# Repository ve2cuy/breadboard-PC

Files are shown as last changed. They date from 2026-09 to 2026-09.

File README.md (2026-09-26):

# breadboard-PC — an 8088 computer on a breadboard

A microcomputer with a PC/XT-inspired architecture, built on solderless breadboards around an
**Intel 8088**. Its ROM, whose source code is **written entirely in 8086 assembly language**, boots
into an interactive menu, runs two BASIC interpreters and **boots PC-DOS 2.1 and MS-DOS 3.30** from
floppy disk images.

A project by Alain Boudreault (VE2CUY), 2026. *[Version française](README_fr.md)*

<p align="center">
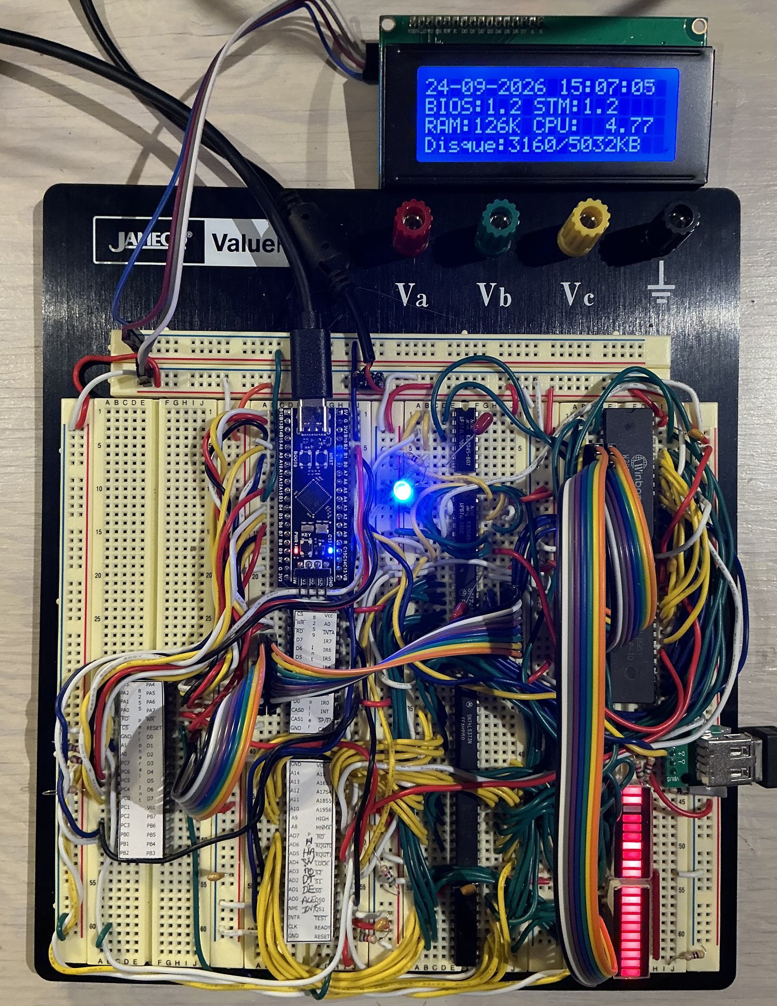
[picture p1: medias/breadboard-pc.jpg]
The breadboard build, with the LCD showing the Information screen
  <br>
  <em>The build: the Black Pill STM32F411 bridge (top centre), the 8088, the 8255, the 8259, the ROM and
  the RAM. The LCD shows the “Information” screen (date and time, versions, RAM, disk, speed).</em>
</p>

## At a glance

| | |
|---|---|
| **Processor** | Intel 8088, 4.77 MHz by default (adjustable from 1 to 10 MHz) |
| **Memory** | 256 KB ROM (W29C020C, `C0000h`–`FFFFFh`), 128 KB static RAM (HM628128, `00000h`–`1FFFFh`) |
| **I/O** | 8255A in mode 2 (bus to the bridge), 8259A (interrupts), 4×20 I2C LCD, PS/2 keyboard |
| **Bridge** | WeAct **Black Pill STM32F411** board: keyboard, USB terminal, LCD, clock, disk, RESET |
| **Software** | ROM written entirely in assembly (NASM, strict 8086 instruction set), both BASICs included: menu, BIOS for DOS, Tiny BASIC, GW-BASIC-style BASIC |
| **Operating systems** | PC-DOS 2.1 and MS-DOS 3.30, booted from a floppy disk image |

## The build

The core of the machine (processor, address latches, ROM, RAM, decoding) is wired on breadboards
with 74HC/74HCT logic and no programmable logic (no GAL, no CPLD). Address decoding takes only a few
NAND gates:

- **ROM**: `A19 = 1` (window `C0000h`–`FFFFFh`);
- **RAM**: `A19 = 0`;
- **8255** (ports `80h`–`83h`): `A7` and an I/O cycle;
- **8259** (ports `20h`–`21h`): `NAND(IO, A5)` (one gate of a 74LS00).

<p align="center">
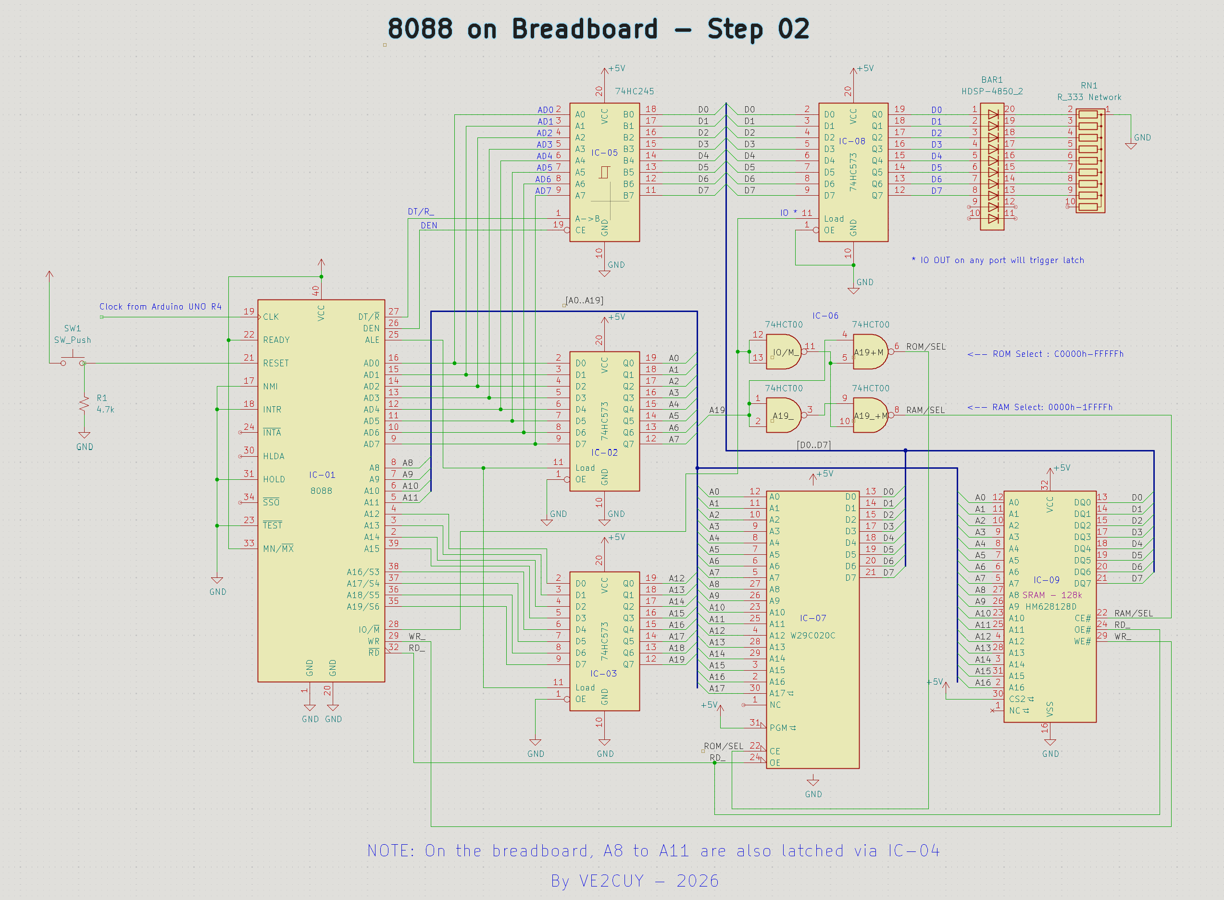
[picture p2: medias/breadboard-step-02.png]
KiCad schematic of the core: 8088, latches, ROM, RAM and decoding
  <br>
  <em>Schematic of the core (KiCad). The clock, supplied here by an Arduino UNO R4, now comes from the bridge.</em>
</p>

## The circuit

The 8088 does not bit-bang any peripheral. All traffic goes through **a single 8255 in mode 2**: an
8-bit bidirectional bus with hardware handshaking, connected to the bridge. Every byte received from
the bridge raises an interrupt (`IR1` of the 8259).

```mermaid
flowchart LR
    CPU["Intel 8088"] --- BUS(("Bus<br>A0-A19 / D0-D7"))
    BUS --- ROM["256 KB ROM<br>W29C020C"]
    BUS --- RAM["128 KB RAM<br>HM628128"]
    BUS --- PIO["8255A<br>mode 2"]
    BUS --- PIC["8259A"]
    PIO -- "INTR → IR1" --> PIC
    PIC -- INTR --> CPU
    PIO <== "Port A (8 bits) + handshake" ==> BRIDGE["Bridge<br>Black Pill STM32F411"]
    BRIDGE -- "CLK, RESET" --> CPU
    KBD["PS/2 keyboard"] --> BRIDGE
    BRIDGE <-- "USB (serial + drive)" --> PC["PC: terminal"]
    BRIDGE --> LCD["4×20 I2C LCD"]
    BRIDGE --- FLASH["8 MB flash<br>FAT16"]
```

The bridge wiring in detail (pins, 3.3 V / 5 V levels, pull-up resistors) is described (in French) in
[arduino/8088_bridge_stm32/README.md](arduino/8088_bridge_stm32/README.md).

## The STM32 bridge

The bridge firmware (a PlatformIO project, [arduino/8088_bridge_stm32](arduino/8088_bridge_stm32))
gives the 8088 the peripherals of a PC:

| Function | Details |
|---|---|
| **PS/2 keyboard** | Frame decoding; raw scan codes passed to the 8088 |
| **Terminal** | Native USB serial port to the PC (ANSI, 80 columns) |
| **Display** | 4×20 HD44780 LCD over I2C (PCF8574) |
| **Real-time clock** | STM32 RTC (32.768 kHz crystal): `TIME$`, `DATE$`, `INT 1Ah` |
| **Disk** | 8 MB W25Q64 SPI flash formatted FAT16: files, sectors, floppy images mounted as A: |
| **USB drive** | The flash is exposed to the PC as a USB drive (`USB ON` / `USB OFF`) to copy files onto it |
| **8088 clock** | `CLK` signal generated by hardware PWM, 1 to 10 MHz |
| **8088 RESET** | Held while the bridge starts up; **Ctrl-Alt-Del** (PS/2) or **Ctrl-\\** (terminal) |

The 8088 talks to the bridge through a command protocol on a dedicated channel
(see [Solution-01/lib/bridge.asm](Solution-01/lib/bridge.asm)).

## The menu

At power-up, the ROM displays a menu on both the terminal and the LCD. It can be driven from either
the PS/2 keyboard or the terminal; **Esc** returns to the main menu.

<p align="center">
  The ROM main menu on the terminal
</p>

| Menu | Options |
|---|---|
| **1) Basic** | Tiny BASIC; GW-BASIC-style BASIC |
| **2) Memory functions** | Memory dump and editing, CPU registers, code entry and execution, interrupt vector table, RAM test |
| **3) USB Disk** | USB drive toggle, file list, **booting a disk image** |
| **4) Configuration** | Clock speed, CPU speed test, date and time setting, information screen |

## BASIC

An original reimplementation inspired by GW-BASIC: same keywords, same error messages, integers,
single-precision floating point (in software) and strings. About 54 KB are free for programs.

<p align="center">
  BASIC session: a program, RUN and FRE(0)
</p>

| Category | Commands and functions |
|---|---|
| **Program** | `RUN` `LIST` `EDIT` `DELETE` `NEW` `CLEAR` `CONT` `TRON` `TROFF` `HELP` `SYSTEM` |
| **Control flow** | `IF…THEN…ELSE` `GOTO` `GOSUB`/`RETURN` `ON…GOTO/GOSUB` `FOR…NEXT` `WHILE…WEND` `END` `STOP` |
| **Data** | `LET` `DIM` `ERASE` `SWAP` `DATA`/`READ`/`RESTORE` `DEF FN` `DEFINT`/`DEFSNG`/`DEFSTR` |
| **Input/output** | `PRINT` `INPUT` `LINE INPUT` `INKEY$` `CLS` `LOCATE` `COLOR` `BEEP` |
| **Math** | `ABS` `SGN` `INT` `FIX` `SQR` `SIN` `COS` `TAN` `ATN` `LOG` `EXP` `RND` `RANDOMIZE` |
| **Strings** | `LEN` `LEFT$` `RIGHT$` `MID$` `INSTR` `CHR$` `ASC` `STR$` `VAL` `HEX$` `UCASE$` `STRING$` |
| **Files** | `SAVE` `LOAD` `MERGE` `FILES` `KILL` `FORMAT`; `OPEN` `PRINT #` `INPUT #` `EOF` `CLOSE` |
| **Clock** | `TIMER` `TIME$` `DATE$` (read and set the bridge RTC) |
| **Machine** | `PEEK` `POKE` `DEF SEG` `INP` `OUT` `WAIT` `CALL` `FRE` |
| **Disk and system** | `DSKREAD` `DSKWRITE` `USB ON`/`OFF` `BOOT "image.img"` |

## DOS 2.1 and DOS 3.3

The ROM provides the BIOS layer a DOS expects: disk (`INT 13h`, CHS and LBA), keyboard (`INT 16h`),
clock (`INT 1Ah`), text output to the terminal (`INT 10h`) and bootstrap (`INT 19h`). A floppy image
copied to the flash (through the USB drive) is mounted as drive **A:** and booted from
**USB Disk → 3) Boot disk image**, or with `BOOT "PCDOS2_1.IMG"` from BASIC. DOS writes go to the
image file.

<p align="center">
  Booting PC-DOS 2.1, VER and DIR /W<br>
  <em>PC-DOS 2.1: booting from the image (one dot per sector read), VER, DIR /W</em>
</p>

<p align="center">
  Booting MS-DOS 3.30, VER and DIR /W<br>
  <em>MS-DOS 3.30</em>
</p>

Limitations: 128 KB of RAM (DOS 5.0 and later require 256 KB), no video hardware (programs that write
to video memory display nothing), DOS keyboard input from the terminal only.

## Building the ROM

```sh
cd Solution-01
make            # solution-01.bin (256 KB, to be burned into the W29C020C); make rom-en for English
make check      # checks size, reset vector and signature
make test       # test benches under emulation (Unicorn)
make test-rom   # full ROM simulation: DOS, BASIC, PS/2 keyboard
```

Tools: NASM, GNU Make, Python 3 (+ `unicorn` for the tests); PlatformIO for the bridge
(`platformio run -e blackpill_f411ce_usbdrive -t upload`, board in DFU mode).

## Repository layout

| Folder | Contents |
|---|---|
| [Solution-01/](Solution-01) | 8088 ROM (NASM) and tests; full technical documentation (in French) in [Solution-01/README.md](Solution-01/README.md) |
| [arduino/8088_bridge_stm32/](arduino/8088_bridge_stm32) | Firmware of the Black Pill STM32F411 bridge (PlatformIO) |
| [kicad/](kicad) | Schematics of the build |
| [PC-DOS/](PC-DOS) | Test floppy disk images |
| [medias/](medias) | Datasheets, schematics and screenshots |

> The terminal screenshots on this page are produced by the actual (English) ROM, running in the
> project's simulator ([medias/captures/generer.py](medias/captures/generer.py)).

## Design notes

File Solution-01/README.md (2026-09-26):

# Solution-01 — 8088/8086 sur breadboard (VE2CUY)

Firmware ROM pour un ordinateur 8088/8086 assemblé sur breadboard par
Alain Boudreault (VE2CUY). Au démarrage, la carte :

1. affiche un écran de démarrage sur le LCD I2C 4×20 pendant 1 seconde ;
2. affiche un **menu interactif** (UART + LCD I2C), piloté au **clavier
   PS/2 ou au terminal UART du PC** (les deux sont équivalents), qui
   reste le comportement normal de la carte tant qu'elle est sous
   tension — voir [Menu interactif](#menu-interactif) ci-dessous pour
   la structure complète.

**Architecture « pont »** : le 8088 ne pilote plus aucun périphérique
en bit-bang. Une plaquette **WeAct Black Pill V3.1 (STM32F411)** — le
**pont** — décode le clavier PS/2, présente au PC un port série par son
USB natif et possède le bus I2C du LCD, la RTC, le disque (flash SPI de
8 Mo), l'horloge et le RESET du 8088 ; le 8088 ne lui
parle que par **un 8255 en mode 2** (un seul bus de 8 bits
bidirectionnel avec poignée de main matérielle) et reçoit ses octets par
une **interruption matérielle** du 8259 — voir
[Pont STM32](#pont-stm32-8255-en-mode-2). Le firmware du pont est le
projet PlatformIO `../arduino/8088_bridge_stm32/` (dépôt Git, à côté de
`Solution-01/`). À l'origine, le pont était un **Arduino UNO**
(`../arduino/ve2cuy_bridge/`, conservé pour l'historique ; même protocole
côté 8088, mais sans RTC, disque, horloge ni RESET) — d'où le nom du
dossier `arduino/` et de quelques identifiants du firmware (`arduino_send`,
`irq1_arduino_handler`, `ARD_*`).

⚠️ Le pilote du LCD **parallèle** (`lib/lcd.asm`) reste dans le dépôt
(historique) mais plus aucun code du firmware ne l'appelle : il écrirait
sur le Port A, qui est maintenant le bus du pont.

Contrairement aux versions précédentes, il n'y a plus de « power-on
self-test » (POST) qui s'enchaîne automatiquement — chaque test (RAM,
dump ROM/RAM, édition de la RAM, registres, IVT, Tiny BASIC, BASIC) est déclenché
explicitement depuis le menu. Un clavier (PS/2 **ou** terminal UART) est
donc **requis** pour que la carte fasse quoi que ce soit après le
splash.

## Matériel visé

- CPU 8088/8086 (le code est écrit pour être compatible 8086 strict —
  voir `CPU 8086` dans `solution-01.asm` — mais ciblé pour tourner sur
  un vrai 8088)
- ROM 256 Ko, mappée à l'adresse physique `C0000h-FFFFFh`
- RAM statique 128 Ko
- Un **8259A** (contrôleur d'interruptions) : ports `20h`/`21h` (comme le
  PC/XT), `CS#` décodé par une porte NAND (74LS00) sur `IO` et `A5`. `IR0` =
  bouton-poussoir de test, `IR1` = `INTR` du 8255 (octet reçu du
  pont). Détails : [Interruptions matérielles](#interruptions-matérielles-8259)
- Un **8255** (PIO, ports `80h-83h`) en **mode 2** — voir
  [Pont STM32](#pont-stm32-8255-en-mode-2)
- Une plaquette **WeAct Black Pill V3.1** (STM32F411CEU6, 100 MHz, USB
  natif) — le **pont** — qui porte les périphériques :
  - clavier PS/2 (`CLK`/`DATA` sur le pont, **pas** sur le 8255) ;
  - terminal du PC = port série **USB** natif de la plaquette (débit sans
    objet ; ouvrir le port ne réinitialise pas la carte) ;
  - LCD I2C HD44780 4×20 (expandeur PCF8574, adresse `0x27`, ou `0x3F`
    pour un PCF8574A) sur `PB10`/`PB3` (I2C2) ;
  - RTC (quartz LSE de la carte), disque (flash SPI W25Q64 de 8 Mo,
    FAT16), horloge du 8088 (PWM, 1-10 MHz) et RESET du 8088.
- **Câblage pont ↔ 8255/8088** (détails, niveaux 3,3 V / 5 V et
  vérifications : `../arduino/8088_bridge_stm32/README.md`) :

| Black Pill | Signal | Côté 8088 |
|---|---|---|
| `PB12` `PB13` `PB14` `PB15` | bus de données | `PA0` `PA1` `PA2` `PA3` |
| `PB6` `PB7` `PB8` `PB9` | bus de données | `PA4` `PA5` `PA6` `PA7` (quartet haut inversé sur le montage, corrigé en logiciel : `BUS_HIGH_NIBBLE_REVERSED`) |
| `PB0` | `ACK#` (sortie drain ouvert du pont) | `PC6` |
| `PB1` | `STB#` (sortie drain ouvert du pont) | `PC4` |
| `PA8` | `OBF#` (entrée du pont) | `PC7` |
| `PA15` | `IBF` (entrée du pont, facultative : `USE_IBF`) | `PC5` |
| `PB4` | étiquette `TAG` de l'octet envoyé au 8088 | `PC0` (entrée du 8255) |
| `PB5` | étiquette `TAG1` (réponse à une commande) | `PC1` (10 kΩ vers la masse) |
| `PA9` `PA10` | canal de l'octet reçu du 8088 | `PB0` `PB1` |
| `PA3` | horloge (PWM `TIM2` canal 4) | `CLK` (broche 19) du 8088 |
| `PB2` | RESET (actif haut ; entrée au repos) | `RESET` (broche 21) du 8088 |
| `PA1` `PA2` | `CLK` / `DATA` du clavier PS/2 | — |
| `PB3` `PB10` | `SDA` / `SCL` du LCD I2C | — |
| — | `INTR` du 8255 | `PC3` → `IR1` du 8259 |

  `PA11`/`PA12` sont réservées à l'USB. Résistances de tirage : 10 kΩ vers
  +5 V sur `STB#`/`ACK#` (drain ouvert : vrai niveau haut à 5 V, lignes
  hautes pendant un reset ou une reprogrammation du STM32), 4,7-10 kΩ
  vers +5 V sur `CLK`/`DATA` du PS/2. Masse commune avec le 8088.

> **Câblage USB → PS/2** (pour un clavier/câble USB adapté en PS/2) :
> `VBUS`→`+5V`, `D−`→`Data`, `D+`→`Clock`, `GND`→`GND`. Fonctionne avec
> tout clavier USB à repli PS/2 (confirmé sur ce montage) — pas avec
> un clavier USB « pur » sans ce repli.

## Schéma bloc du circuit électronique

Décodage d'adresses (logique simple, sans décodeur dédié — un seul
bit d'adresse suffit à distinguer ROM/RAM, la sélection des circuits
d'E/S se faisant sur le bus d'E/S) :

- **ROM** : `CS = A19`
- **RAM** : `CS = NOT A19`
- **8255 (PIO)** : `CS = A7 AND IO/M` (cycle d'E/S, adresse ≥ 80h —
  `A0`/`A1` vont directement aux broches `A0`/`A1` du 8255 pour
  sélectionner Port A/B/C/registre de commande — voir `PORTA`/`PORTB`/
  `PORTC`/`PIO` dans `include/hardware.inc`, ports 80h-83h)
- **8259 (PIC)** : `CS#` par NAND(`IO`, `A5`) (une porte de 74LS00) — ports `20h`/`21h`

```mermaid
flowchart TD
    subgraph CPU["CPU 8088/8086"]
        AB["Bus d'adresses A0-A19"]
        DB["Bus de donnees D0-D7"]
        IOM["IO/M (cycle E/S vs memoire)"]
    end

    subgraph DEC["Decodage d'adresses"]
        A19G["A19"]
        NOTA19["NOT A19"]
        A7IO["A7 AND IO/M"]
        PICCS["NAND(IO, A5)"]
    end

    subgraph MEM["Memoire"]
        ROM["ROM 256 Ko\nC0000h-FFFFFh\nCS = A19"]
        RAM["RAM statique 128 Ko\n00000h-1FFFFh\nCS = NOT A19"]
    end

    subgraph IOBLK["Entrees/Sorties"]
        PIO["8255 PIO - mode 2\nPorts 80h-83h\nPort A = bus 8 bits bidirectionnel"]
        PIC["8259 PIC\nPorts 20h-21h"]
    end

    ARD["Pont Black Pill STM32F411\n(PS/2, UART USB, LCD I2C,\nRTC, disque, CLK, RESET)"]
    PS2["Clavier PS/2"]
    PC["PC - terminal (port serie USB)"]
    LCD["LCD I2C 4x20\n(PCF8574)"]
    BTN["Bouton-poussoir de test (IR0)"]

    AB --> A19G
    A19G --> NOTA19
    AB --> A7IO
    IOM --> A7IO
    AB --> PICCS
    IOM --> PICCS

    A19G -->|CS| ROM
    NOTA19 -->|CS| RAM
    A7IO -->|CS| PIO
    PICCS -->|CS| PIC

    DB --- ROM
    DB --- RAM
    DB --- PIO
    DB --- PIC

    PIO <-->|"Port A (8 bits), Port B (canal), Port C (poignee de main)"| ARD
    PIO -->|"INTR (PC3)"| PIC
    BTN --> PIC
    PIC -->|INTR| CPU
    PS2 --> ARD
    ARD <--> PC
    ARD --> LCD
```

⚠️ Note : la sélection de la ROM ne dépend que de `A19` (pas de
`A18`) — la ROM physique (256 Ko = `A0-A17`) est donc mise en miroir
sur les 512 Ko de la moitié haute de l'espace mémoire (`80000h-FFFFFh`)
si `A18` n'est câblé nulle part ailleurs ; le firmware n'utilise que
la fenêtre `C0000h-FFFFFh`. Même remarque pour la RAM (128 Ko, moitié
basse de 1 Mo) : seuls `00000h-1FFFFh` sont réellement testés par
`test_ram` (voir `solution-01.asm`).

## Pont STM32 (8255 en mode 2)

Le 8255 est programmé par `init_8255` avec le mot de mode `C1h`
(`MASQUE_PIO`, `include/hardware.inc`) : **Port A en mode 2**, Port B en
sortie (mode 0), `PC0`-`PC2` en entrée. Le mode 2 fournit un bus de 8 bits
**bidirectionnel** avec une poignée de main matérielle sur le Port C, et
le 8255 ne pilote le bus **que pendant `ACK#` bas** — aucun conflit
possible avec le pont.

| Signal | Rôle |
|---|---|
| Port A (`PA0-PA7`) | bus de données, dans les deux sens |
| Port B (`PB0`/`PB1`) | **canal** de l'octet que le 8088 envoie : `0` = octet UART (`PB_CHAN_UART`), `1` = commande LCD (`PB_CHAN_LCD_CMD`), `2` = donnée LCD (`PB_CHAN_LCD_DATA`), `3` = **commande pour le pont** (`PB_CHAN_CMD`, horloge RTC : voir `lib/bridge.asm`) |
| `PC7` `OBF#` | 8088 → pont : `0` = un octet attend (le 8255 le repasse à `1` dès que le pont abaisse `ACK#`) |
| `PC6` `ACK#` | pont → 8255 : le pont le pulse pour lire l'octet |
| `PC4` `STB#` | pont → 8255 : impulsion qui verrouille l'octet à destination du 8088 |
| `PC5` `IBF` | octet reçu du pont pas encore lu (aussi lue par le pont : `USE_IBF`) |
| `PC3` `INTR` | câblée sur `IR1` du 8259 (`INTE2` actif, `INTE1` inactif) |
| `PC0` | étiquette posée par le pont : `0` = scan code clavier, `1` = octet UART reçu |
| `PC1` | étiquette `TAG1` : `1` = l'octet est une **réponse** à une commande du canal 3 (prioritaire sur `PC0`). `PC1` doit être reliée à la sortie `TAG1` du pont et **tirée à 0 par 10 kΩ**. Elle n'est lue que **pendant une commande** (`BRIDGE_EXPECT_OFF`) : non câblée, elle ne perturbe pas le clavier ni l'UART, mais un octet tapé pendant la lecture de l'heure (~ 10 ms) risque d'être pris pour une réponse |

**8088 → pont** (`arduino_send`, `lib/common.asm`) : pose le canal sur
le Port B puis écrit l'octet sur le Port A (les deux `OUT` sous
`pushf`/`cli`/`popf`). **Contrôle de flux** : elle attend d'abord `OBF#`
à `1`. Pour ne jamais bloquer le boot sans pont : `ARD_UNKNOWN` (rien
consommé depuis le reset) attend jusqu'à ~3 s (délai hérité de l'UNO, qui
mettait 1-2 s à démarrer ; le pont STM32 tient le 8088 en RESET
jusqu'à ce qu'il soit prêt), `ARD_ALIVE` ~0,5 s puis passe à `ARD_ABSENT`, qui n'attend
plus (l'octet est perdu) jusqu'à revoir `OBF#` à `1`. Tous les affichages
(UART et LCD) passent par cette seule routine ; l'ordre est conservé
(une seule file côté pont).

**Commandes du pont (canal 3, `lib/bridge.asm`)** : le 8088
envoie sur le canal 3 un octet d'opération puis ses arguments ; le pont répond par
des octets étiquetés `PC1 = 1`, que `irq1_arduino_handler` range dans un tampon
circulaire (`BRIDGE_RX_*`, `bridge_rx_get` avec délai). `00h` PING (réponse `B1h`,
version, capacités), `01h` LIRE l'heure (8 octets : année sur 2 octets, mois, jour,
heures, minutes, secondes, centièmes), `02h` + 7 octets RÉGLER l'heure. Un pont qui ne
répond pas (ancien pont UNO : aucune commande) : `rtc_get` rend `CF = 1` (`Device Timeout` en BASIC). Le **disque** utilise les codes `10h`-`19h` (statut, formater, ouvrir, lire 1-32 octets, écrire 1-32 octets, fermer, répertoire début/suivant, supprimer, espace libre ; les routines `fs_*` de `lib/bridge.asm`) ; le tampon des réponses (`BRIDGE_RX_*`) fait 64 octets.

**Pont → 8088** : le pont pose l'étiquette (`PC0`) et l'octet, puis
pulse `STB#`. `INTR` déclenche `irq1_arduino_handler` (`INT 09h`) : elle
lit le Port C (`IBF` confirme qu'un octet est là, `PC0` donne l'origine),
lit le Port A (ce qui acquitte le 8255) puis enfile l'octet dans le
tampon circulaire du clavier (`ps2_rx_push`) ou de l'UART
(`uart_rx_push`), envoie l'EOI et fait `IRET`. Une lecture de `PORTA`
juste avant le `sti` de `start:` vide un éventuel octet arrivé avant
l'initialisation du 8259 (`INTR` reste haute tant que le Port A n'est pas
lu et le 8259 est déclenché par front).

**Côté pont** (`../arduino/8088_bridge_stm32/src/main.cpp`, détails dans
le `README.md` de ce dossier) :

- **8255 → périphériques** : file de 256 entrées ; UART → port série USB,
  LCD → I2C2 (init 4 bits complète au démarrage, attente 2 ms pour
  Clear/Home), canal 3 → interpréteur de commandes (RTC, disque, horloge,
  version). Chaque commande `28h` (Function Set, début de
  `i2c_lcd_init` côté 8088) rejoue l'initialisation « par instruction »
  (`lcdResync`) pour récupérer un LCD déréglé.
- **Lecture du bus** : `OBF#` repasse à `1` dès que `ACK#` *descend*, et le
  8088 peut alors écrire l'octet suivant : le pont prend donc un
  **instantané** de `GPIOA->IDR`/`GPIOB->IDR` — canal et octet — puis
  relâche `ACK#`.
- **Clavier PS/2** : interruption `EXTI1` sur chaque front descendant de
  `CLK`. Filtre anti-parasite (`CLK` doit rester basse `PS2_GLITCH_US` =
  10 µs), `DATA` par vote majoritaire de 3 lectures, resynchronisation
  après `PS2_FRAME_GAP_US` = 250 µs sans front, contrôle start/parité
  impaire/stop.
- **Aucun accès au bus pendant une trame PS/2** : le pont n'envoie un
  octet clavier qu'après `KBD_QUIET_US` = 3 ms sans front `CLK` (fin de la
  rafale `F0` + code) et n'acquitte/n'envoie le reste qu'après
  `BUS_QUIET_US` = 0,4 ms. Sans cela, les impulsions `STB#`/`ACK#`
  perturbaient la trame suivante (touche perdue, la suivante avalée).
- **Contrôle de flux** : avec `IBF` câblée (`USE_IBF`), le pont n'envoie
  un octet que si le 8088 a lu le précédent, plus `GAP_US` = 1 ms d'espace
  minimal entre deux octets (`REPLY_GAP_US` pour les réponses aux
  commandes).

Réglages principaux en tête de `main.cpp` (liste complète dans le
`README.md` du pont) :

| Constante | Défaut | Rôle |
|---|---|---|
| `LCD_ADDR` | `0x27` | adresse I2C du PCF8574 (`0x3F` pour un PCF8574A) |
| `USE_IBF` | 1 | `IBF` (`PC5`) câblée sur `PA15` |
| `GAP_US` | 1000 | espace minimal entre deux octets pont → 8088 |
| `LINE_DELAY_MS` | 15 | pause après chaque `CR` venant du PC (collage de code BASIC) |
| `KBD_QUIET_US` / `BUS_QUIET_US` | 3000 / 400 | silence `CLK` avant d'agir sur le bus |
| `DEBUG_PS2` | 0 | `1` = trace PS/2 sur le terminal (voir ci-dessous) |

**Trace `DEBUG_PS2=1`** (entrelacée avec la sortie du 8088, à n'utiliser
que pour diagnostiquer) : `{76}` octet décodé, `{>76}` octet envoyé au
8088, `{P76}`/`{S76}` erreur de parité/de stop, `{G}` start parasite,
`{Rn}` resynchronisation à `n` bits, `{O}` file PS/2 pleine, `{g}`
parasite filtré.

**Compilation et téléversement** (PlatformIO ; plaquette en mode DFU :
tenir `BOOT0`, appuyer sur `NRST`, relâcher) :

```sh
cd arduino/8088_bridge_stm32
platformio run -e blackpill_f411ce_usbdrive -t upload
```

Ouvrir le port série USB **ne réinitialise pas** le pont (contrairement à
l'ancien UNO). Le terminal doit interpréter
l'ANSI (PuTTY, Tera Term, minicom…), faire au moins 24 lignes × 80
colonnes, avoir l'**écho local désactivé** (c'est le 8088 qui fait
l'écho) et envoyer Entrée en `CR`.

## Interruptions matérielles (8259)

`init_8259` programme le 8259A en mode PC/XT : déclenchement par
**front**, 8259 unique (pas d'`ICW3`), mode 8086, **EOI manuel**, vecteurs
`IR0`-`IR7` → `INT 08h`-`0Fh`. Masque `OCW1` = `11111100b` : seules `IR0` et
`IR1` sont démasquées (les autres lignes, non câblées, resteraient
flottantes).

| Ligne | Vecteur | Gestionnaire | Rôle |
|---|---|---|---|
| `IR0` | `INT 08h` | `irq0_test_handler` | bouton-poussoir de test : affiche un message sur l'UART |
| `IR1` | `INT 09h` | `irq1_arduino_handler` | `INTR` du 8255 : scan code clavier, octet UART reçu **ou** réponse du pont (voir [Pont STM32](#pont-stm32-8255-en-mode-2)) |

`IR4` (UART, convention PC/XT) n'est **pas** utilisée : il n'y avait plus
de broche libre sur le pont d'origine (Arduino UNO), l'UART reçu passe donc lui aussi par `IR1`.
La réception est pilotée par interruption ; la **lecture** ne l'est pas :
`ps2_get_char` scrute les deux tampons circulaires (16 octets pour le clavier PS/2, 256 pour l'UART).

Deux règles à respecter pour que le clavier ne perde pas d'octets :
l'instruction `INT` met `IF` à 0, donc `int10h_handler` et
`int16h_handler` font un `sti` dès leur entrée (le 8255 ne retient qu'un
octet reçu, un affichage peut attendre `OBF#` ~1 ms) ; et tout `cli` doit
être suivi d'un `popf`/`sti` (`test_ram` restaure `IF` par `pushf`/`popf`).

## Structure du dossier

```
breadboard-PC/                  (racine du dépôt Git)
├── README.md                   Page d'accueil du dépôt (anglais)
├── README_fr.md                Page d'accueil en français (même contenu que README.md)
├── medias/                     Datasheets, schémas, photo du montage
│   └── captures/               Captures du terminal des pages d'accueil (SVG) et
│                                generer.py, qui les produit avec rom_sim.py
├── code-examples/              Exemples : hello.asm (programme DOS, INT 10h),
│                                sin.bas (courbe de SIN en ASCII, BASIC)
├── kicad/                      Schémas KiCad du montage
│   └── 3dmodels/               Modèle 3D (STEP/VRML) du support ZIF 32 broches 3M Textool
│                                232-1285-00-0602J et son générateur CadQuery
├── PC-DOS/                     Images de disquette de test (PC-DOS 2.1, MS-DOS 3.30)
├── arduino/
│   ├── 8088_bridge_stm32/  Firmware du pont : WeAct Black Pill V3.1 (STM32F411), PlatformIO
│   ├── ve2cuy_bridge/      Ancien pont Arduino UNO (historique, remplacé par le précédent)
│   └── irq_test/           Ancien test de branchement IR1/IR4 (obsolète)
└── Solution-01/
    ├── solution-01.asm     Flux principal (start, menus, éditeur RAM,
    │                        registres, IVT, gestionnaires INT/IRQ) +
    │                        tous les textes/données
    ├── Directives.md       Cahier des charges et journal du projet
    ├── Makefile            Automatise l'assemblage (voir Makefile.md)
    ├── Makefile.md         Explication détaillée du Makefile
    ├── tests/              Bancs d'essai sous émulateur (Unicorn)
    │   ├── tb_test.asm     Tiny BASIC : harnais assemblé avec lib/tiny_basic.asm
    │   ├── tb_test.py      (sorties BASIC, retour au menu, écritures)
    │   ├── fl_test.asm/.py Bibliothèque flottante (comparée à numpy.float32)
    │   ├── basic_test.asm  BASIC : harnais assemblé avec lib/basic.asm
    │   ├── basic_harness.py  émulateur, E/S UART simulées, garde d'écritures
    │   ├── basic_test.py   scénarios du BASIC (make test)
    │   ├── rom_sim.py      ROM complète / BIOS avec IRQ1 asynchrones (8255, 8259, ISR)
    │   ├── rom_test.py     scénarios DOS, trace, Ctrl-\, clavier PS/2, collage (make test-rom)
    │   └── scenario_dos21.txt  exemple de scénario pour rom_sim.py en ligne de commande
    ├── check_rom.py        Validation structurelle du .bin assemblé
    ├── .gitignore          Ignore build/ (fichiers jetables de check-modules)
    ├── include/
    │   ├── hardware.inc    Constantes matérielles (8255 mode 2, 8259,
    │   │                   adresses RAM des variables partagées)
    │   ├── delay.inc       Macro `delay_ms` (voir lib/utils.asm)
    │   └── lcd_macros.inc  Macros `lcd_goto`/`lcd_show`/`i2c_lcd_goto`/
    │                       `i2c_lcd_show` + `gotoxy`/`print` (INT 10h -
    │                       voir plus bas)
    └── lib/
        ├── common.asm      `arduino_send` (8088 → pont, contrôle de
        │                   flux OBF#), `porta_write` (historique, LCD
        │                   parallèle) + hex_table
        ├── lcd.asm         Pilote du LCD parallèle (historique, inutilisé)
        ├── uart.asm        UART via le pont (TX, RX, décimal, ANSI)
        ├── utils.asm       delay_ms_proc (routine derrière la macro)
        ├── lcd_i2c.asm     LCD I2C via le pont (commande/donnée HD44780)
        ├── ps2.asm         Clavier PS/2 + terminal UART : ps2_get_char, ps2_poll_char
        ├── tiny_basic.asm  Interpréteur Tiny BASIC (sous-menu Basic, option 1)
        ├── basic.asm       BASIC « GW-BASIC-like » (sous-menu Basic, option 2) : cœur, tokeniseur ;
        │   basic_tokens.inc, basic_float.asm, basic_fmath.asm, basic_eval.asm,
        │   basic_str.asm, basic_stmt.asm, basic_func.asm, basic_data.asm
        └── bin/            (généré) lcd.bin, uart.bin, lcd_i2c.bin, ps2.bin
```

Fichiers générés par `make` (non versionnés, voir `.gitignore`) :
`solution-01.bin`, `lib/bin/lcd.bin`, `lib/bin/uart.bin`,
`lib/utils.bin`, `lib/bin/lcd_i2c.bin`, `lib/bin/ps2.bin`, `lib/bin/tiny_basic.bin`,
`lib/bin/basic.bin`, `build/check/*.bin`, `build/*_test*.bin`.

**Règle importante** : tous les `%include` du projet sont écrits comme
des chemins relatifs à la racine `Solution-01/`, jamais
relatifs au fichier qui fait le `%include` — NASM résout les chemins
par rapport au répertoire courant au moment de l'assemblage. Il faut
donc toujours lancer `nasm`/`make` **depuis ce dossier**, jamais depuis
un sous-dossier.

## Fonctions d'accès au LCD parallèle (`lib/lcd.asm`) — historique

⚠️ **Plus utilisé** : aucun code du firmware n'écrit sur le LCD parallèle
(tout l'affichage passe par le LCD I2C, via le pont). Le fichier reste
dans le dépôt ; il écrit sur le Port A via `porta_write`, donc **ne pas
l'appeler** : le Port A est maintenant le bus du pont. Ses délais
(`lcd_delay`…) ne servent plus non plus à `lib/lcd_i2c.asm`.

| Fonction | Rôle |
|---|---|
| `lcd_init` / `lcd_command` / `lcd_data` / `lcd_strobe` / `lcd_print` | Pilote HD44780 4 bits (historique) |
| `lcd_tx_hex_nibble` / `lcd_tx_hex_byte` / `lcd_tx_hex_word` / `lcd_tx_dec3` | Affichage hexadécimal/décimal (historique) |
| `lcd_short_delai` / `lcd_delay` / `lcd_delay_long` / `lcd_powerup_delay` | Délais HD44780 (historique) |

## Fonctions d'accès à l'UART (`lib/uart.asm`)

UART « relayé » par le pont : le port série **USB** du pont (vers
le PC) gère le cadencement — aucune temporisation liée au débit ni à
l'horloge du 8088.

| Fonction | Rôle |
|---|---|
| `uart_tx_string` | Transmet une chaîne terminée par `0` depuis `DS:SI` |
| `uart_tx_byte` | Envoie `AL` au pont sur le canal `PB_CHAN_UART` (`arduino_send` : contrôle de flux `OBF#`). **Préserve tous les registres** |
| `uart_tx_hex_nibble` / `uart_tx_hex_byte` / `uart_tx_hex_word` | Affiche une valeur en hexadécimal majuscule (entrée : `AL` ou `AX`) — générées par `def_tx_hex_nibble`/`byte`/`word` |
| `uart_tx_bin_word` | Affiche `AX` en binaire (16 caractères) |
| `uart_tx_dec8` | Affiche `AL` en décimal, sans zéros de tête |
| `uart_ansi_goto` | Positionne le curseur du terminal (`ESC [ ligne ; colonne H`), `DH` = ligne, `DL` = colonne (1-based) |
| `uart_rx_push` | Appelée par `irq1_arduino_handler` : enfile un octet UART reçu (tampon circulaire de 256 octets, `0FD00h`) |
| `uart_rx_available` | `CF`=0 si un octet UART attend, non bloquante |
| `uart_rx_byte` | Retire un octet du tampon (bloque tant qu'il est vide), préserve `BP` |

## Fonctions d'accès au LCD I2C (`lib/lcd_i2c.asm`)

LCD HD44780 4×20 derrière un PCF8574. Le 8088 **ne parle plus I2C** : il
envoie au pont des octets HD44780 complets (même encodage standard
qu'avant : `01h` = clear, `28h` = function set, `80h+adresse` = curseur…),
sur le canal `PB_CHAN_LCD_CMD` (RS=0) ou `PB_CHAN_LCD_DATA` (RS=1). Le pont
possède la séquence de démarrage 4 bits, le découpage en quartets, le
protocole I2C et les délais d'exécution du contrôleur : **le 8088 n'a plus
aucun délai à respecter** — le contrôle de flux `OBF#` l'arrête si
le pont prend du retard. Résultat : un octet LCD = 3 écritures de port
au lieu d'une transaction I2C bit-bang de plusieurs centaines de µs.

| Fonction | Rôle |
|---|---|
| `i2c_lcd_init` | Envoie Function Set / Display ON / Entry Mode / Clear (le pont resynchronise le LCD sur le Function Set) |
| `i2c_lcd_command` / `i2c_lcd_data` | Envoie un octet complet (entrée : `AL`) — RS=0 / RS=1 |
| `i2c_lcd_send_byte` | Choisit le canal selon `BL` (bit 0 = RS) et appelle `arduino_send` |
| `i2c_lcd_print` | Affiche une chaîne terminée par `0` depuis `DS:SI` |
| `i2c_lcd_tx_hex_nibble` / `i2c_lcd_tx_hex_byte` / `i2c_lcd_tx_hex_word` | Affiche une valeur en hexadécimal majuscule (entrée : `AL`/`AX`) — générées par `def_tx_hex_*` |
| `i2c_lcd_tx_dec3` | Affiche `AX` (0-999) en décimal, toujours sur 3 chiffres |

Positionnement DDRAM : voir les macros `i2c_lcd_goto`/`i2c_lcd_show`
ci-dessous. Toutes ces routines préservent leurs registres (comme
`uart_tx_byte`).

## Macros de refactoring

Plusieurs familles de procédures quasi identiques (LCD parallèle, LCD
I2C, UART) ont été remplacées par des macros NASM — même comportement,
code source bien plus compact. Aucun changement fonctionnel : les
octets assemblés sont identiques pour les générateurs (`def_tx_hex_*`,
`def_busy_delay`, `lcd_text`) et légèrement plus nombreux mais
équivalents pour les macros inline (`lcd_goto`/`lcd_show`,
`ascii_or_dot`), qui remplacent un `call` vers une procédure partagée
par du code répété à chaque site d'appel.

| Macro | Fichier | Remplace | Rôle |
|---|---|---|---|
| `lcd_goto LCD_LINEn` | `include/lcd_macros.inc` | `call lcd_line1`…`lcd_line4` | Positionne le curseur DDRAM (LCD parallèle) |
| `lcd_show LCD_LINEn` | `include/lcd_macros.inc` | `call lcd_show_line1`…`lcd_show_line4` | `lcd_goto` + `lcd_print` (entrée : `DS:SI`) |
| `i2c_lcd_goto LCD_LINEn` | `include/lcd_macros.inc` | `call i2c_lcd_line1`…`i2c_lcd_line4` | Positionne le curseur DDRAM (LCD I2C) |
| `i2c_lcd_show LCD_LINEn` | `include/lcd_macros.inc` | `call i2c_lcd_show_line1`…`i2c_lcd_show_line4` | `i2c_lcd_goto` + `i2c_lcd_print` |
| `def_tx_hex_nibble`/`byte`/`word` `nom, proc_emission` | `lib/common.asm` | 8 procédures dupliquées (LCD/UART/LCD-I2C) | **Génère** une procédure d'affichage hexadécimal appelant `proc_emission` pour chaque caractère |
| `def_busy_delay nom, N` | `lib/common.asm` | procédures dupliquées (`lcd_short_delai`, `lcd_delay`, `lcd_delay_long`, `delay_ms`…) | **Génère** une boucle d'attente active (`dec bx`/`jnz`) de `N` itérations |
| `lcd_text label, 'texte', largeur` | `solution-01.asm` | ~15 blocs `db`+`times`+`db 0` dupliqués | **Génère** un texte LCD complété par des espaces à `largeur` colonnes, terminé par `0` |
| `ascii_or_dot` | `solution-01.asm` | Logique dupliquée dans le dump UART et `i2c_dump_hex_ascii8_line` | Remplace `AL` par `.` s'il n'est pas imprimable (`< 20h` ou `> 7Eh`) |
| `i2c_dump_hex4` | `solution-01.asm` | Boucle hexa dupliquée entre `i2c_dump_hex_only_line` et `i2c_dump_hex_ascii8_line` | Affiche 4 octets hexa (`ES:DI`), avance `DI` de 4 |

`lcd_goto`/`lcd_show`/`i2c_lcd_goto`/`i2c_lcd_show` sont incluses **avant**
`start:` (`include/lcd_macros.inc`, comme `delay.inc`, n'émet aucun octet)
— contrairement à un `call`, une invocation de macro doit être
textuellement définie avant son premier usage, alors que les procédures
réelles (`lcd_command`, `i2c_lcd_print`, …) restent définies dans
`lib/lcd.asm`/`lib/lcd_i2c.asm`, inclus après tout le code (voir la
note dans `solution-01.asm` sur le vecteur de reset).

### Affichage du dump mémoire sur le LCD I2C

`dump_line` affiche les 16 octets de **chaque ligne** d'un dump
mémoire (`dump_memory_action`) sur le LCD I2C — 4 octets par ligne sur
les 4 lignes du LCD 4×20 :
- **Lignes 1 et 3** (`i2c_dump_hex_ascii8_line`) : `"XX XX XX XX "` (ses
  4 octets, en hexadécimal) puis **8 caractères ASCII** — ceux de ce
  groupe de 4 octets **et** du suivant (`.` pour les non imprimables,
  même règle que le dump UART) — soit `"XX XX XX XX ASCIIIII"` = 20
  des 20 colonnes, pleine largeur.
- **Lignes 2 et 4** (`i2c_dump_hex_only_line`) : `"XX XX XX XX"`
  seulement (hexadécimal, sans ASCII — déjà couvert par la ligne
  précédente).

Ce format (à l'origine un test de performance/stress du LCD I2C,
conditionnel via `%ifdef TEST_I2C_DUMP`) est devenu l'affichage LCD
**permanent** de `dump_line` depuis le passage complet du LCD
parallèle au LCD I2C — la directive `TEST_I2C_DUMP` a été retirée.

## Fonctions d'accès au clavier PS/2 et au terminal UART (`lib/ps2.asm`)

Le clavier PS/2 est décodé par le **pont** (trame de 11 bits : start,
8 données, parité impaire, stop — voir [Pont STM32](#pont-stm32-8255-en-mode-2)),
qui envoie au 8088 le **scan code brut** (Set 2) : le 8088 ne fait plus
aucun bit-bang. `irq1_arduino_handler` enfile chaque octet dans un
tampon circulaire de 16 octets (`PS2_RX_BUF_OFF`) ; `ps2_read_byte` le
vide. `ps2_read_byte` garde le contrat historique (`AL` = octet, `CF` = 0
toujours puisque le pont a déjà validé la trame).

**Le terminal UART vaut le clavier** : `ps2_get_char` consulte aussi le
tampon UART (`uart_get_key`), donc **tous** les menus, saisies hexadécimales
et éditeurs acceptent indifféremment le clavier PS/2 et le terminal du PC.
Règles de traduction du terminal (mêmes résultats que la touche PS/2
équivalente, `BH` = 0) :

- chiffres `0-9`, lettres `A-F`/`Q`/`R` (minuscules acceptées, converties en
  majuscules), Entrée (`CR`), Retour arrière (`BS` ou `DEL`), Échap ;
- **flèches** par séquences ANSI `ESC [ A/B/C/D` (ou `ESC O A/B/C/D`) →
  `PS2_KEY_UP`/`DOWN`/`RIGHT`/`LEFT` ; les autres séquences
  (`ESC [ … ~`) sont consommées en entier et ignorées ;
- un `ESC` **seul** (rien dans les ~50 ms qui suivent,
  `UART_ESC_TIMEOUT`) est la touche Échap ; tout le reste (dont `LF`) est
  ignoré.

> Scan Code Set 2 : un « make » (appui) = 1 octet (ou 2 pour les touches
> étendues, préfixées `0E0h`) ; un « break » (relâchement) est préfixé
> `0F0h`. `ps2_get_char` consomme correctement ces préfixes et ne retourne
> que les appuis reconnus.

| Fonction | Rôle |
|---|---|
| `ps2_rx_push` | Appelée par `irq1_arduino_handler` : enfile un scan code (`BH` mis à 0 : `BX` sert d'index) |
| `ps2_read_byte` | **Bloque** jusqu'à un scan code dans le tampon PS/2. Sortie : `AL` = octet, `CF` = 0 |
| `ps2_rx_available` | `CF`=0 si un scan code attend (PS/2 seulement), non bloquante |
| `ps2_key_available` | `CF`=0 si un octet attend, **PS/2 ou terminal UART**, non bloquante. ⚠️ Ne pas la faire suivre de `ps2_get_char` pour guetter une touche : un simple **relâchement** (`F0 xx`) la rend vraie et `ps2_get_char` attendrait alors une vraie touche — utiliser `ps2_poll_char` |
| `ps2_poll_char` | Version **non bloquante** de `ps2_get_char` (mêmes sorties) : `CF`=0 et `AL`/`BH` si une touche **reconnue** attend ; `CF`=1 sinon, après avoir consommé relâchements et touches ignorées. Sert aux vérifications d'Échap pendant un traitement (dump, test de vitesse, écran Information) |
| `ps2_get_char` | **Bloque** jusqu'à l'appui d'une touche reconnue, PS/2 **ou** UART (boucle sur `ps2_poll_char`). Sortie : `AL` = caractère ASCII ou `PS2_KEY_UP`/`DOWN`/`LEFT`/`RIGHT` ; `BH` = scan code brut (0 pour l'UART) |
| `uart_get_key` / `uart_wait_byte` | Traduction d'un octet du terminal (liste blanche = valeurs de `ps2_keymap`) et attente d'un octet avec délai |
| `ps2_scancode_to_char` / `ps2_keymap` | Scan code Set 2 **normal** → ASCII (chiffres, `A-F`, `Q`, `R`, Entrée, Retour arrière, Échap) via une table `(scan code, caractère)` |
| `ps2_extended_to_char` / `ps2_ext_keymap` | Scan code **étendu** (préfixe `0xE0`, flèches) → `PS2_KEY_*` |
| `ps2_table_lookup` | Recherche générique dans une table `(code, valeur)` |
| `ps2_hex_digit_value` | Caractère ASCII (`'0'-'9'`/`'A'-'F'`) → valeur `0-15`, `CF`=1 si non hexadécimal |
| `ps2_read_hex_editable` | Lit `CL` chiffres hexadécimaux (largeur fixe), écho UART+LCD **et retour arrière** |
| `ps2_edit_byte_value` | Compose 0-2 chiffres hexadécimaux (retour arrière inclus), termine sur **Entrée** |

### Diagnostic bas niveau conditionnel (`TEST_PS2`)

Une directive `%define TEST_PS2`, **commentée par défaut**,
**remplace le menu interactif** par une boucle infinie qui affiche sur
l'UART le scan code **brut** (sans traduction) de chaque trame reçue :

```
=== Test PS/2 (TEST_PS2): en attente de frappes clavier (Set 2, brut) ===
Scan code recu: 0x1C
Scan code recu: 0xF0
Scan code recu: 0x1C
```

Utile pour vérifier la chaîne pont → 8255 → `IR1` → tampon PS/2
indépendamment de la couche de traduction (`ps2_get_char`) qu'utilise le
menu : c'est le scan code tel que le **8088** l'a reçu (à comparer avec la
trace `DEBUG_PS2` du pont).

**Façon recommandée de l'activer — sans modifier le fichier** : passer
la définition directement à NASM en ligne de commande, avec le flag `-d` :

```sh
nasm -f bin -d TEST_PS2 solution-01.asm -o solution-01.bin
```

Alternative : `solution-01.asm` contient aussi la ligne
`%define TEST_PS2`, **commentée par défaut**, dans le bloc de
commentaires "TEST_PS2" près du haut du fichier (avec
`STACK_SEG`/`SECONDE`) — la décommenter active la directive de façon
permanente pour tout `make`/`nasm` lancé sur ce fichier, sans avoir à
répéter le flag `-d` à chaque fois.

## Tiny BASIC (`lib/tiny_basic.asm`)

Interpréteur **Palo Alto Tiny BASIC** dans la ROM, lancé par `1) Tiny Basic` du
sous-menu Basic et piloté par le **terminal UART** du PC (entrée et sortie —
le clavier PS/2 n'est pas utilisé : il n'a pas les lettres ni les symboles du
BASIC). L'écran LCD affiche seulement « Tiny BASIC / Terminal UART / BYE ou
Ctrl-X: menu ». Le code est dans son propre fichier ; `solution-01.asm` se
contente d'appeler `tiny_basic` et de retrouver le menu au retour.

C'est une **adaptation de PATB86** (Amand Tihon, 2019,
[codeberg.org/alrj/patb86](https://codeberg.org/alrj/patb86), licence MIT),
elle-même dérivée du Tiny BASIC 8080 de Li-Chen Wang (1976). Le cœur de
l'interpréteur est conservé tel quel avec ses commentaires d'origine ; les
avis de licence complets figurent en tête de `lib/tiny_basic.asm` et doivent
être conservés dans toute copie.

### Utilisation

- Terminal : port série USB du pont (débit sans objet), **écho local désactivé**, Entrée =
  `CR`. Les mots-clés se tapent en majuscules ou minuscules, avec abréviation
  par un point (`P.`, `PR.`… = `PRINT`).
- **Ctrl-C** interrompt un programme (retour à `Ok`) ; **Ctrl-X** ou la
  commande **`BYE`** quittent vers le menu principal. Retour arrière : `BS` ou
  `DEL`. Les séquences ANSI (flèches…) sont ignorées dans la saisie.
- La mémoire de programme est **vidée à chaque entrée** dans Tiny BASIC (NEW
  implicite) et les variables `A`-`Z` remises à 0 ; le programme n'est donc pas
  conservé après `BYE`.

| Élément | Syntaxe |
|---|---|
| Commandes directes | `LIST [n[,m]]`, `NEW`, `RUN`, `BYE` (ajoutée ici) |
| Instructions | `[LET] var=expr`, `IF expr instructions` (sans `THEN`), `GOTO expr`, `GOSUB expr`, `RETURN`, `FOR var=e1 TO e2 [STEP e3]`, `NEXT var`, `REM`, `INPUT ["texte",]var[,…]`, `PRINT`, `STOP` |
| Fonctions | `RND(n)` (1 à n), `ABS(n)`, `SIZE` (octets libres) |
| Variables | `A`-`Z` et le tableau `@(i)`, entiers signés de 16 bits |
| Opérateurs | `+ - * /` (division entière), `= # < > <= >=` (`#` = différent ; résultat 0 ou 1) |
| `PRINT` | chaînes entre `"` ou `'`, `#n` = largeur d'affichage, `^X` = caractère de contrôle, `,` ou `;` en fin de liste supprime le retour à la ligne |

Une erreur affiche `What?` (syntaxe), `How?` (valeur/ligne impossible,
dépassement, division par zéro) ou `Sorry` (mémoire pleine). Exemple :

```
Tiny BASIC 8088 (PATB86, A. Tihon; L.-C. Wang) - VE2CUY
Ctrl-C: interrompre   Ctrl-X ou BYE: menu principal
Ok
>10 FOR I=1 TO 5
>20 PRINT I*I
>30 NEXT I
>RUN
     1
     4
     9
    16
    25
Ok
>BYE
```

### Exemple : la suite de Fibonacci

Programme à saisir tel quel (les numéros de ligne n'ont pas besoin d'être
consécutifs ; les lignes 40 à 90 sont volontairement absentes) :

```
10 LET A=0
20 LET B=1
30 PRINT A
100 PRINT B
110 LET B=A+B
120 LET A=B-A
130 IF B<=32000 GOTO 100
```

`A` et `B` contiennent deux termes consécutifs de la suite. La ligne 30
affiche le premier terme (`0`), puis la boucle des lignes 100 à 130 affiche
`B`, calcule le terme suivant (`B=A+B`, puis `A=B-A` retrouve l'ancien `B`)
et recommence tant que `B<=32000`. Résultat de `RUN` (chaque nombre sur 6
colonnes, largeur par défaut de `PRINT`) :

```
>RUN
     0
     1
     1
     2
     3
     5
     8
    13
    21
    34
    55
    89
   144
   233
   377
   610
   987
  1597
  2584
  4181
  6765
 10946
 17711
 28657

How?
 110 LET B=A+B?
Ok
>
```

⚠️ Le programme se termine sur une **erreur `How?`**, et non sur la condition
de la ligne 130 : après `28657`, la ligne 110 calcule `17711+28657 = 46368`,
qui dépasse le maximum des entiers signés de 16 bits (`32767`) — Tiny BASIC
détecte le dépassement et interrompt le programme en indiquant la ligne (le `?`
marque l'endroit où l'erreur a été détectée). Le test `B<=32000` n'aurait pas
pu s'exécuter : il est évalué *après* la ligne 110. Pour s'arrêter
proprement, il faut que la limite garantisse que le terme *suivant* tient
encore dans un entier signé : en remplaçant la ligne 130 par
`130 IF B<=17711 GOTO 100`, la suite s'arrête sur `17711` (le calcul suivant
donne `28657`, qui dépasse la limite et termine la boucle) sans aucune erreur.

### Adaptations à ce projet

- **Segment de travail** : PATB86 est un `.COM` (DS=ES=SS=CS). Ici `tiny_basic`
  sauve tous les registres puis bascule `DS=ES=SS=1000h` (segment de RAM
  `VAR_SEG`) avec une pile privée, et restaure tout à la sortie. Les tables de
  commandes restent en ROM et sont lues par `CS` ; les messages sont copiés en
  RAM à l'entrée. Disposition du segment `1000h` :

  | Zone | Contenu |
  |---|---|
  | `0000h-00FFh` | code injecté par Edit+Run RAM (jamais touché) |
  | `0100h-7DFFh` | texte du programme BASIC (32000 octets, comme l'original : `SIZE` reste positif en entier signé) ; le tableau `@()` descend depuis `7E00h` |
  | `7E00h…` | garde, tampon de ligne (128 octets), variables `A`-`Z`, état de l'interpréteur, messages |
  | `F000h-F410h` | pile de l'interpréteur |
  | `F800h-FFFFh` | variables du firmware et pile du menu — **non touchées** |

- **Entrées/sorties** : `tb_outch` → `uart_tx_byte` (un `CR` est suivi d'un
  `LF`) ; `tb_chkio` → `uart_rx_available`/`uart_rx_byte` ; `tb_getln` saisit
  une ligne avec écho, retour arrière et suppression des séquences ANSI.
- **Pas de `HLT`** : l'original attend une interruption (tick BIOS) dans sa
  boucle de saisie ; ici rien ne garantit une interruption périodique (un octet
  déjà reçu ne réveillerait jamais un `HLT`), donc `tb_getln` scrute le tampon
  UART. Ce temps d'attente sert de **graine à `RND`** (pas d'horloge).
- Comme dans l'original, un programme en cours d'exécution consomme les
  caractères tapés d'avance (test de Ctrl-C à chaque instruction).
- Tous les noms sont préfixés `tb_` (conflits évités avec le reste du
  firmware, ex. la macro `print`). `IRQ0`/`int_not_implemented` remettent
  `DS=CS` pour afficher leurs messages, car ils peuvent survenir pendant
  Tiny BASIC.

### Tests (`make test`)

`tests/tb_test.py` exécute l'interpréteur **sous émulateur** ([Unicorn](https://www.unicorn-engine.org/),
`pip install unicorn`) : expressions, opérateurs, `FOR`/`NEXT` (dont imbriqués
et pas négatif), `GOSUB`, `IF`, `INPUT`, `RND`, `LIST`/`NEW`/remplacement et
suppression de lignes, erreurs, Ctrl-C, saisie (`BS`, `DEL`, séquences ANSI),
retour au menu par `BYE`/Ctrl-X (registres, `DS`, `SP` restaurés) et
**aucune écriture hors des zones prévues** du segment `1000h`. Une seconde
série (« mode réel ») utilise les **vraies** routines `uart_*` (`arduino_send`,
tampon circulaire) avec le 8255 émulé. Les entrées sont livrées ligne par
ligne comme le ferait un utilisateur. Ce n'est **pas** un test sur le matériel.

## BASIC « GW-BASIC-like » (`lib/basic*.asm`)

Second interpréteur, **beaucoup plus riche que Tiny BASIC** : lancé par
`2) BASIC` du sous-menu Basic, piloté par le **terminal UART** du PC (port série USB du pont,
écho local désactivé, Entrée = `CR`), il offre des **chaînes de caractères**, des
**nombres à virgule flottante**, `RND`/`RANDOMIZE`, `PEEK`/`POKE`, les
fonctions mathématiques, les tableaux, `DEF FN`, `WHILE`/`WEND`, `DATA`/`READ`…
L'écran LCD affiche « BASIC (type GW) / Terminal UART / SYSTEM/Ctrl-X: menu ».

C'est une **réimplémentation originale**, *inspirée* de
[GW-BASIC de Microsoft](https://github.com/microsoft/GW-BASIC) (licence MIT) :
mêmes mots-clés, mêmes **messages d'erreur** (et numéros), mêmes règles de
types (`%` `!` `$`), même priorité des opérateurs, même format d'affichage des
nombres. Aucun code de GW-BASIC (assembleur 8086 de l'époque, ~ 30 000 lignes)
n'est repris ; l'avis de licence MIT figure néanmoins en tête de `lib/basic.asm`
et doit être conservé dans toute copie. **Exclus** (comme demandé) : disque et
fichiers, imprimante, graphiques, son, ports série/joystick.

### Utilisation

- **`HELP`** affiche le sommaire des commandes, instructions et fonctions.
- **Flèche haut** (au prompt `Ok`) : rappelle **la dernière commande saisie**, curseur à sa **fin**, et la passe au correcteur de ligne de `EDIT` : flèches gauche/droite, Début/Fin, **Inser** (bascule insertion ↔ écrasement, insertion par défaut), **Suppr**, retour arrière, Ctrl-K ; **Entrée** valide (la ligne éditée devient la commande mémorisée), **Ctrl-C** annule. Elle remplace la saisie en cours. Une ligne vide ou de plus de 191 caractères ne remplace pas la commande mémorisée ; sans effet dans `INPUT`. Une seule commande est mémorisée (`B_HIST`, 192 octets libres entre la pile de valeurs et le programme).
- **`EDIT n`** (ou `EDIT .` = dernière ligne entrée, listée ou en erreur) réaffiche la ligne `n` en clair et l'édite **dans le terminal** : flèches gauche/droite, Début/Fin (ou Ctrl-A/Ctrl-E), Suppr, retour arrière, Ctrl-K (efface jusqu'à la fin), insertion à la position du curseur ; **Entrée** valide (comme une ligne saisie : si le numéro change, c'est une nouvelle ligne et l'ancienne reste), **Ctrl-C** annule. Prévu pour des lignes qui tiennent sur une ligne du terminal (~ 80 colonnes).
- **Ctrl-C** interrompt un programme (`Break in 100`, la pile est conservée :
  **`CONT`** reprend, même dans un `GOSUB`/`FOR`) ou annule la ligne en cours de
  frappe ; **Ctrl-X**, **`SYSTEM`** ou **`BYE`** quittent vers le menu. Retour
  arrière : `BS` ou `DEL` ; les séquences ANSI (flèches…) sont ignorées.
- Une ligne sans numéro s'exécute tout de suite ; avec un numéro (1-65529) elle
  est **mémorisée tokenisée** (mots-clés en majuscules au `LIST`). Numéro seul =
  suppression. Modifier le programme efface les variables (comme GW-BASIC).
- Les mots-clés se tapent en majuscules ou minuscules ; **ils doivent être
  séparés des identifiants par un espace ou un symbole** (`FOR I=1 TO 9`, pas
  `FORI=1TO9`) ; seul un numéro de ligne peut suivre directement un mot-clé
  (`GOTO100`). `?` = `PRINT` (**un espace est ajouté si un mot suit directement** : `?rnd` devient `PRINT RND` ; en mode direct comme dans un programme : après Entrée, la ligne est **réaffichée avec `PRINT`** à la place du `?`, sur une ligne de moins de 70 caractères ; `LIST` et `EDIT` montrent aussi `PRINT`), `'` = `REM`.
- Mémoire : ~ 54 Ko pour le programme, les variables et les chaînes
  (`PRINT FRE(0)`).

```
VE2CUY BASIC 8088 (inspire de GW-BASIC, MIT)
Chaines, flottants, RND, PEEK/POKE - HELP: aide, Ctrl-C: Break, Ctrl-X: menu
Ok
10 INPUT "Votre nom";N$
20 FOR I=1 TO 3:PRINT LEFT$(N$,I);:NEXT
30 PRINT:PRINT "PI ="; 4*ATN(1), "RND ="; RND
RUN
Votre nom? Alain
A Al Ala
PI = 3.141593  RND = .1525871
Ok
```

### Types, opérateurs, fonctions

| Élément | Détails |
|---|---|
| **Types** | entier 16 bits (`I%`), **simple précision** (`X!`, ou sans suffixe : flottant IEEE-754 32 bits, 7 chiffres significatifs, logiciel), **chaîne** (`A$`, 0 à 255 caractères). `#` (double) est traité comme `!`. `DEFINT`/`DEFSNG`/`DEFDBL`/`DEFSTR` fixent le type par défaut d'une plage de lettres. Noms jusqu'à 40 caractères. |
| **Constantes** | `123`, `1.5E-3`, `2D2`, `&HFF`, `&O17`, `"texte"`. Un entier hors de -32768..32767 devient flottant. |
| **Opérateurs** (priorité décroissante) | `^` — `-` unaire — `*` `/` — `\` (division entière) — `MOD` — `+` `-` — `=` `<>` `<` `>` `<=` `>=` — `NOT` — `AND` — `OR` — `XOR` — `EQV` — `IMP`. Comparaisons : `-1` (vrai) ou `0`. `+` concatène les chaînes ; comparaison de chaînes octet par octet. |
| **Mathématiques** | `ABS` `SGN` `INT` `FIX` `CINT` `CSNG` `SQR` `SIN` `COS` `TAN` `ATN` `LOG` `EXP` (précision ~ 6-7 chiffres) |
| **Disque** | `SAVE "prog"` (texte ASCII, `.BAS` par défaut), `LOAD "prog"`, `MERGE "prog"`, `RUN "prog"` (charge puis lance), `FILES` (noms, tailles, espace libre), `KILL "fichier"` (nom exact), `FORMAT "YES"` (**détruit tout**). Fichiers à la racine d'un volume **FAT16** de 8 Mo sur la **flash SPI du pont STM32** (noms 8.3, un seul fichier ouvert à la fois). Modes `LOAD`/`MERGE`/`RUN "f"` en direct seulement (`Illegal direct` dans un programme). Erreurs GW-BASIC : `File not found`, `Bad file name`, `Disk full`, `Disk not Ready`, `Disk I/O error`… ; pont muet : `Device Timeout` |
| **Amorçage DOS** | `BOOT "image.img"` monte le fichier comme disquette A: puis amorce A: ; `BOOT` seul : `INT 19h` (secteur 0 → partition active → secteur d'amorce en `0000:7C00`, `DL = 80h`). Ne revient pas si l'amorce démarre (reset pour revenir au menu) ; échec : cause sur l'UART puis `Disk not Ready`. Voir « Couche BIOS pour un DOS » |
| **Secteurs** | `DSKREAD lba, adresse` et `DSKWRITE lba, adresse` : lisent / écrivent un secteur de 512 octets de la flash (LBA 0-65535, secteur 0 = MBR) en mémoire à `DEF SEG`:adresse (base d'un chargeur / d'un futur DOS ; routines `fs_sec_*` de `lib/bridge.asm`, codes `20h`-`24h` du pont). `DSKREAD` refuse les zones protégées comme `POKE` ; `DSKWRITE` écrit **sans vérification** et peut détruire le système de fichiers (`FORMAT "YES"` le refait). `File already open` si un fichier de données est ouvert ; `Illegal function call` si les 512 octets débordent du segment. Exemple : `DEF SEG=&H1000 : DSKREAD 0,&HF400 : PRINT HEX$(PEEK(&HF5FE));HEX$(PEEK(&HF5FF))` affiche `55AA` (signature du MBR) |
| **Lecteur USB** | `USB ON` offre le disque (la flash du pont, MBR + volume FAT16) au **PC** comme lecteur USB ; `USB OFF` le rend au 8088. **Jamais les deux à la fois** : tant que `USB ON` est actif, `FILES`, `SAVE`, `LOAD`, `DSKREAD`… donnent `Disk not Ready` ; éjecter le lecteur sur le PC **avant** `USB OFF`. `File already open` si un fichier de données est ouvert ; `Device unavailable` si le pont n'a pas la pile USB de masse (voir `arduino/8088_bridge_stm32`, environnement `blackpill_f411ce_usbdrive`) |
| **Fichiers de données** | `OPEN "f" FOR INPUT\|OUTPUT\|APPEND AS #1` (ou `OPEN "I"\|"O"\|"A",#1,"f"`), `PRINT #1,…`, `WRITE #1,…` (valeurs séparées par des virgules, chaînes entre guillemets), `INPUT #1,v1,v2…`, `LINE INPUT #1,a$`, `EOF(1)`, `CLOSE [#1]`. **Un seul fichier ouvert, le numéro 1** (le pont n'en ouvre qu'un à la fois) : `SAVE`/`LOAD`/`MERGE`/`RUN "f"`/`KILL`/`FORMAT` donnent `File already open` tant qu'il est ouvert. `END`, la fin du programme, `RUN`, `NEW`, `CLEAR` et `SYSTEM` le ferment (pas `STOP`, comme GW-BASIC) ; sans `CLOSE`, les dernières données ne sont écrites qu'à ce moment. Les enregistrements sont des lignes de texte (CR LF) ; `INPUT #` lit une ligne du fichier et passe à la suivante s'il manque des champs. Erreurs : `Bad file number`, `Bad file mode`, `File already open`, `File not found`, `Input past end`, `Disk full` |
| **Horloge** | `TIMER` (secondes depuis minuit, précision ~ 1/100 s), `TIME$` / `DATE$` (`"hh:mm:ss"`, `"mm-dd-yyyy"`), et les instructions `TIME$="h:m:s"` / `DATE$="m-d-yy"` pour régler l'horloge (dates 2000-2099). Fournie par la **RTC du pont STM32** (voir [Pont Arduino](#pont-arduino-8255-en-mode-2)) : sans pont STM32, `Device Timeout` après ~ 0,5 s |
| **Aléatoire** | `RND` / `RND(1)` (suivant, dans [0 ; 1[), `RND(0)` (dernier), `RND(-n)` (réinitialise : suite reproductible) ; `RANDOMIZE n` fixe la graine, `RANDOMIZE` la brasse avec le temps d'attente de la frappe ; `RANDOMIZE TIMER` utilise l'horloge du pont STM32 |
| **Chaînes** | `LEN` `ASC` `VAL` `INSTR([début,]s$,t$)` `CHR$` `STR$` `HEX$` `OCT$` `LEFT$` `RIGHT$` `MID$(s$,i[,n])` `STRING$(n,c\|s$)` `SPACE$` `UCASE$` `LCASE$` `INKEY$` `INPUT$(n)` ; instruction `MID$(v$,i[,n])=texte` |
| **Machine** | `PEEK(a)` `POKE a,v` `DEF SEG [=seg]` (segment par défaut `1000h`), `INP(port)` `OUT port,v` `WAIT port,masque[,xor]` `CALL adresse` (sous-programme en langage machine terminé par `RETF`, à `DEF SEG:adresse`) ; `FRE(0)` mémoire libre, `POS(0)` colonne |
| **Système** | `HELP` (sommaire des commandes), `EDIT n` (édition d'une ligne), `LIST [n][-[m]]` `DELETE n-m` `NEW` `RUN [n]` `CLEAR` `CONT` `TRON`/`TROFF` `SYSTEM`/`BYE` ; terminal : `CLS` `LOCATE ligne,col` `COLOR av[,fond]` (séquences ANSI) `BEEP` |

### Instructions de programme

`LET` (facultatif), `PRINT` (`;` `,` — zones de 14 colonnes — `TAB(n)` `SPC(n)`),
`INPUT ["invite"(;\|,)] v1,v2…` (`?Redo from start` si la saisie est
invalide), `LINE INPUT`, `IF … THEN … ELSE …` (imbrications, `THEN n`,
`IF … GOTO n`), `GOTO`, `GOSUB`/`RETURN`, `ON n GOTO\|GOSUB l1,l2…`,
`FOR … TO … STEP …`/`NEXT [i,j]` (le corps s'exécute au moins une fois, comme
GW-BASIC), `WHILE`/`WEND`, `DATA`/`READ`/`RESTORE [n]`, `DIM` (jusqu'à 8
dimensions ; un tableau non déclaré a des bornes 0 à 10) `ERASE`, `SWAP`,
`DEF FNnom(p1,p2…)=expression` (numérique ou chaîne, dans un programme),
`END`, `STOP`, `REM`/`'`. Les erreurs sont celles de GW-BASIC : `Syntax error`,
`Type mismatch`, `Overflow`, `Division by zero`, `Illegal function call`,
`Subscript out of range`, `Out of DATA`, `Out of memory`, `Out of string space`,
`String too long`, `Undefined line number`, `NEXT without FOR`, etc., suivies
de ` in <ligne>` pendant un programme.

**Non implémentés** (par rapport à GW-BASIC) : fichiers multiples et à accès direct (`OPEN … AS #2`, `FIELD`, `GET`/`PUT`, `LOF`, `LOC`, `INPUT$(n,#1)`), `LPRINT`, graphiques (`SCREEN`, `LINE`, `CIRCLE`…), `SOUND`/`PLAY`
(seul `BEEP`), `ON ERROR`/`RESUME`/`ERR`/`ERL`, `PRINT USING`, dates hors
2000-2099, `RENUM`/`AUTO`, `OPTION BASE`, `WIDTH`,
`KEY`, la double précision (traitée comme la simple précision).

### Architecture

Un module par rôle, tous assemblés à partir de `lib/basic.asm` :

| Fichier | Rôle |
|---|---|
| `basic.asm` | licence, disposition de la RAM, entrée/sortie du menu, saisie de ligne, erreurs, **tokeniseur** |
| `basic_tokens.inc` | liste **unique** des mots-clés (jeton, texte, gestionnaire), développée trois fois par macro |
| `basic_float.asm`, `basic_fmath.asm` | **flottants IEEE-754 32 bits logiciels** (`+ - * /`, comparaison, conversions, `INT`/`FIX`), conversion décimale (7 chiffres) et fonctions `SQR EXP LOG SIN COS TAN ATN ^` (polynômes/séries, sans 8087) |
| `basic_eval.asm` | évaluateur d'expressions (montée en priorité, pile de valeurs), variables, tableaux |
| `basic_str.asm` | tas de chaînes, **ramasse-miettes** (compactage), concaténation, comparaison, mise en forme des nombres |
| `basic_stmt.asm` | programme (insertion/suppression/liens), boucle d'exécution, toutes les instructions |
| `basic_func.asm` | fonctions intégrées |
| `basic_data.asm` | tables en ROM : mots-clés, gestionnaires, messages d'erreur |

- Le programme est stocké **tokenisé** (`[lien][numéro][jetons…][0]`) ; `FOR`,
  `GOSUB` et `WHILE` empilent leur cadre directement sur la pile du 8088 (`CONT`
  après `Break` conserve donc ces cadres).
- **Segment de travail** identique à Tiny BASIC : `DS=ES=SS=1000h`, pile privée,
  tout restauré au retour au menu.

  | Zone (segment `1000h`) | Contenu |
  |---|---|
  | `0000h-00FFh` | code injecté par Edit+Run RAM (jamais touché) |
  | `0100h-03FFh` | variables de l'interpréteur |
  | `0400h-0B3Fh` | tampon de saisie, tampon de ligne tokenisée, tampon de nombres, pile des valeurs |
  | `0C00h…` | programme, puis variables simples, puis tableaux (vers le haut) |
  | `…-DFF0h` | chaînes (tas qui descend depuis `DFF0h`) |
  | `E000h-F3F0h` | pile de l'interpréteur |
  | `F800h-FFFFh` | variables du firmware et pile du menu — **non touchées** |

- **Chaînes** : un descripteur (`[longueur][pointeur]`) par variable/élément de
  tableau ; un seul propriétaire par chaîne du tas ; les littéraux pointent dans
  le texte du programme ; le ramasse-miettes compacte le tas quand il est plein
  (les temporaires et les valeurs en attente dans une expression sont des
  racines).
- **`POKE` protégé** : une écriture dans la table des vecteurs (`0000:0000-03FF`),
  dans l'espace de travail du BASIC (`1000:0000-03FF`) ou dans les variables du
  firmware (`1000:F800-FFFF`) donne `Illegal function call`.

### Tests (`make test`)

`tests/basic_test.py` (harnais : `tests/basic_harness.py`, `tests/basic_test.asm`)
exécute l'interpréteur **sous émulateur** (Unicorn) : arithmétique et priorités,
affichage des nombres (formats fixe et `E`), fonctions, chaînes et
ramasse-miettes (des milliers d'allocations), tableaux, `DATA`/`READ`, `DEF FN`,
`WHILE`, `ON`, `CONT`, `INPUT`, `LIST`/`DELETE`, erreurs, Ctrl-C, `PEEK`/`POKE`
(et gardes), séquences ANSI, retour au menu (registres, `DS`, `SP` restaurés)
et **aucune écriture hors des zones prévues** ; une seconde série utilise les
vraies routines `uart_*`. `tests/bridge_test.py` vérifie les commandes du pont (horloge :
`rtc_get`/`rtc_set`, canal 3, réponses, délai) avec un 8255 émulé. `tests/fl_test.py` vérifie la bibliothèque flottante
contre `numpy.float32` (arrondi exact pour `+ - * /`, quelques ulp pour les
fonctions). Des essais aléatoires complémentaires (expressions comparées à un
oracle Python, lignes aléatoires) ont aussi été menés. Ce n'est **pas** un test
sur le matériel.

## Interruptions logicielles type BIOS (`INT 10h` / `INT 16h`)

Sous-ensemble « esprit BIOS » (IBM PC), adapté au matériel réel de ce
projet (LCD HD44780 4×20 via le pont, pas de mémoire vidéo ni de VGA).
`INT n`/`IRET` sont purement logiciels sur le 8088 — **aucun 8259 (PIC)
requis** pour eux, contrairement aux interruptions matérielles décrites
dans [Interruptions matérielles](#interruptions-matérielles-8259).
`int10h_handler` et `int16h_handler` font un `sti` à l'entrée (l'`INT` a
mis `IF` à 0) pour que le clavier reste servi pendant un affichage.

Au démarrage (`start:`), dans l'ordre :
1. **Toute la RAM (128 Ko) est effacée à 0** — segments `0000h` et
   `1000h`, écrit en ligne (`rep stosw`, pas de `CALL`) avant même
   l'initialisation de la pile utilisable, pour éliminer le contenu
   résiduel ("garbage") de la RAM statique à la mise sous tension —
   visible sinon dans un `Dump memory` de l'IVT ou d'ailleurs.
2. **Les 256 entrées de l'IVT** (`INT 00h`-`FFh`) sont peuplées avec
   `int_not_implemented` (`init_ivt_not_implemented`) — un gestionnaire
   générique qui affiche `*** Interruption non implementee ***` sur
   l'UART et retourne (`IRET`). Un appel accidentel à une interruption
   non gérée produit donc un diagnostic clair plutôt que de sauter
   dans du contenu résiduel de l'IVT.
3. **`setup_bios_interrupts`** installe *ensuite* nos propres
   gestionnaires (`int10h_handler`/`int16h_handler`) — remplaçant
   seulement les entrées `INT 10h`/`16h`.
4. **`init_8259`** programme le 8259 et installe `irq0_test_handler`
   (`INT 08h`) et `irq1_arduino_handler` (`INT 09h`) ; les interruptions
   ne sont activées (`sti`) qu'ensuite. Toutes les autres entrées
   restent sur `int_not_implemented`.

### Initialisation de l'IVT : calcul d'adresse

Chaque entrée de l'IVT fait **4 octets** — pas parce qu'une adresse y
est stockée sur 20 bits d'un bloc, mais parce que c'est un **pointeur
FAR classique** : 2 octets d'**offset** + 2 octets de **segment**,
stockés séparément (offset d'abord). `setup_bios_interrupts` les
écrit ainsi pour `INT 10h`/`INT 16h` :

```asm
mov word [es:10h*4],   int10h_handler   ; offset (2 octets, a N*4)
mov word [es:10h*4+2], cs               ; segment (2 octets, a N*4+2)
```

Avec 256 numéros d'interruption possibles (`INT 00h`-`FFh`) × 4 octets
chacun = 1024 octets, exactement le segment `0000h:0000h`-`0000h:03FFh`
(déjà réservé sur ce montage, protégé par `cli` pendant `test_ram`).
`INT 10h` a donc son entrée à l'offset `10h×4 = 40h`, `INT 16h` à
`16h×4 = 58h`.

Les deux moitiés de ce pointeur ne sont pas obtenues de la même
façon :
- **L'offset** (`int10h_handler`) est résolu par **NASM à
  l'assemblage** — pas calculé par le programme à l'exécution. Ce
  projet assemble en `-f bin` à plat (`ORG 0000h`), donc
  `int10h_handler` est une constante 16 bits connue d'avance :
  l'assembleur sait exactement à quel octet du binaire correspond
  cette étiquette.
- **Le segment** (`cs`) est lu par le programme **à l'exécution**, via
  le registre `CS` du CPU — qui vaut `C000h` sur ce montage (fixé par
  le vecteur de reset matériel, `jmp 0C000h:0000h`).

Le programme place donc un couple `offset:segment`, **pas** une
adresse physique 20 bits pré-combinée. C'est le **CPU**, au moment où
il exécute `INT 10h`/`INT 16h` plus tard, qui relit ces deux mots
depuis l'IVT et calcule `segment×16 + offset` pour obtenir l'adresse
physique réelle où sauter — la même formule qu'au piège `FFFF:FFF0`
décrit plus bas dans [Menu interactif](#menu-interactif) (Dump
memory). Cette distinction est utile : `int10h_handler` pourrait vivre n'importe où dans le segment
`C000h` sans recalcul manuel (l'assembleur/linker s'en charge), et si
le code tournait un jour depuis un autre segment que `C000h`, il
suffirait que `CS` soit différent au moment de `setup_bios_interrupts`.

**`INT 10h` — affichage** (`int10h_handler`) :

| `AH` | Fonction | Registres |
|---|---|---|
| `02h` | Positionne le curseur **logique** du device `BH` (persiste en RAM — **un jeu de curseur par device** : LCD parallèle et LCD I2C n'interfèrent pas l'un avec l'autre) | `DH`=ligne (0-3), `DL`=colonne (0-19), `BH`=device (voir ci-dessous — `UART` : no-op, pas de position pour un flux série) |
| `09h` | Écrit `AL` au curseur logique courant DU DEVICE `BH`, **`CX` fois de suite** (remplit `CX` cellules consécutives pour LCD/LCD I2C — même convention que le vrai BIOS, PAS le même caractère au même endroit ; pour `UART`, transmet simplement `AL` `CX` fois, sans notion de position) ; le curseur logique (LCD/LCD I2C) **n'est pas déplacé** | `BH`=device (`1`=LCD parallèle, `2`=LCD I2C, `3`=UART — voir `LCD`/`LCDI2C`/`UART`, `include/lcd_macros.inc`), `BL`=couleur (**sans effet pour l'instant** — réservée à l'UART, prochaine version), `CX`=répétitions |

Le débordement d'une ligne de 20 suit l'auto-incrémentation DDRAM du
HD44780 (adressage entrelacé des afficheurs 4 lignes « type A » —
`LCD_LINE3`/`4` suivent directement `LCD_LINE1`/`2` en mémoire
interne) : peut déborder sur une **autre** ligne visible, sans
écrêtage logiciel. Aucune vérification de bornes sur `DH`/`DL` (même
choix que `Edit RAM`).

### Macros `gotoxy` / `print` (`include/lcd_macros.inc`)

Façon normale d'utiliser `INT 10h` — remplacent `lcd_goto`/`lcd_show`/
`i2c_lcd_goto`/`i2c_lcd_show` ET les paires `mov si,texte` / `call
uart_tx_string` par un affichage passant systématiquement par `INT 10h` :

```asm
gotoxy 0, 0, LCD                    ; positionne (ligne, colonne, device)
print  lcd_txt_splash_l1, LCD       ; affiche (texte, device)
```

| Constante | Valeur | Device |
|---|---|---|
| `LCD` | 1 | LCD parallèle (historique, inutilisé) |
| `LCDI2C` | 2 | LCD I2C (PCF8574 `0x27`) |
| `UART` | 3 | UART (via le pont, pas de curseur — `gotoxy` y est un no-op) |

`print` appelle `int10h_print_string`, qui affiche caractère par
caractère pour `LCD`/`LCDI2C` (repositionnement `AH=02h` avant chaque
caractère, puisque `AH=09h` ne déplace pas le curseur logique) ou
transmet directement pour `UART` (pas de position à gérer). Aucun
registre appelant n'est affecté (`int10h_handler`/
`int10h_print_string` préservent tout).

**Portée de la conversion** : tous les affichages de texte **simples**
(une seule chaîne, autonome) sont passés par `gotoxy`/`print` — écran
de démarrage, écrans I2C, menus, messages de fin/erreur. Les
**bandeaux composés** (plusieurs fragments de texte entrelacés avec
des valeurs hexadécimales/décimales calculées sur la même ligne — ex.
le bandeau adresses de `dump_memory_action`, `dump_line`,
`msg_bloc_progression` lignes 2/4, `msg_defaut_detail`) gardent les appels directs
(`uart_tx_string`/`lcd_print`/`i2c_lcd_print`) : `AH=09h` ne déplace
pas le curseur logique, donc un enchaînement `print` + valeur
dynamique + `print` devrait repositionner explicitement entre chaque
fragment — les appels directs (qui s'appuient sur l'auto-incrément
matériel du DDRAM ou sur `uart_tx_byte`/`uart_tx_hex_word` bruts)
restent plus simples pour ce cas précis.

**`INT 16h` — clavier** (`int16h_handler`) :

| `AH` | Fonction | Registres |
|---|---|---|
| `01h` | Lecture **non bloquante** d'une touche | Sortie : `AH`=scan code PS/2 Set 2 brut, `AL`=caractère ASCII (ou `PS2_KEY_*`), `ZF=0` si une touche a été lue ; `AX=0`/`ZF=1` sinon |

Non bloquant : `ps2_key_available` regarde les tampons circulaires
(PS/2 **et** terminal UART), remplis par l'interruption `IR1`. Si une
touche est disponible, elle est **consommée** (pas de « peek » sans
consommer, contrairement au vrai BIOS IBM PC).
Le `ZF` renvoyé par `IRET` est injecté directement dans le mot `FLAGS`
empilé par `INT` (technique standard pour ce genre de gestionnaire —
`IRET` restitue les flags *tels qu'empilés par `INT`*, pas l'état
courant du CPU). `AX` n'est **pas préservé** (c'est la sortie voulue)
— `BX`/`CX`/`DX`/`SI`/`DI`/`BP`/`ES` le sont.

`ps2_get_char` (`lib/ps2.asm`) expose maintenant aussi `BH` = scan
code PS/2 Set 2 brut de la touche reconnue, en plus de `AL` — ajouté
pour `int16h_handler` (aucun appelant existant n'utilisait `BH`, déjà
« détruit » avant ce changement).

`INT 16h` existe comme **interface disponible en parallèle** de
`ps2_get_char` — rien ne l'appelle encore. `INT 10h`, lui, est
maintenant le chemin normal pour tout affichage de texte **simple**
via les macros `gotoxy`/`print` (voir la sous-section suivante) : écran
de démarrage, écrans I2C, menus, messages de fin/erreur. Les bandeaux
composés (`dump_memory_action`, `dump_line`, `msg_bloc_progression`,
`msg_defaut_detail`) continuent d'utiliser les appels
directs (`lcd_print`/`i2c_lcd_print`/`uart_tx_string` et les routines
hexadécimales/décimales), sans changement de comportement.

## Couche BIOS pour un DOS (`lib/bios.asm`, `lib/isr.asm`)

Première étape vers un vrai DOS (MS-DOS 2.x, noyau FreeDOS) : la ROM se comporte comme le **BIOS d'un PC**
pour le disque, le clavier, l'horloge et la mémoire, et sait **amorcer** un secteur de démarrage de la flash.

| Interruption | Rôle |
|---|---|
| `INT 13h` | disque dur `DL = 80h` = la **flash du pont** (secteurs de 512 octets). CHS (`AH` = 00h, 01h, 02h, 03h, 04h, 08h, 15h) **et accès étendu LBA** (41h, 42h, 43h, 44h, 48h). Géométrie 255 têtes × 63 secteurs (celle que SdFat écrit dans le BPB), 2 cylindres pour 8 Mo. **Disquette A: (`DL = 0`)** = une **image** (fichier `.IMG` de la flash) montée par `AH = F0h` (`DS:SI` = nom) ; `AH = F1h` la démonte ; géométrie d'après la taille du fichier (160, 180, 320, 360, 720 Ko, 1,2 ou 1,44 Mo) ; les écritures vont dans le fichier. Sans image, `DL = 0` donne `AH` = 80h. Erreurs : 04h (secteur introuvable ou hors disque/image), 80h (le pont ne répond pas), 0AAh (`USB ON` : le PC a le disque) ; montage : 0E2h (fichier introuvable), 0E5h (nom invalide), 0EFh (taille non reconnue). |
| `INT 19h` | **amorçage** : si une image est montée, le secteur 0 de l'**image** (disquette A:, `DL = 0`) ; sinon le secteur 0 (MBR) de la flash → partition active (sinon la première partition FAT) → son secteur d'amorce en `0000:7C00`, exécuté avec `DL = 80h`, pile `0000:7C00`. Si le secteur 0 n'a pas de table de partitions mais commence par un saut (EB/E9), c'est lui l'amorce. Ne revient qu'en cas d'échec (`CF = 1`, cause sur l'UART). Depuis le BASIC : **`BOOT`** / **`BOOT "IMAGE.IMG"`** ; depuis le menu : **sous-menu USB Disk, option 3**. |
| `INT 16h` | clavier = **terminal UART** : `AH` = 00h/10h lire, 01h/11h consulter (sans consommer, `ZF`), 02h/12h indicateurs. Octets bruts (minuscules, ponctuation, Ctrl-lettre, DEL = retour arrière) ; séquences ESC = touches étendues (`AL` = 0 : flèches 48h/50h/4Dh/4Bh, Début/Fin, Inser/Suppr, Page haut/bas, F1-F4). Le clavier PS/2 n'est pas géré (le BASIC non plus). |
| `INT 1Ah` | horloge = **RTC du pont** : `AH` = 00h (ticks depuis minuit, 18,2/s), 02h/04h (heure/date en BCD), 03h/05h (régler). |
| `INT 10h` | fonctions standard sur le terminal : `AH` = 0Eh (téléscripteur), 0Fh (mode : 80 colonnes), 02h/03h (curseur, page 0 : séquences ANSI), 06h/07h (`AL` = 0 efface l'écran), 08h, 09h/0Ah. `BH` = 1/2/3 garde l'interface LCD/UART du projet. |
| `INT 11h`, `12h`, `15h`, `14h`, `17h` | équipement (0220h : pas de disquette ; 0221h avec une image montée), **mémoire 126 Ko**, `AH` = 88h (aucune mémoire étendue), série/imprimante (absents). |

- **Mémoire donnée au DOS** : `0000:0500` à `1000:F7FF` (126 Ko, `INT 12h`) ; `1000:F800-FFFF` reste au micrologiciel
  (tampons du pont, pile privée du BIOS `1000:FE00-FEFF`). La zone de données du BIOS `0040:0000` est remplie
  (équipement, mémoire, mode vidéo 3, disque dur = 1, tampon clavier).
- **Piles indépendantes** : un DOS a sa propre pile et ses segments, alors que le micrologiciel adresse ses tampons
  par `SS`. Chaque service BIOS qui en a besoin (13h, 16h, 1Ah, 19h) **bascule sur une pile privée de `VAR_SEG`**
  (`BIOS_ENTER`), sauve tous les registres dans un cadre, puis rend la main avec `CF`/`ZF` posés dans les
  indicateurs empilés. **L'ISR de l'IRQ1** (`lib/isr.asm`) sauve `DS`, le charge avec `VAR_SEG` et range les octets par
  `DS` : elle ne dépend plus de la pile ni des segments du programme interrompu.
- **Amorcer un DOS depuis une image** : copier un fichier `.IMG` de disquette (par exemple `pcdos2_1.img`, 180 Ko) sur le
  lecteur USB (option `USB ON/OFF` du sous-menu USB Disk, ou `USB ON` au BASIC ; copier, éjecter, `OFF`), puis **sous-menu
  USB Disk, option 3 ("Boot disk image")** : liste les `.IMG` du disque, on choisit le numéro, l'image est montée comme
  disquette A: et amorcée. Depuis le BASIC : `BOOT "PCDOS2_1.IMG"`.
  Les écritures du DOS vont dans le fichier image. **PC-DOS 2.1** s'amorce (validé sur le matériel), affiche le bandeau
  et `A>` et exécute `VER`, `DIR`.
- **Progression de l'amorçage** : après « Amorce: image disquette (A:)... », un **`.`** s'affiche sur l'UART à chaque
  lecture `INT 13h` (`BIOS_DOTS`, `lib/bios.asm`), jusqu'au premier affichage du DOS (premier `INT 10h`, qui passe à la
  ligne) ou jusqu'à un message d'échec. Pas de points pendant que la trace (ci-dessous) est active.
- **Trace du BIOS sans changer de ROM** : **Ctrl-T** (octet `14h`) depuis le terminal, ou **Ctrl-Échap** au clavier PS/2,
  active/arrête à tout moment (menu, BASIC, DOS) la trace de chaque `INT 13h`/`1Ah` sur l'UART (sauf `INT 1Ah AH=00h`,
  la lecture des ticks, que DOS 3.30 répète en boucle à l'invite) :
  `<nn AX BX CX DX ES` à l'entrée, `-AX CX DX CF>` au retour (+ les 8 octets de la RTC pour `INT 1Ah`). Une ligne
  sans `-... >` final = le 8088 s'est arrêté pendant cet appel. L'ISR reconnaît la touche (`TRACE_KEY`/`ps2_hotkey`,
  `lib/isr.asm`) et ne la transmet pas au programme ; annonce « [Trace BIOS ACTIVE ...] » / « [Trace BIOS ARRETEE] ».
  Arrêtée au démarrage (RAM effacée, y compris après Ctrl-\). `make trace` produit `solution-01-trace.bin` : trace active
  dès le démarrage, plus la carte mémoire de diagnostic (`bios_memmap`).
- **Date et heure du DOS** : PC-DOS 2.x n'a pas d'horloge et propose `1-01-1980` (`Enter new date:` puis `Enter new time:`) ;
  ça se tape au clavier, comme sur un vrai PC. `INT 1Ah AH=00h` signale le passage de minuit (`AL = 1`) pour que le DOS
  incrémente la date. La RTC se règle au BASIC (`DATE$="m-d-y"`, `TIME$=...`), utile pour recaler l'heure affichée par
  `INT 1Ah AH=02h`/`03h`. Une injection automatique de la date/heure à ces invites a été essayée puis retirée : elle
  cassait avec certains DOS (chaîne acceptée à un moment où le curseur ne l'attendait pas).
- **Reset matériel du 8088 par le pont** (firmware du pont 1.2, `PB2` → broche `RESET` 21 — voir
  `arduino/8088_bridge_stm32/README.md`) : **Ctrl-Alt-Suppr** au clavier PS/2 ou **`Ctrl-\`** au terminal. Le pont
  intercepte la touche et pulse lui-même le `RESET` : ça marche **même quand le 8088 est figé** (interruptions
  masquées, arrêt), contrairement au redémarrage logiciel décrit ci-dessous. Au démarrage du pont, le 8088 reste en
  reset jusqu'à ce que le pont soit prêt. Avec un pont plus ancien (ou `PB2` non câblée), Ctrl-\ reste le
  redémarrage logiciel ci-dessous.
- **Quitter le DOS / revenir au menu sans reset** : envoyer **`Ctrl-\`** (octet `1Ch`) depuis le terminal. L'ISR de l'IRQ1 le reconnaît (`WARM_RESET_KEY`, `lib/isr.asm`), envoie l'EOI et **saute au vecteur de reset de la ROM** (`0C000h:0000h`) : redémarrage complet (RAM effacée, 8255 et 8259 réinitialisés), menu principal. Ça marche quoi que fasse le 8088 (menu, BASIC, DOS, programme bloqué), tant que l'IRQ1 n'est pas masquée. L'octet n'est pas transmis au programme (Ctrl-\ n'est pas utilisé par le DOS ni le BASIC). L'image reste montée du côté du pont mais le menu la remonte. Le message d'amorçage le rappelle.
- **Vitesse** : un secteur passe par 16 blocs de 32 octets. Le pont envoie les **réponses** (blocs de secteurs, lecture
  de l'image) dès que IBF (PC5 → PA15) indique que le 8088 a lu l'octet précédent (`REPLY_GAP_US` = 20 µs, au lieu de
  l'espace de 1 ms gardé pour le clavier et l'UART) : le débit est celui de l'interruption du 8088 (~ 150-300 µs par
  octet, soit 3 à 6 Ko/s) au lieu de ~ 1 Ko/s. Sans le fil IBF (`USE_IBF 0`), les réponses gardent l'espace de 1 ms.
- **Somme de contrôle** : après chaque secteur lu (disque ou image), le 8088 demande au pont la somme des 512 octets (commande `2Bh`) et la compare à celle des octets reçus; si elles diffèrent le secteur est relu (3 essais) et un `!` s'affiche sur l'UART (`BIOS_SHOW_RETRY`, `BIOS_BADSUM` = compteur). Toujours faux : INT 13h rend AH=20h (jamais de données fausses). Demande un pont à jour (ROM et pont vont ensemble).
- **OUT parasites de MS-DOS 3.30** : le 8255 est sélectionné par A7 seul (tout port ≥ 80h l'atteint), alors que sur un vrai PC les ports 2F2h-2F7h n'existent pas. `IO.SYS` de MS-DOS 3.30 y écrit 0FFh (`mov dx,2F2h / out dx,al / inc dx` ×6, puis idem en 2F6h): cela reprogrammait le 8255 (mot de mode 0FFh, ports A/B/C écrits), donc le pont était perdu et des interruptions parasites (INT E0h, INT CDh...) arrivaient. `bios_patch_sector` (INT 13h, lectures seulement) remplace ces `OUT` par des `NOP` dans le secteur lu (motif `BAh F2h 02h|06h EEh` puis `EEh/42h`), un `+` s'affiche sur l'UART par `OUT` neutralisé (`BIOS_SHOW_PATCH`, compteur `BIOS_NPATCH` en 1000:FBF4). Une solution matérielle serait de décoder toutes les lignes d'adresse d'E/S.
- **Limites** : pas de clavier PS/2 (terminal UART seulement), pas de minuterie (IRQ0), pas d'écran matériel (les
  programmes qui écrivent en mémoire vidéo ou pilotent le matériel PC n'iront pas plus loin), un seul disque dur
  (la flash) sans lecteur C: monté par le BIOS pour l'instant. Testé à l'émulateur (`tests/bios_test.py` : 105
  vérifications, appels faits comme un DOS depuis une autre pile, dont l'amorçage de PC-DOS 2.1 avec la vraie image).
- **MS-DOS/PC-DOS 5.0 et plus récent : non supportés (mémoire insuffisante)** : PC-DOS 5.0 exige **au moins 256 Ko**
  de RAM ; ce matériel n'en a que 128 Ko (126 Ko annoncés par `INT 12h`). À l'émulateur, DOS 5.0 (`Dos50-d1.img`)
  boucle indéfiniment pendant l'initialisation (`SYSINIT`), bien avant `COMMAND.COM` : balayage sans fin d'une table
  interne (probablement dimensionnée à partir de la mémoire disponible, mal calculée faute des 256 Ko attendus),
  dans une boucle dont la condition d'arrêt ne peut mathématiquement jamais être atteinte vu le pas de balayage.
  PC-DOS 2.1 et MS-DOS 3.30, eux, s'amorcent normalement (voir plus haut) : leur initialisation est plus simple et
  n'a pas cette exigence.

## Menu interactif

Affiché après le splash, sur l'UART **et** le LCD I2C (une option par
ligne). Remplace le POST automatique des versions précédentes : chaque
action est déclenchée par une touche — **clavier PS/2 ou terminal UART**,
indifféremment — et le menu se redessine après chaque action.

**Menu principal** (4 options, chacune un **sous-menu** — l'ancien
chenillard « LED Show on PC » a été retiré avec la réaffectation du
8255) :

```
1) Basic
2) Memory functions
3) USB Disk
4) Configuration
```

Chaque sous-menu se redessine (UART+LCD) après chaque action, et la
touche **Échap** (non affichée à l'écran) y retourne directement au
menu principal, depuis n'importe quelle page.

**Sous-menu "Basic"** (option 1) :

```
1) Tiny Basic
2) BASIC
```

`1) Tiny Basic` lance l'interpréteur Tiny BASIC et `2) BASIC` le BASIC plus
riche (chaînes, flottants…) ; tous deux se pilotent **uniquement par le
terminal UART** — voir [Tiny BASIC](#tiny-basic-libtiny_basicasm) et
[BASIC « GW-BASIC-like »](#basic--gw-basic-like--libbasicasm).

**Sous-menu "Memory functions"** (option 2) :

```
1) Dump memory
2) Edit RAM
3) Registres CPU
4) Edit+Run RAM
5) IVT
6) Test RAM
```

Le LCD I2C n'a que 4 lignes : depuis l'ajout de `5) IVT`, ce menu se
**pagine sur 2 écrans** (Gauche/Droite pour basculer, comme le fait
déjà `Registres CPU` — indicateur `1/2`/`2/2` en haut à droite de la
première ligne) : page 1 = options 1-4 (inchangée), page 2 = options 5-6
(`6) Test RAM`, ex-option 1 du menu principal, ajoutée sur la 2e ligne de
cette page). L'UART, lui, affiche toujours les 6 options d'un coup (pas de
contrainte de largeur/hauteur), une seule fois à l'entrée dans ce
menu — pas à chaque bascule de page LCD.

**Sous-menu "USB Disk"** (option 3) :

```
1) USB: OFF
2) List files
3) Boot disk image
```

`1) USB ON/OFF` **bascule** le disque (la flash du pont) entre le 8088 et
le PC : un seul état est mémorisé côté ROM (`OFF` par défaut, comme au
démarrage), et la touche envoie la commande opposée à l'état courant —
équivalent du `USB ON`/`USB OFF` du BASIC, mais accessible sans lancer le
BASIC. La ligne elle-même montre l'état courant (`1) USB: OFF` ou
`1) USB: ON`), redessinée à chaque passage dans ce sous-menu — donc mise à
jour tout de suite après une bascule. `2) List files` liste les fichiers de
la racine (nom, taille) puis l'espace libre, sur l'UART seulement (comme
`FILES` au BASIC). `3) Boot disk image` est l'ancienne option 5 du menu
principal (voir plus bas).

**Sous-menu "Configuration"** (option 4) :

```
1) Clock speed
2) Test CPU speed
3) Heure et date
4) Information
```

`1) Clock speed` affiche la **fréquence courante** de l'horloge du 8088 —
générée par le pont STM32 (`PA3`, PWM matériel `TIM2` canal 4), qui a
**remplacé l'Arduino UNO R4 séparé** de `projets/Clock-8088/` : plus besoin
d'une deuxième carte — et permet de la régler entre **1 et 10 MHz** :

```
--- Clock speed ---
1) Up   : 0.1 MHz
2) Down : 0.1 MHz
3) Up   : 1 MHz
4) Down : 1 MHz
5) 4.77 MHz
6) 8.0 MHz
(Echap: retour au sous-menu Configuration)

Current speed:  4.77 MHz
```

| Touche | Effet |
|---|---|
| `1` | `+0,1 MHz` |
| `2` | `-0,1 MHz` |
| `3` | `+1 MHz` |
| `4` | `-1 MHz` |
| `5` | Directement `4,77 MHz` (vitesse du PC IBM d'origine, et valeur **par défaut** au démarrage du pont) |
| `6` | Directement `8 MHz` |
| Échap | Retour au sous-menu Configuration |

Chaque touche envoie **immédiatement** la nouvelle fréquence au pont (pas de
validation séparée — comme le potentiomètre d'origine) : changer la vitesse
du CPU en direct est sans risque, contrairement à une écriture en RAM,
donc pas de tampon/annulation comme `Edit RAM`. Sans réponse du pont (pont
trop ancien qui ne connaît pas encore cette commande, ou muet) : message
d'erreur, retour immédiat au sous-menu. Le menu (options + touche Échap) est
affiché **une seule fois** à l'entrée, sur l'UART **et** le LCD (texte fixe) ;
seule la ligne `Current speed: ...` change et se redessine à chaque touche.
Voir `arduino/8088_bridge_stm32/README.md` (câblage `PA3`, protocole `2Ch`)
pour le détail côté pont.

`2) Test CPU speed` lance un **banc d'essai à charge fixe** (une boucle
"vide" d'un nombre d'itérations connu à l'avance) et mesure sa durée
**réelle** via l'horloge temps réel (RTC) du pont — **indépendante** de
l'horloge du 8088, contrairement à un comptage de cycles logiciel qui
serait circulaire ici, puisque c'est justement la vitesse du CPU que ce
test cherche à mesurer. Le test se lance à la fréquence **actuellement
réglée** (voir `Clock speed` ci-dessus, 1 à 10 MHz), et le résultat est
exprimé par comparaison à une exécution du même banc à **4,77 MHz
exactement** :

```
--- Test CPU speed ---
Banc d'essai en cours, duree: environ 30 secondes (Echap pour annuler)...
..............................
Ecoule: 34 s
Le 8088 roule 0% plus vite qu'un 8088 a 4,77 MHz.
Vitesse estimee:  4.77 MHz
```

Pendant le test, l'UART affiche un `.` par checkpoint (≈ 30 au total, tous
sur la même ligne — simple indicateur de progression compact) plutôt que
le nombre de secondes à chaque fois ; le LCD, lui, continue d'afficher
`Ecoule: NNN s` en direct (redessiné à chaque checkpoint). `Échap`
(vérification non bloquante, comme le dump mémoire) interrompt le test et
revient immédiatement au sous-menu. Si le pont cesse de répondre **en
cours de test** (et pas seulement à son lancement), le banc d'essai
s'arrête aussitôt avec un message d'erreur — plutôt que de continuer
silencieusement les checkpoints restants sans
aucun retour visible, ce qui ressemblerait à un blocage. À la fin,
n'importe quelle touche referme l'écran de résultat.

**Calibration** : le nombre d'itérations du banc d'essai
(`CPU_TEST_CHECKPOINTS` × `CPU_TEST_INNER_REPS` × 65536,
`solution-01.asm`) dure **34 secondes à 4,77 MHz**, mesuré sur le
matériel réel — d'abord à 69 s (`CPU_TEST_INNER_REPS` = 8), puis réduit
à 4 (34 s mesuré, très proche de la projection linéaire de 34,5 s) pour
se rapprocher du minimum de 30 s tout en le respectant.
`CPU_TEST_REF_SECONDS` — la durée de référence utilisée pour le
pourcentage/la vitesse estimée — est calibrée sur cette mesure (`34`).
Si la table de cycles du 8088 (donc la durée d'un checkpoint) change un
jour, relancer le test avec `Clock speed` réglé à `4,77 MHz` (option 5,
le réglage par défaut), noter la valeur *réelle* affichée par
`Ecoule: ...` à la fin, et la reporter dans `CPU_TEST_REF_SECONDS`. La
durée elle-même (`Ecoule: ...`) est, elle, toujours exacte, quelle que
soit cette calibration, puisqu'elle vient directement de la RTC du pont.

La **fréquence courante** est aussi affichée à droite de la première ligne du
**menu principal** (`1) Basic          4,77 MHz`), lue depuis un cache côté
8088 (pas d'aller-retour au pont à chaque redessin du menu principal) — mis
à jour à chaque visite du sous-menu `Clock speed`.

`3) Heure et date` règle la date/l'heure de la RTC du pont (`rtc_set`), en
deux invites chaînées — `Date: JJ-MM-AAAA` puis `Heure: HH:MM:SS` — saisies
au **clavier en décimal** (et non en hexadécimal, contrairement à `Edit
RAM`/`Dump memory` : une nouvelle routine dédiée, `ps2_read_dec_editable`,
lib/ps2.asm). Envoyée telle quelle au pont, qui valide lui-même les bornes
(`applyTime()`, côté STM32) et ignore silencieusement une valeur hors
bornes — pas de confirmation ni de validation côté 8088, comme le reste du
moniteur.

`4) Information` affiche un écran récapitulatif :

```
--- Information ---
20-09-2026 14:35:07
BIOS:1.0 STM:1.0
RAM:126K CPU:  4.77 MHz
Disque:23/8192KB
(Echap: retour au sous-menu Configuration)
```

Seule la ligne date/heure est **rafraîchie en direct** (dès que la seconde
change, en interrogeant la RTC du pont en boucle) ; les 4 autres valeurs
(version du BIOS/ROM, version du firmware du pont, taille de la RAM, espace
utilisé/disponible sur la flash, fréquence d'horloge) sont interrogées une
seule fois à l'entrée. La version du **firmware du pont** utilise une
**nouvelle commande de protocole** (`03h`, voir
`arduino/8088_bridge_stm32/README.md`) — un pont pas encore reflashé avec
cette version répond `?` à sa place plutôt que de faire échouer tout
l'écran (seule la date/heure initiale exige un pont fonctionnel). L'espace
disque **utilisé** est calculé par soustraction (`8192 Ko - espace libre` —
capacité *nominale* de la puce flash W25Q64, 8 Mo ; aucune commande de
protocole ne rapporte la capacité totale).

**Dump memory** (option 1 du menu Memory functions) : demande une adresse de
**départ** puis une adresse de **fin**, chacune saisie au format
`SEGMENT:OFFSET` (4+4 chiffres hexadécimaux, retour arrière pour
corriger — même mécanique que `Edit RAM` ci-dessous) :

```
Start: 0x0000:0x0000
End:   0x0000:0x0FFF
```

... puis dump (hexadécimal+ASCII complets sur l'UART ; hexadécimal
condensé, 4 octets par ligne sur les 4 lignes, avec ASCII sur les
lignes 1/3, sur le LCD I2C) tous les octets de cette plage
**physique**, 16 octets par ligne, via `dump_line`. Une seule action
(`dump_memory_action`) remplace les deux anciennes options fixes
("Dump ROM" / "Dump first 4k RAM") : elle fonctionne indifféremment
pour la ROM (ex. `C000:0000` à `F000:FFFF` pour toute la ROM, 256 Ko),
la RAM (ex. `0000:0000` à `1000:FFFF` pour toute la RAM, 128 Ko),
**tout l'espace d'adressage matériel en une seule fois** (`0000:0000`
à `F000:FFFF`, jusqu'à l'adresse physique `FFFFFh` — 20 lignes
d'adresse, voir le piège `FFFF:FFFx` ci-dessous) ou n'importe quelle
plage intermédiaire, y compris à cheval sur plusieurs dizaines de
frontières de segment. Si l'adresse de fin est antérieure à celle de
départ, la plage est rejetée (message d'erreur UART, rien n'est
dumpé).

L'arrêt normal compare l'adresse physique **courante** (32 bits) à
l'adresse physique de fin à chaque ligne, plutôt que de précalculer un
nombre total de lignes : pour la plage maximale ci-dessus, ce total
vaudrait exactement 65536, qui ne tient pas dans un mot de 16 bits
(débordement silencieux). Cas limite géré séparément : si l'avance de
segment déborde elle-même 16 bits (segment déjà `F000h`-`FFFFh`), la
plage maximale du matériel vient d'être entièrement couverte — le dump
s'arrête plutôt que de continuer sur un segment erroné (qui reviendrait
à `0000h`).

⚠️ **Piège classique — les 16 derniers octets de la ROM** : ce ne sont
**PAS** `FFFF:FFF0`-`FFFF:FFFF`. Le 8088 n'a que 20 lignes d'adresse
(pas de ligne A20) : l'adresse physique réelle (`segment×16 + offset`)
**boucle** au-delà de `FFFFFh`, donc `FFFF:FFF0` calcule en réalité
`10FFE0h`, qui boucle à `0FFE0h` — de la RAM basse, pas la ROM. La
bonne plage utilise le même segment que le vecteur de reset matériel :
`F000:FFF0` à `F000:FFFF` (`F000h×16 + FFF0h = FFFF0h`, les 16
derniers octets physiques de la ROM : vecteur de reset + signature).

La touche **Échap** (clavier PS/2 ou terminal) interrompt un dump en cours
et retourne immédiatement au menu Memory functions. Vérifiée de façon
**non bloquante** avant chaque ligne (`ps2_poll_char` : lit une touche reconnue
si elle attend dans un tampon circulaire rempli par l'interruption `IR1`, sans
jamais attendre — les relâchements de touches sont consommés au passage).
Même technique pour le test de vitesse du CPU et l'écran Information
(sous-menu Configuration) : avant, le relâchement de la touche qui lançait
l'action bloquait ces écrans jusqu'à une nouvelle frappe au clavier PS/2.

**Edit RAM** (option 2 du sous-menu Memory functions — seul point d'accès
depuis la refonte du menu principal, qui n'offre plus cette option
directement) : éditeur de RAM **par plage, avec tampon** (annulation
possible) — remplace la version à adresse unique du premier jalon.
Demande, avec retour arrière
possible sur chaque saisie :

```
Address: 0x1000:0x0400
Size:    0x0400
```

L'adresse de départ est **complète, segment:offset** (4+4 chiffres
hexadécimaux — même saisie à 2 champs que `Dump memory` ci-dessus) :
**n'importe quel segment** est accepté (pas seulement `0000h`, comme avant
cette adresse complète — `1000h`/`VAR_SEG`, où vivent le BASIC et l'état du
BIOS, y est maintenant directement accessible). Si le segment saisi est
`0000h`, l'offset **doit être ≥ `0x0400`** (juste après l'IVT, 256
entrées × 4 octets = 1024 octets — voir [Interruptions logicielles
type BIOS](#interruptions-logicielles-type-bios-int-10h--int-16h)) :
une adresse dans l'IVT est **rejetée** (message d'erreur, retour
immédiat au menu) pour ne jamais pouvoir corrompre les gestionnaires
d'interruption — cette protection ne s'applique qu'au segment `0000h`,
seul endroit où vit l'IVT. La taille doit être entre `1` et `0x0400`
(1024) octets, et la plage résultante ne doit pas déborder `0xFFFF`
(rester dans le segment saisi) — même rejet sinon.

Contrairement au premier jalon, **rien n'est écrit dans la vraie RAM
pendant l'édition** : toute la plage est copiée dans un **tampon de
travail** (1024 octets, `EDIT_BUFFER_OFF`) dès le départ, et l'édition
ne modifie que ce tampon :
- **Échap** — **annule** toute l'édition : le tampon est abandonné, la
  RAM réelle n'est pas touchée.
- **`Q`/`q`** — **valide** : le tampon est recopié dans la RAM réelle.

Le **LCD** affiche 5 colonnes × 4 lignes **visibles** à la fois, mais la
plage peut en contenir jusqu'à 1024 octets (205 lignes logiques) : les
flèches **haut/bas font défiler** la fenêtre visible d'une ligne dès
que le curseur en sortirait — contrairement au premier jalon, limité à
la grille initialement affichée.

**Vue plein écran sur le terminal** (séquences ANSI, `edit_ram_draw_terminal`) :
l'écran est effacé une seule fois à l'entrée (`ESC[2J ESC[H`), puis la grille
est redessinée **en place** (chaque ligne repositionnée par `ESC[l;cH` et
terminée par `ESC[K`) : titre, 8 lignes avec l'adresse réelle, ligne
d'aide — et le **curseur du terminal est placé sur la case courante**, où
s'affichent les chiffres tapés. La grille est découpée en **pages de 8
lignes** (40 octets) qui suivent le curseur ; la navigation est celle du
LCD. L'écran est effacé à la sortie (Échap/`Q`) pour que le menu reparte
en haut.

```
=== Editeur RAM ===

0400: 00 01 02 03 04
0405: 05 06 07 08 09
040A: 0A 0B 0C 0D 0E
...
Fleches:deplacer 0-9/A-F:valeur Entree:valider Q:enregistrer Echap:annuler
```

Le LCD affiche la **même étiquette d'adresse** en tête de chaque ligne
(`SSSS:`, 5 caractères, sans espace après les deux-points), suivie de
la grille compacte (5 cases `XX ` = 15 caractères) : **exactement 20
caractères**, la largeur de l'afficheur — utile pour se repérer en
défilant, sans jamais perdre de vue à quelle adresse réelle on édite.

⚠️ **La grille est volontairement à 5 colonnes, pas 6** : avec 6
colonnes (18 caractères), ajouter la moindre étiquette d'adresse
dépasserait les 20 caractères disponibles, et ce débordement, sur cet
afficheur 4×20 « type A » (`LCD_LINE1`↔`LCD_LINE3` et
`LCD_LINE2`↔`LCD_LINE4` partagent chacun un même bloc de 40 octets de
DDRAM), corromprait le début de la ligne appairée dessinée juste après
— bug déjà trouvé sur le matériel réel avec l'ancien format 6 colonnes
+ étiquette (le premier caractère de l'adresse des lignes 1 et 2
disparaissait). Ne jamais réaugmenter `EDIT_COLS` sans retirer
l'étiquette, ou l'inverse.

| Touche | Effet |
|---|---|
| Flèches gauche/droite | Déplacent la case sélectionnée **dans sa ligne** (fixées aux bords de colonne) |
| Flèches haut/bas | Déplacent la case sélectionnée **d'une ligne logique**, avec **défilement** de la fenêtre visible si nécessaire (fixées aux bords de la plage) |
| Chiffre hexa (`0-9`/`A-F`) | Compose une nouvelle valeur pour la case courante (1 ou 2 chiffres, retour arrière pour corriger) — écrite **dans le tampon** |
| Entrée | Valide la saisie dans le tampon (ignorée si aucun chiffre tapé), puis avance automatiquement à la case suivante (`edit_ram_advance`) |
| `Q` / `q` | **Enregistre** le tampon dans la RAM réelle, retour au menu |
| Échap | **Annule** — la RAM réelle n'est pas modifiée, retour au menu |

**Registres CPU** (option 3 du menu Memory functions — `registers_dump_action`) :
affiche l'état courant des registres du 8088 (`AX`/`BX`/`CX`/`DX`/`SI`/
`DI`/`BP`/`SP`/`CS`/`DS`/`ES`/`SS`/`IP`/`FLAGS`). **Capture immédiate à
l'entrée** (avant le moindre usage des registres généraux comme
espace de travail pour composer l'affichage) : chaque registre est
empilé puis relu via `[bp±N]` (`BP` fixé juste après un `push bp` +
`mov bp, sp`, le même « prologue de trame de pile » qu'un compilateur
C — les valeurs empilées *avant* ce point, càd `BP` original et
l'adresse de retour, restent à des décalages **positifs** malgré tous
les `push` qui suivent, puisque `BP` lui-même ne bouge plus). `IP`
affiché = l'adresse de retour déjà empilée par le `CALL` qui a mené
ici — exactement ce qu'un débogueur montrerait à un point d'arrêt
juste après ce `CALL`. `SP` affiché = celui vu par l'appelant, *avant*
ce `CALL` (`BP+4` : avant que `CALL` empile `IP` et avant notre propre
`push bp`) — un simple calcul, jamais relu depuis la pile.

L'UART affiche chaque registre en **hexadécimal PUIS en binaire**
(`uart_tx_bin_word`), 2 registres par ligne (format inspiré de
**DEBUG.COM**, le débogueur DOS classique, étendu avec le binaire).
Les `FLAGS` ont leur **propre ligne** (après une ligne vide), avec
hexadécimal, binaire, **et** mnémoniques (`OV`/`NV`, `DN`/`UP`,
`EI`/`DI`, `NG`/`PL`, `ZR`/`NZ`, `AC`/`NA`, `PE`/`PO`, `CY`/`NC` — dans
l'ordre `OF DF IF SF ZF AF PF CF`, le mnémonique « actif » en jaune) :

```
AX=0033  0000000000110011    BX=0000  0000000000000000
CX=0006  0000000000000110    DX=0000  0000000000000000
SI=0000  0000000000000000    DI=0000  0000000000000000
SP=0FFC  0000111111111100    BP=0000  0000000000000000
DS=1000  0001000000000000    ES=1000  0001000000000000
SS=1000  0001000000000000    CS=C000  1100000000000000
IP=0242  0000001001000010

FLAGS=0246  0000001001000110  NV UP EI PL NZ NA PO NC
```

Le LCD (80 caractères, trop peu pour tout à la fois) **pagine sur 2
écrans** (page 1 : `AX`/`BX`/`CX`/`DX`/`SI`/`DI`/`SP`/`BP` ; page 2 :
`CS`/`IP`/`DS`/`ES`/`SS`/`FL` + les 8 `FLAGS` décodés en une lettre
chacun sur la ligne 4, **majuscule si actif, minuscule sinon** —
`O D I S Z A P C`) :

| Touche | Effet |
|---|---|
| Flèches gauche/droite | Bascule entre les 2 pages du LCD |
| Toute autre touche (sauf Échap) | Ignorée — pas de redessin inutile |
| Échap | Retour au menu Memory functions |

**Edit+Run RAM** (option 4 du menu Memory functions — `edit_run_action`) : même
éditeur par plage/tampon qu'`Edit RAM` ci-dessus, mais à une **adresse
fixe**, `1000:0000` (le **deuxième bloc de 64 Ko** de RAM, aussi
accessible depuis `Edit RAM` maintenant que son adresse de départ couvre
n'importe quel segment — voir plus haut), et avec en plus la possibilité
d'**exécuter** le code qui vient d'y être saisi. **Aucune saisie**
(accélère les tests) : l'adresse (`0000h` dans ce segment) et la taille
(**toujours 255 octets**, `EDIT_RUN_SIZE`) sont fixes — la grille
s'affiche immédiatement, sans prompt.

| Touche | Effet |
|---|---|
| Flèches gauche/droite/haut/bas | Identiques à `Edit RAM` |
| Chiffre hexa (`0-9`/`A-F`) | Compose une nouvelle valeur — le **2e chiffre valide et avance automatiquement** (Entrée n'est **plus nécessaire** pour un octet complet ; elle reste disponible pour valider un octet d'un seul chiffre) |
| `Q` / `q` | **Enregistre** le tampon dans la RAM réelle (`1000:0000`), **sans exécuter**, retour au menu |
| `R` / `r` | **Enregistre** (comme `Q`/`q`), **PUIS EXÉCUTE** le code à `1000:0000` (voir ci-dessous), affiche les registres résultants sur l'UART, **puis revient à la fenêtre d'édition** (pas au menu — permet de relancer `R` sans ressaisir le code) — **reconnue à tout moment, même au milieu de la saisie d'un octet** (le chiffre partiel non encore validé est alors abandonné, rien n'est écrit pour cette case) |
| Échap | **Annule** — la RAM réelle n'est pas modifiée, retour au menu |

L'exécution se fait par un **`CALL FAR` immédiat** vers `1000:0000`
(opcode `9A`, encodé directement par NASM pour `call seg:off` avec des
constantes). ⚠️ **Le code saisi doit obligatoirement se terminer par
`RETF`** (retour lointain, dépile `IP` **et** `CS`) — **jamais** un
`RET` (proche) : celui-ci ne dépilerait que `IP` et laisserait `CS`
empilé, corrompant la pile et plantant la carte au retour.

`CALL`/`RETF` ne modifient jamais un registre général ni les `FLAGS` :
immédiatement après le retour, chaque registre reflète donc exactement
ce que le code exécuté a laissé. Même technique de capture par trame
de pile que `Registres CPU` ci-dessus (chaque registre empilé puis
relu via `[bp±N]`), affichée **uniquement sur l'UART** (demande
explicite — pas de LCD pour cet affichage), au même format hexa+binaire
avec `FLAGS` sur sa propre ligne :

```
=== Execution terminee (1000:0000, RETF) - Registres ===
AX=0005  0000000000000101    BX=0000  0000000000000000
...
FLAGS=0246  0000001001000110  NV UP EI PL NZ NA PO NC
```

⚠️ Si le code exécuté modifie `SS` sans le restaurer, l'affichage des
registres qui suit (qui utilise `push`/`pop` pour lire la pile)
ciblerait une pile invalide — risque inhérent à l'exécution de code
arbitraire, comme la commande `G` de DEBUG.COM.

`AX`/`BX`/`CX`/`DX`/`SI`/`DI` sont **persistants d'une exécution à
l'autre** (appuis successifs sur `R`) : restaurés juste avant chaque
`CALL FAR`, puis re-sauvegardés juste après chaque retour — sans quoi
ces registres vaudraient ce que le code de menu/clavier exécuté
*entre* deux appuis sur `R` (lecture du clavier, redessin de la
grille, etc.) leur aurait laissé, rendant impossible tout test
cumulatif (ex. `add ax,2` répété, censé incrémenter `AX` à chaque
exécution). Remis à `0` **une seule fois**, à l'entrée dans une
nouvelle session d'édition (pas à chaque exécution). `SP`/`BP`/`CS`/
`DS`/`ES`/`SS`/`FLAGS` ne sont **pas** persistés (affichés tels que
laissés par la dernière exécution, sans lien avec les précédentes).

**Exemple de test minimal** à saisir à `1000:0000` (2 octets) :

```
B8 34 12    ; mov ax, 1234h
CB          ; retf
```

Après `R`/`r`, le terminal affiche `AX=1234` (hexa+binaire), **sous la
grille** (à partir de la ligne 14 : le redessin qui suit n'efface pas les
registres, il ne réécrit que la grille). Les 6
registres généraux (`AX`/`BX`/`CX`/`DX`/`SI`/`DI`) sont **sans risque**
à utiliser pour ce genre de test : capturés et affichés tels quels,
sans qu'aucune autre partie du firmware dépende de leur valeur pour
continuer à fonctionner après le retour. À **éviter** en revanche sans
les restaurer explicitement avant `RETF` :
- **`DS`** — le firmware suppose `DS = CS` en permanence (c'est ainsi
  qu'il retrouve ses propres chaînes de texte en ROM) ; le changer sans
  le restaurer ferait planter ou afficher n'importe quoi l'affichage
  des registres lui-même.
- **`SS`** — voir l'avertissement ci-dessus.
- **`SP`/`BP`** — capturés et affichés correctement, mais à modifier
  franchement (ex. `mov sp, ...`) seulement si ce cas précis est
  volontairement celui testé.

**IVT** (option 5 du menu Memory functions — `ivt_dump_action`, page 2
du LCD, voir plus haut) : affiche le contenu des **40 premiers**
vecteurs de l'IVT (`INT 00h`-`27h`, `IVT_DUMP_COUNT`) — limite
volontaire : les vecteurs qui comptent dans ce projet (`00h`-`1Fh`
réservés Intel, `08h` IR0/8259, `10h`/`16h` "esprit BIOS") vivent tous
sous 40 ; le reste de la table jusqu'à `FFh` ne serait qu'une longue
répétition de `int_not_implemented`.

Sur l'UART, toute la table d'un coup, une seule fois à l'entrée :

```
INT 10h -> C000:1234 : int10h_handler -> Gestion de l'affichage (LCD I2C/UART)
INT 11h -> C000:0AA6 : int_not_implemented -> Non implementee
```

Les vecteurs **implémentés** (`int10h_handler`/`int16h_handler`/
`irq0_test_handler`/`irq1_arduino_handler`) s'affichent **en vert** ; tous
les autres (en pratique, systématiquement `int_not_implemented`) sans
couleur. L'identification compare l'**offset** lu dans chaque entrée de
l'IVT aux adresses des 4 gestionnaires réels connus — le segment n'est
pas vérifié séparément (tous les gestionnaires vivent dans la même ROM).

Sur le LCD I2C, une grille **défilante** (40 vecteurs, 4 visibles à la
fois, un par ligne — pas de couleur possible) :

```
00h  C000:0AA6
01h  C000:0AA6
02h  C000:0AA6
03h  C000:0AA6
```

| Touche | Effet |
|---|---|
| Flèches haut/bas | Défilent d'un vecteur (fixées aux bords de la table) |
| Échap | Retour au menu Memory functions |

| Option | Action | Détail |
|---|---|---|
| Tiny Basic | `tiny_basic` (`lib/tiny_basic.asm`) | Interpréteur Tiny BASIC piloté par le terminal UART — voir [Tiny BASIC](#tiny-basic-libtiny_basicasm) |
| BASIC | `basic_run` (`lib/basic.asm`) | BASIC « GW-BASIC-like » (chaînes, flottants, `RND`, `PEEK`/`POKE`) piloté par le terminal UART — voir [BASIC](#basic--gw-basic-like--libbasicasm) |
| Test RAM | `test_ram` | Teste la RAM 128 Ko, rapporte via UART+LCD (129 024 octets testés depuis l'agrandissement de la zone réservée pour le tampon d'Edit RAM — voir plus bas) |
| Dump memory | `dump_memory_action` (consolidé) | Demande adresse de départ + de fin (`SEGMENT:OFFSET`), dump via `dump_line` — remplace `rom_dump`/`ram_dump_4k` |
| Edit RAM | `edit_ram_action` (par plage, avec tampon) | Voir ci-dessus |
| Registres CPU | `registers_dump_action` | Voir ci-dessus |
| Edit+Run RAM | `edit_run_action` (édite et exécute à `1000:0000`) | Voir ci-dessus |
| IVT | `ivt_dump_action` (table des 256 vecteurs) | Voir ci-dessus |
| (Échap) | — | Retour au menu principal depuis le menu Memory functions (remplace l'ancienne option affichée "9) Home menu") |

État partagé (`VAR_SEG`, voir `include/hardware.inc`) : `edit_ram_action`
utilise `EDIT_BASE_OFF`/`EDIT_SIZE_OFF` (adresse/taille saisies),
`EDIT_CURSOR_OFF` (position linéaire du curseur dans le tampon) et
`EDIT_WINDOW_ROW_OFF` (ligne logique affichée en haut de l'écran), en
plus du tampon `EDIT_BUFFER_OFF` (1024 octets) lui-même.
`dump_memory_action` y conserve de façon similaire les quatre valeurs
saisies (`DUMP_START_SEG_OFF`/`DUMP_START_OFF_OFF`/`DUMP_END_SEG_OFF`/
`DUMP_END_OFF_OFF`) ainsi que l'adresse physique de fin (32 bits,
`DUMP_END_PHYS_LO_OFF`/`DUMP_END_PHYS_HI_OFF`), comparée à l'adresse
physique courante à chaque ligne (voir plus bas, "couvrir plus de
64 Ko"). Cette zone réservée fait maintenant **2 Ko** (agrandie de 1 Ko
pour loger le tampon d'Edit RAM), d'où le nombre d'octets testés par
`test_ram` légèrement réduit.

⚠️ **Limitation connue** (voir Directives.md) : la ligne 4 du LCD
pendant un dump affiche "`Ligne: NNN`" (numéro de ligne, 3 chiffres via
`lcd_tx_dec3`) sans dénominateur — au-delà de 999 lignes (15 984
octets) cet affichage redevient incorrect (cosmétique seulement, le
dump UART reste toujours exact quelle que soit la taille de la plage).
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

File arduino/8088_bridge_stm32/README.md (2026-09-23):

# Pont STM32 (WeAct Black Pill V3.1, STM32F411) ↔ 8088

Portage de `../ve2cuy_bridge/ve2cuy_bridge.ino` (Arduino UNO) sur une
**Black Pill V3.1** (STM32F411CEU6, 100 MHz, USB natif). **Même protocole** côté
8088 : le firmware de `Solution-01` n'est pas modifié (étape 1 du portage).

> ✅ **Validé sur le matériel** (étape 1) : téléversement DFU, LED, LCD I2C, clavier
> PS/2, terminal USB et toutes les fonctions du menu du 8088 (dont le BASIC) avec
> `BUS_HIGH_NIBBLE_REVERSED 1`. Le câblage et les niveaux 3,3 V / 5 V restent à
> vérifier pour tout nouveau montage — voir « Vérifications ».

## Câblage

| Signal | Black Pill | 8255 / autre | Remarques |
|---|---|---|---|
| Bus `D0`-`D3` | **PB12, PB13, PB14, PB15** | `PA0`-`PA3` (mode 2) | bidirectionnel, sans pull |
| Bus `D4`-`D7` | **PB6, PB7, PB8, PB9** | `PA4`-`PA7` | idem (deux quartets, ordre direct D0 = PA0) |
| `ACK#` | **PB0** | `PC6` | sortie **drain ouvert** + 10 kΩ vers +5 V |
| `STB#` | **PB1** | `PC4` | sortie **drain ouvert** + 10 kΩ vers +5 V |
| `OBF#` | **PA8** | `PC7` | entrée |
| Canal bit 0 / bit 1 | **PA9 / PA10** | `PB0` / `PB1` (Port B) | entrées |
| `TAG` | **PB4** | `PC0` | sortie : `0` = scan code, `1` = octet UART |
| `IBF` (facultatif) | **PA15** | `PC5` | voir `USE_IBF` ; non câblé = « libre » (pull-down interne) |
| `TAG1` (**réponses**) | **PB5** | `PC1` (broche 15 du 8255A) | **sortie seulement** (PB5 n'est pas tolérante 5 V). **À câbler** pour l'horloge RTC, avec une **résistance de 10 kΩ vers la masse** sur `PC1` : `1` = l'octet envoyé est une réponse à une commande |
| **Horloge du 8088** | **PA3** | broche `CLK` (19) du 8088 | **PWM matériel** (`TIM2` canal 4), duty cycle fixe 1/3, 1-10 MHz (défaut 4,77 MHz) — remplace le fil depuis l'Arduino UNO R4 de `projets/Clock-8088/`. `PA3` servait à `TAG2`/`PC2` (jamais câblée) : **si votre montage câble `TAG2`, cette broche est prise et ne convient plus** |
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

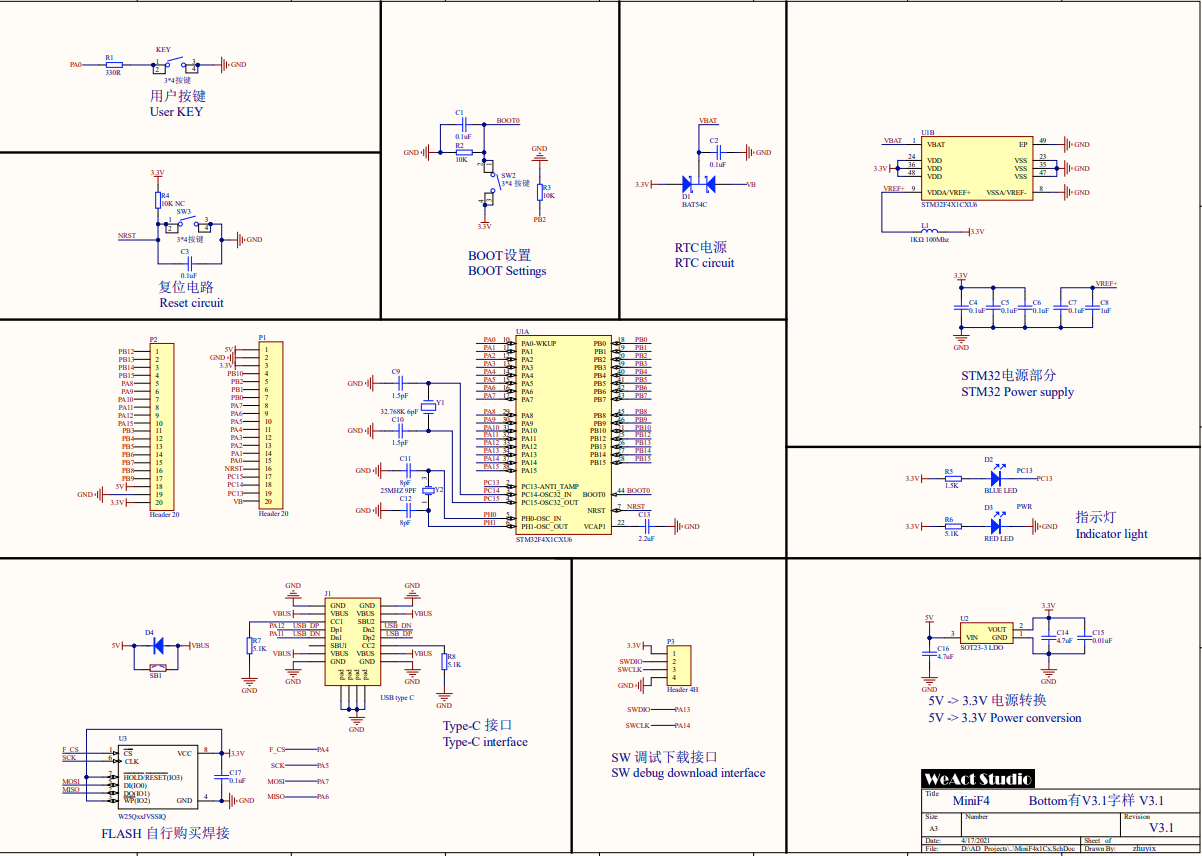
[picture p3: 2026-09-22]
medias/STM32F411CE-Black-Pill-Board-Schematic-Diagram.webp

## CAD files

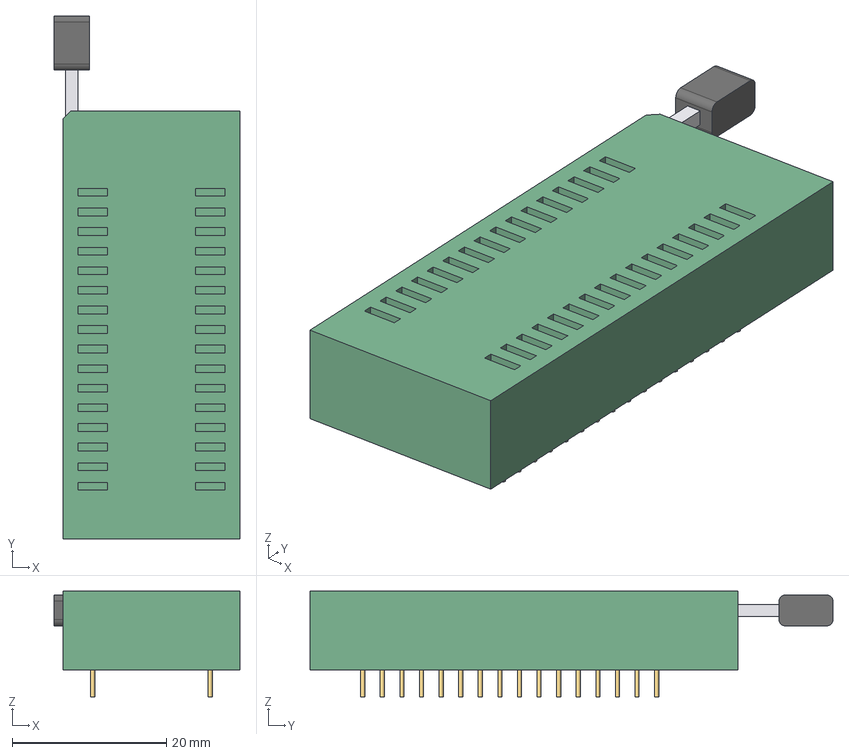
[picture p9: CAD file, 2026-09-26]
kicad/3dmodels/DIP_Socket-32_W11.9mm_W12.7mm_W15.24mm_W17.78mm_W18.5mm_3M_232-1285-00-0602J.step
24.1 x 67.8 x 13.7 mm
boitier
levier
poignee
broches

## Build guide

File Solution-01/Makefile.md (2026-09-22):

# Comment fonctionne le Makefile

## Variables

- `NASM` / `NASMFLAGS` : l'assembleur et ses options (`-f bin` = sortie binaire brute, sans format d'exécutable)
- `ROM_BIN`, `LCD_BIN`, `UART_BIN`, `UTILS_BIN` : les chemins des `.bin` produits
- `ROM_OUT` : destination finale de la ROM sur le partage réseau (`Z:\Partage\Alain\rom.bin`)
- `CHECK_DIR` : dossier local `build/check` pour les `.bin` jetables de `check-modules` (évite `/tmp`, peu fiable quand make natif Windows invoque le shell MSYS de Git)

## Les cibles (targets)

### `all`

Cible par défaut si on tape juste `make`. Dépend de `rom` et `lib` — construit tout.

### `rom`

1. `$(ROM_BIN)` est une règle avec ses propres dépendances (`solution-01.asm` + tous les `.inc`/`.asm` inclus) → si l'un d'eux est plus récent que `solution-01.bin`, make relance `nasm` pour le régénérer.
2. Une fois `solution-01.bin` prêt, la cible `rom` elle-même crée le dossier `Z:\Partage\Alain\` si besoin (`mkdir -p`) et copie le binaire là-bas (`cp`).

C'est le principe de base de make : chaque cible peut avoir des **prérequis** (fichiers listés après `:`), et sa recette (les lignes indentées en dessous) ne s'exécute que si la cible n'existe pas encore ou est plus vieille qu'un de ses prérequis. Ça évite de tout réassembler à chaque fois.

### `rom-fr` / `rom-en`

Bilinguisme (voir `README.md`, section « Bilinguisme (FR/EN) »): produisent respectivement `solution-01-fr.bin` (français - identique au comportement de `rom`, sans aucun `-d`) et `solution-01-en.bin` (anglais - `nasm -dLANG_EN=1`). `rom-en` ajoute `-w-error=label-redef-late`: la taille légèrement différente des textes anglais retarde la convergence normale de NASM (plusieurs passes) sur certains sauts éloignés du fichier - inoffensif (deux compilations successives produisent un binaire identique), `rom`/`rom-fr` n'en ont jamais eu besoin.

### `lib`

Construit les modules individuels (`lcd.bin`, `uart.bin`, `utils.bin`, `lcd_i2c.bin`, `ps2.bin`, `tiny_basic.bin`, `basic.bin`), chacun avec ses propres dépendances. Le `| lib/bin` après les deux-points est un **prérequis "order-only"** : ça garantit que le dossier `lib/bin` existe avant d'écrire dedans, mais sans forcer un réassemblage si le dossier est juste "plus récent" que le `.bin`.

### `check-modules`

Assemble chaque module de la lib **séparément** (pas juste via `solution-01.asm` qui les inclut tous) pour vérifier qu'ils compilent chacun de façon autonome. Utilise le même mécanisme `| $(CHECK_DIR)` pour créer `build/check` au besoin.

### `check`

Dépend de `$(ROM_BIN)` (donc réassemble si besoin), puis appelle `check_rom.py` pour valider la structure du binaire (taille, vecteur de reset, signature).

### `test`

Lance les bancs d'essai sous émulateur (Unicorn, `pip install unicorn numpy`) : `tests/tb_test.py` (Tiny BASIC), `tests/fl_test.py` (bibliothèque flottante du BASIC) et `tests/basic_test.py` (BASIC « GW-BASIC-like », environ 2 minutes ; sources listées dans `BAS_SRC`). Le premier assemble `tests/tb_test.asm` (avec `lib/tiny_basic.asm`, en mode « stubs » puis avec les vraies routines `uart_*`) dans `build/` et vérifie les sorties BASIC, le retour au menu et les zones de RAM écrites. Non lancée par `all`/`check` (dépendance Python facultative).

### `clean`

Supprime tous les `.bin` générés et le dossier `build/check`.

## Utilisation typique

```sh
make                 # = make all : construit tout
make rom             # juste la ROM + copie vers Z:
make lib             # juste les modules
make check           # assemble la ROM puis la valide
make check-modules   # teste que chaque module s'assemble seul
make map             # plan (MAP) de la ROM : zones, tailles, espace libre (rom_map.py)
make clean           # nettoie
```

## Point important

Il faut toujours lancer `make` **depuis le dossier `Solution-01/`**, jamais depuis un sous-dossier, car tous les chemins (relatifs) et les `%include` dans les `.asm` en dépendent.

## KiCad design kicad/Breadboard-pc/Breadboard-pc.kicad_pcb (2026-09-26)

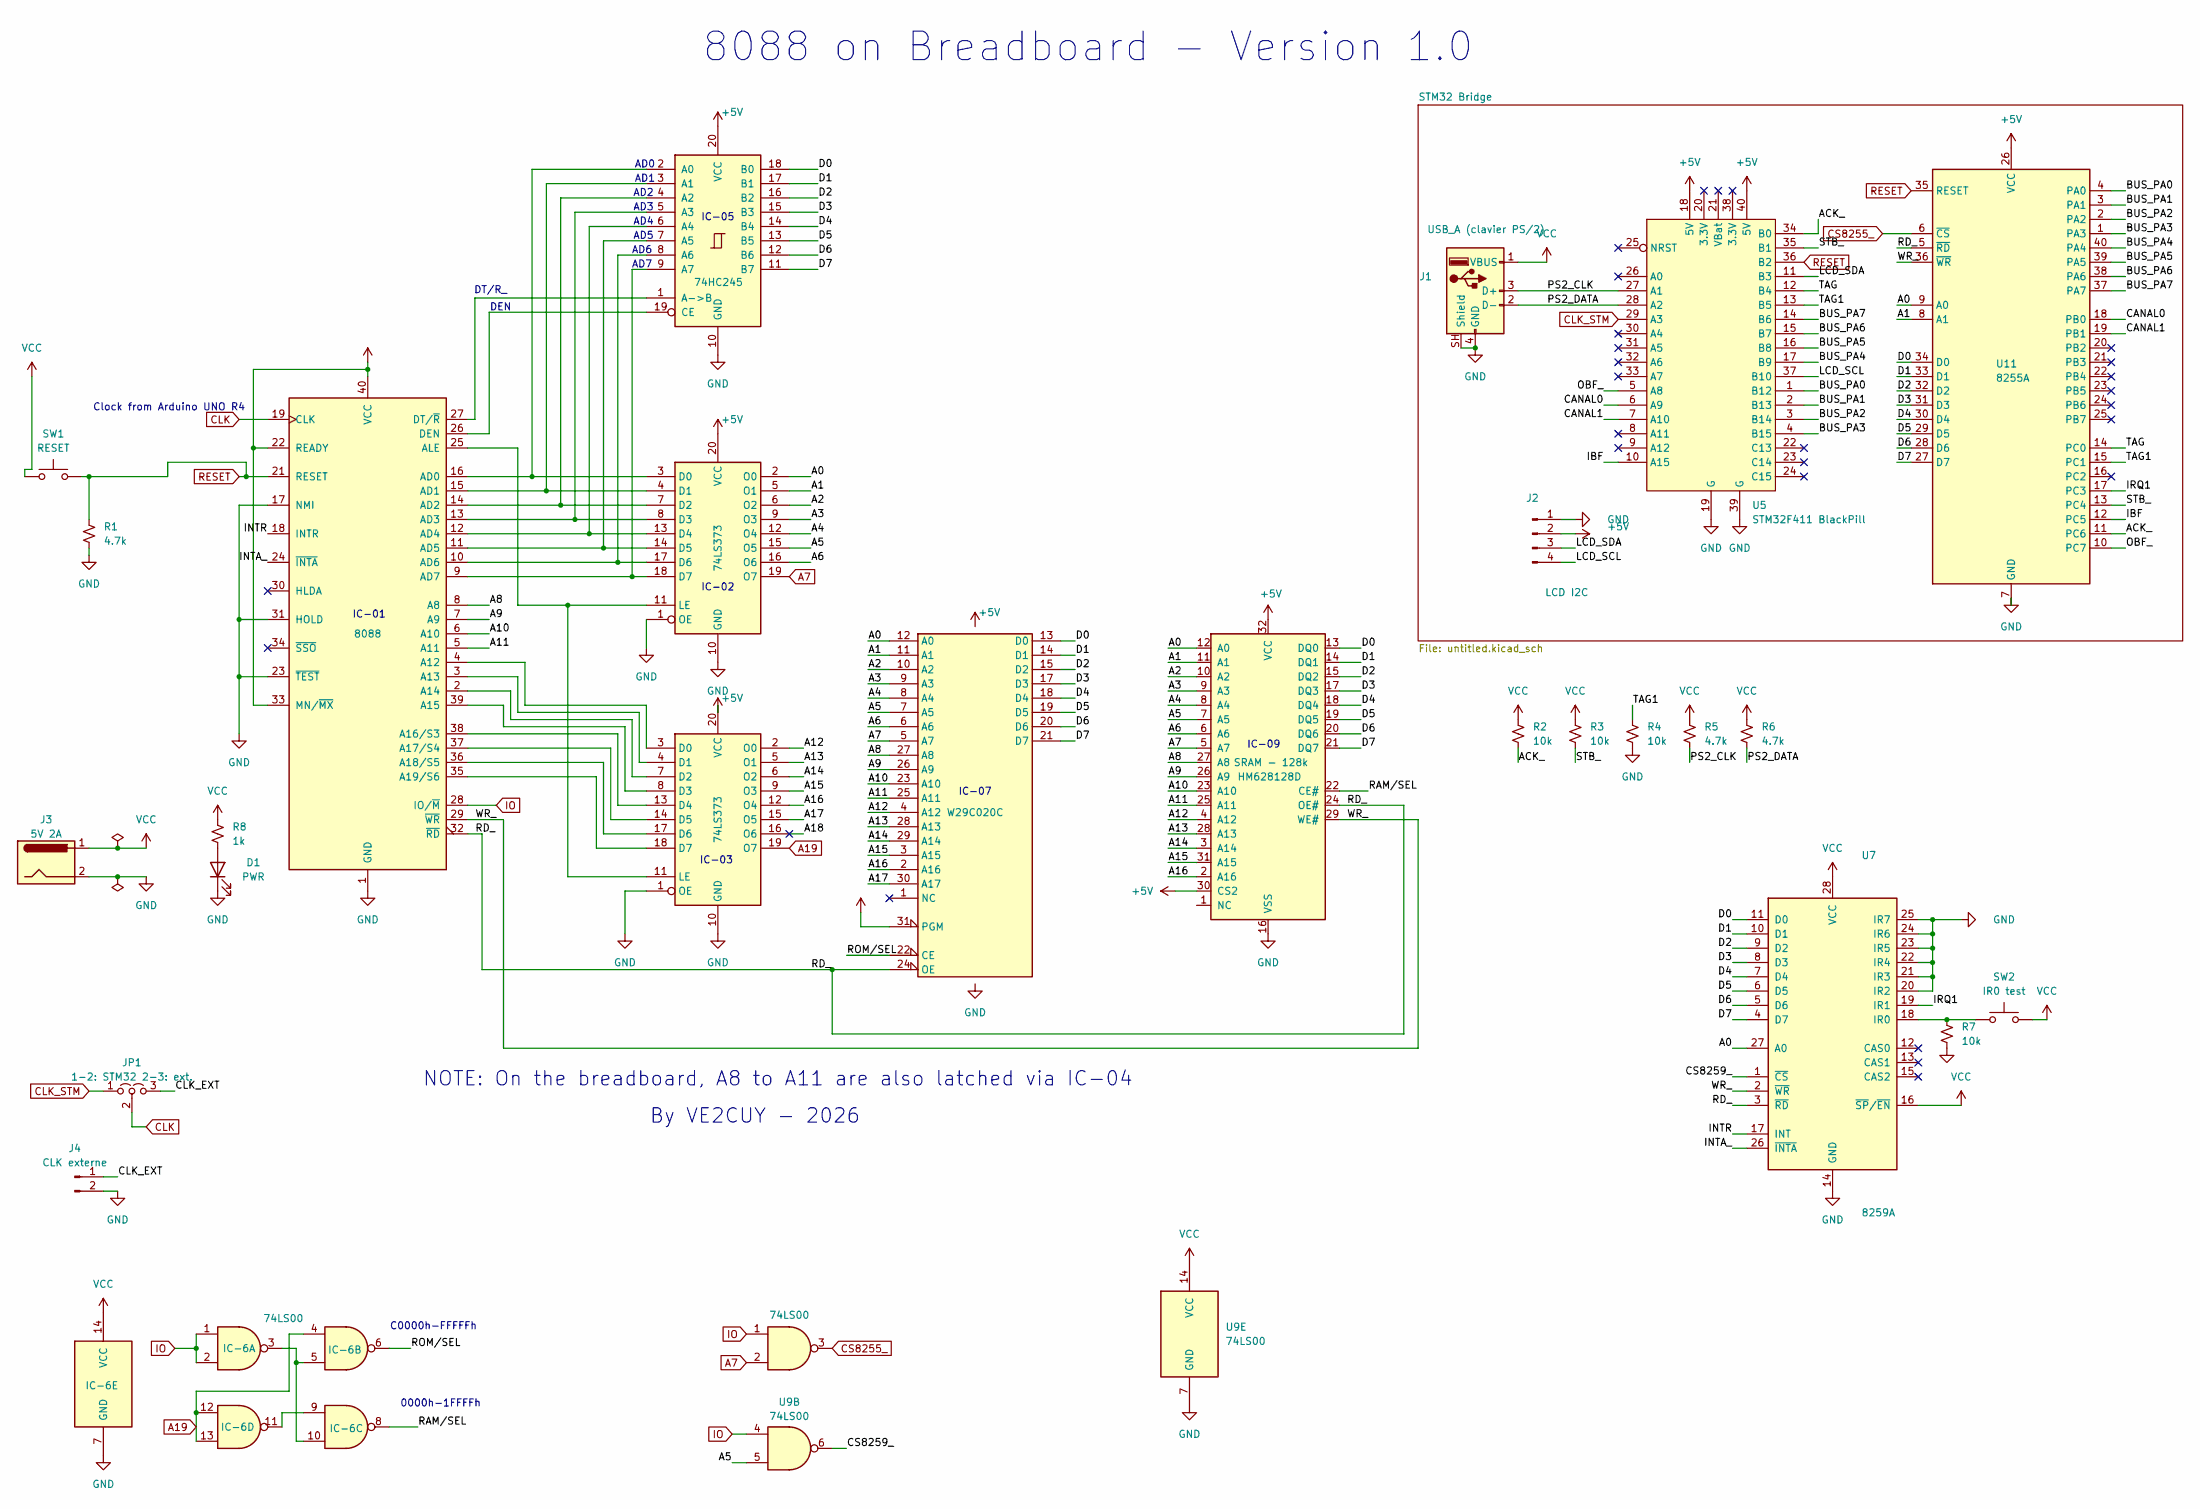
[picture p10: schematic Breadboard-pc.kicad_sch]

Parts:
D1: PWR; LED_D3.0mm
IC-6: 74LS00; DIP-14_W7.62mm
J1: USB_A (clavier PS/2); USB_A_Molex_67643_Horizontal
J2: LCD I2C; PinHeader_1x04_P2.54mm_Vertical
J3: 5V 2A; BarrelJack_Horizontal
J4: CLK externe; PinHeader_1x02_P2.54mm_Vertical
JP1: 1-2: STM32 2-3: ext.; PinHeader_1x03_P2.54mm_Vertical
R1, R5, R6: 4.7k; R_Axial_DIN0207_L6.3mm_D2.5mm_P7.62mm_Horizontal
R2, R3, R4, R7: 10k; R_Axial_DIN0207_L6.3mm_D2.5mm_P7.62mm_Horizontal
R8: 1k; R_Axial_DIN0207_L6.3mm_D2.5mm_P7.62mm_Horizontal
SW1: RESET; SW_PUSH_6mm
SW2: IR0 test; SW_PUSH_6mm
U1: 8088; DIP-40_W15.24mm
U2, U3: 74LS373; DIP-20_W7.62mm
U4: W29C020C; DIP_Socket-32_W11.9mm_W12.7mm_W15.24mm_W17.78mm_W18.5mm_3M_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
U5: STM32F411 BlackPill; STM32F411_Black_Pill
U6: 74HC245; DIP-20_W7.62mm
U7: 8259A; DIP-28_W15.24mm
U8: HM628128D; DIP-32_W15.24mm
U9: 74LS00; DIP-14_W7.62mm
U11: 8255A; DIP-40_W15.24mm

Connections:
/A0: U2.2 (O0), U4.12 (A0), U7.27 (A0), U8.12 (A0), U11.9 (A0)
/A1: U2.5 (O1), U4.11 (A1), U8.11 (A1), U11.8 (A1)
/A2: U2.6 (O2), U4.10 (A2), U8.10 (A2)
/A3: U2.9 (O3), U4.9 (A3), U8.9 (A3)
/A4: U2.12 (O4), U4.8 (A4), U8.8 (A4)
/A5: U2.15 (O5), U4.7 (A5), U8.7 (A5), U9.5
/A6: U2.16 (O6), U4.6 (A6), U8.6 (A6)
/A8: U1.8 (A8), U4.27 (A8), U8.27 (A8)
/A9: U1.7 (A9), U4.26 (A9), U8.26 (A9)
/A10: U1.6 (A10), U4.23 (A10), U8.23 (A10)
/A11: U1.5 (A11), U4.25 (A11), U8.25 (A11)
/A12: U3.2 (O0), U4.4 (A12), U8.4 (A12)
/A13: U3.5 (O1), U4.28 (A13), U8.28 (A13)
/A14: U3.6 (O2), U4.29 (A14), U8.3 (A14)
/A15: U3.9 (O3), U4.3 (A15), U8.31 (A15)
/A16: U3.12 (O4), U4.2 (A16), U8.2 (A16)
/A17: U3.15 (O5), U4.30 (A17)
/A18: U3.16 (O6)
/ACK_: R2.2, U5.34 (B0), U11.11 (PC6)
/BUS_PA0: U5.1 (B12), U11.4 (PA0)
/BUS_PA1: U5.2 (B13), U11.3 (PA1)
/BUS_PA2: U5.3 (B14), U11.2 (PA2)
/BUS_PA3: U5.4 (B15), U11.1 (PA3)
/BUS_PA4: U5.17 (B9), U11.40 (PA4)
/BUS_PA5: U5.16 (B8), U11.39 (PA5)
/BUS_PA6: U5.15 (B7), U11.38 (PA6)
/BUS_PA7: U5.14 (B6), U11.37 (PA7)
/CANAL0: U5.6 (A9), U11.18 (PB0)
/CANAL1: U5.7 (A10), U11.19 (PB1)
/CLK_EXT: J4.1, JP1.3 (B)
/CS8259_: U7.1 (~CS), U9.6
/D0: U4.13 (D0), U6.18 (B0), U7.11 (D0), U8.13 (DQ0), U11.34 (D0)
/D1: U4.14 (D1), U6.17 (B1), U7.10 (D1), U8.14 (DQ1), U11.33 (D1)
/D2: U4.15 (D2), U6.16 (B2), U7.9 (D2), U8.15 (DQ2), U11.32 (D2)
/D3: U4.17 (D3), U6.15 (B3), U7.8 (D3), U8.17 (DQ3), U11.31 (D3)
/D4: U4.18 (D4), U6.14 (B4), U7.7 (D4), U8.18 (DQ4), U11.30 (D4)
/D5: U4.19 (D5), U6.13 (B5), U7.6 (D5), U8.19 (DQ5), U11.29 (D5)
/D6: U4.20 (D6), U6.12 (B6), U7.5 (D6), U8.20 (DQ6), U11.28 (D6)
/D7: U4.21 (D7), U6.11 (B7), U7.4 (D7), U8.21 (DQ7), U11.27 (D7)
/IBF: U5.10 (A15), U11.12 (PC5)
/INTA_: U1.24 (~INTA), U7.26 (~INTA)
/INTR: U1.18 (INTR), U7.17 (INT)
/IRQ1: U7.19 (IR1), U11.17 (PC3)
/LCD_SCL: J2.4, U5.37 (B10)
/LCD_SDA: J2.3, U5.11 (B3)
/OBF_: U5.5 (A8), U11.10 (PC7)
/PS2_CLK: J1.3 (D+), R5.2, U5.27 (A1)
/PS2_DATA: J1.2 (D-), R6.2, U5.28 (A2)
/RAM/SEL: IC-6.8, U8.22 (CE#)
/RD_: U1.32 (~RD), U4.24 (OE), U7.3 (~RD), U8.24 (OE#), U11.5 (~RD)
/ROM/SEL: IC-6.6, U4.22 (CE)
/STB_: R3.2, U5.35 (B1), U11.13 (PC4)
/TAG: U5.12 (B4), U11.14 (PC0)
/TAG1: R4.1, U5.13 (B5), U11.15 (PC1)
/WR_: U1.29 (~WR), U7.2 (~WR), U8.29 (WE#), U11.36 (~WR)
A7: U2.19 (O7), U4.5 (A7), U8.5 (A7), U9.2
A19: IC-6.4, IC-6.12, IC-6.13, U3.19 (O7)
CLK: JP1.2 (C), U1.19 (CLK)
CLK_STM: JP1.1 (A), U5.29 (A3)
CS8255_: U9.3, U11.6 (~CS)
GND: D1.1 (K), IC-6.7 (GND), J1.4 (GND), J1.SH (Shield), J2.1, J3.2, J4.2, R1.2, R4.2, R7.2, U1.1 (GND), U1.17 (NMI), U1.20 (GND), U1.23 (~TEST), U1.31 (HOLD), U2.1 (OE), U2.10 (GND), U3.1 (OE), U3.10 (GND), U4.16 (GND), U5.19 (G), U5.39 (G), U6.10 (GND), U7.14 (GND), U7.20 (IR2), U7.21 (IR3), U7.22 (IR4), U7.23 (IR5), U7.24 (IR6), U7.25 (IR7), U8.16 (VSS), U9.7 (GND), U11.7 (GND)
IO: IC-6.1, IC-6.2, U1.28 (IO/~M), U9.1, U9.4
unnamed: D1.2 (A), R8.2
unnamed: IC-6.3, IC-6.5, IC-6.10
unnamed: IC-6.9, IC-6.11
unnamed: U1.4 (A12), U3.3 (D0)
unnamed: U1.3 (A13), U3.4 (D1)
unnamed: U1.2 (A14), U3.7 (D2)
unnamed: U1.39 (A15), U3.8 (D3)
unnamed: U1.38 (A16/S3), U3.13 (D4)
unnamed: U1.37 (A17/S4), U3.14 (D5)
unnamed: U1.36 (A18/S5), U3.17 (D6)
unnamed: U1.35 (A19/S6), U3.18 (D7)
unnamed: U1.16 (AD0), U2.3 (D0), U6.2 (A0)
unnamed: U1.15 (AD1), U2.4 (D1), U6.3 (A1)
unnamed: U1.14 (AD2), U2.7 (D2), U6.4 (A2)
unnamed: U1.13 (AD3), U2.8 (D3), U6.5 (A3)
unnamed: U1.12 (AD4), U2.13 (D4), U6.6 (A4)
unnamed: U1.11 (AD5), U2.14 (D5), U6.7 (A5)
unnamed: U1.10 (AD6), U2.17 (D6), U6.8 (A6)
unnamed: U1.9 (AD7), U2.18 (D7), U6.9 (A7)
unnamed: U1.25 (ALE), U2.11 (LE), U3.11 (LE)
unnamed: U1.26 (DEN), U6.19 (CE)
unnamed: U1.27 (DT/~R), U6.1 (A->B)
unnamed: R7.1, SW2.1, U7.18 (IR0)
RESET: R1.1, SW1.2, U1.21 (RESET), U5.36 (B2), U11.35 (RESET)

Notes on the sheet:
IC-07
By VE2CUY - 2026
C0000h-FFFFFh
0000h-1FFFFh
IC-05
AD2
DEN
IC-01
AD5
IC-03
NOTE: On the breadboard, A8 to A11 are also latched via IC-04
AD4
AD0
DT/R_
IC-09
AD3
IC-02
AD6
AD1
Clock from Arduino UNO R4
AD7
8088 on Breadboard - Version 1.0

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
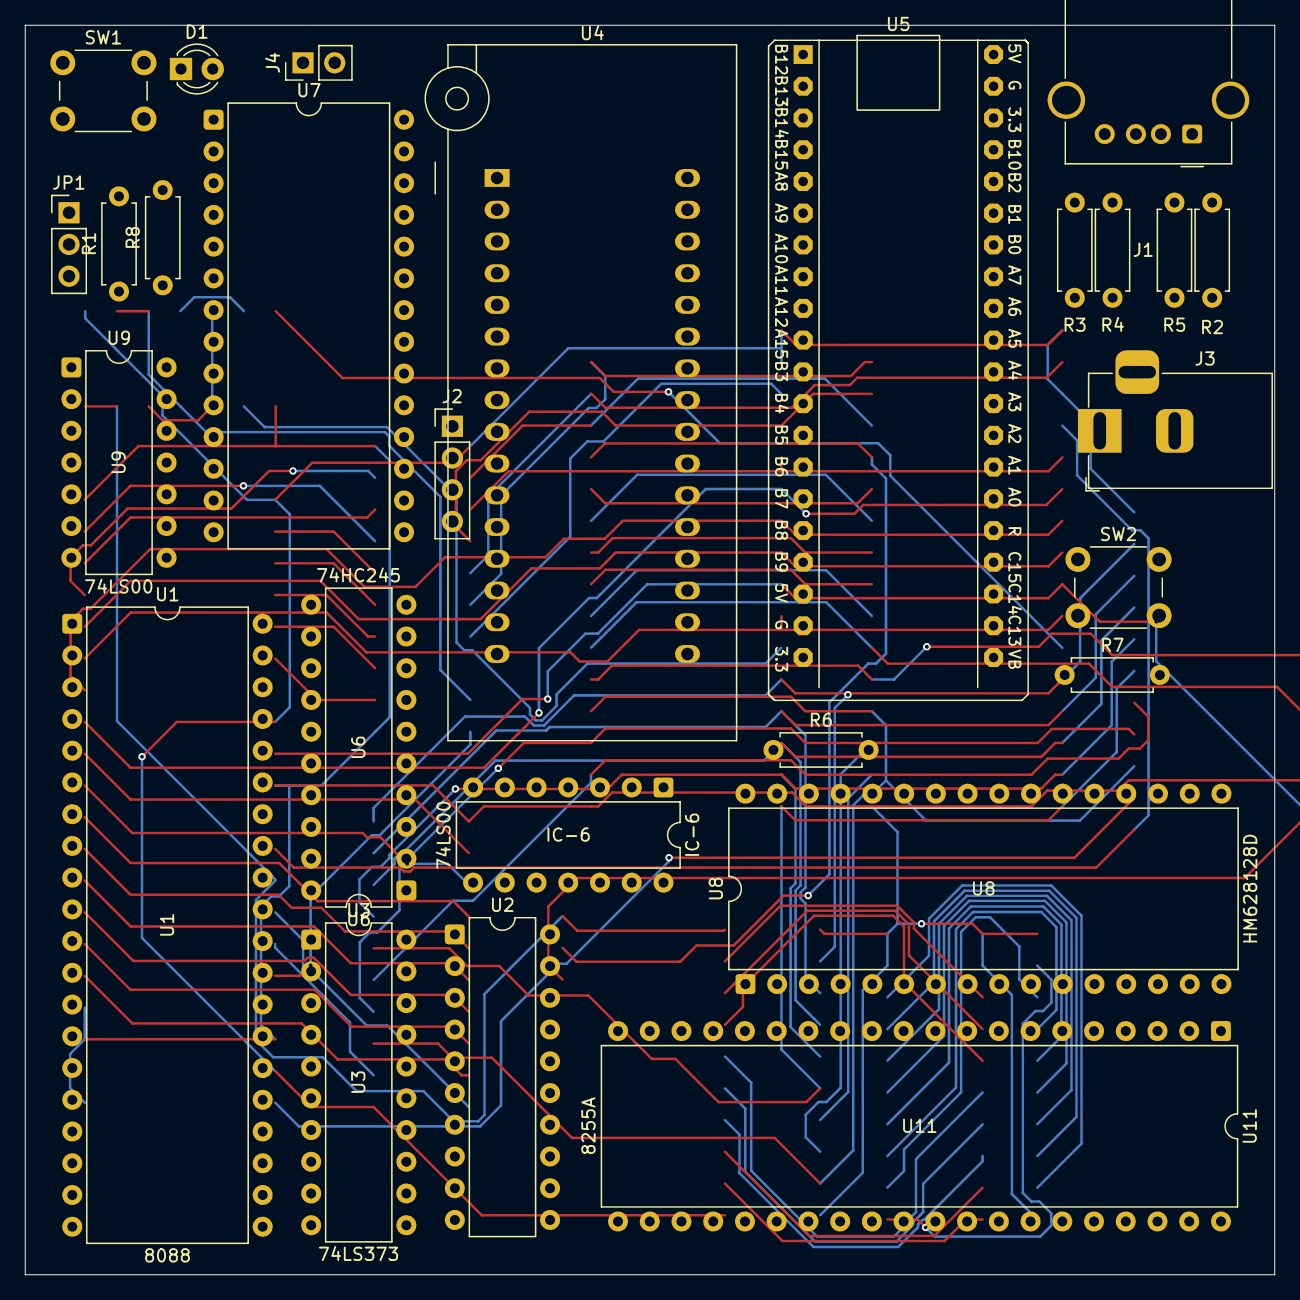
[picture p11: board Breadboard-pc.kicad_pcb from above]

Board: 2 copper layers, 100.0 x 100.0 mm, 27 parts (0 on the bottom side), 86 nets.

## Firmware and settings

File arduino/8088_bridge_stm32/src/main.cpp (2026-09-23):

#include <Arduino.h>
// ============================================================================
// main.cpp (projet PlatformIO 8088_bridge_stm32)  -  Pont WeAct Black Pill V3.1 (STM32F411) <-> 8088
//                              (8255 en MODE 2)
//
// Portage de ve2cuy_bridge.ino (Arduino UNO) - MEME PROTOCOLE cote 8088: le
// firmware du 8088 (Solution-01) n'est pas modifie. Voir README.md (meme
// dossier) pour le cablage, les niveaux 3,3 V / 5 V et la mise en route.
//
// Roles (inchanges):
//   - clavier PS/2  : decode la trame (CLK/DATA), verifie parite/stop, envoie
//                     le scan code brut (Set 2) au 8088;
//   - UART          : port serie virtuel USB (USB natif, "Serial") <-> 8088;
//   - LCD 20x4 I2C  : possede le bus I2C et le protocole PCF8574/HD44780.
//
// 8088 -> pont : le 8088 pose le CANAL sur le Port B (PB0/PB1 du 8255) puis
//     ecrit le Port A; OBF# passe a 0. On lit le canal, on abaisse ACK#, on lit
//     l'octet, on relache ACK#. canal 0 = octet UART, 1 = commande LCD, 2 =
//     donnee LCD.
// pont -> 8088 : on pose l'etiquette TAG (PC0: 0 = scan code, 1 = octet UART
//     recu; PC1 = 1: REPONSE a une commande), l'octet sur le bus, et on pulse
//     STB#; INTR du 8255 (sur IR1 du 8259) interrompt le 8088.
// canal 3 = COMMANDES pour le pont (voir Solution-01/lib/bridge.asm):
//     00h PING (reponse B1h, 3, capacites)   01h LIRE l'heure (reponse: 8 octets)
//     02h + 7 octets REGLER l'heure (annee 2 octets, mois, jour, h, min, s).
//     03h VERSION du firmware (PAS le "3" de PING ci-dessus, qui est le numero
//     de VERSION DU PROTOCOLE - sans rapport) -> 2 octets (majeure, mineure).
//     Necessite TAG1 (PB5) relie a PC1 du 8255 (tire a 0 par 10 kohm).
//     10h-19h = DISQUE: fichiers FAT (racine, noms 8.3) sur la flash SPI (W25Q64, 8 Mo) de la carte
//     (PA4 = CS, SPI1 PA5/PA6/PA7): statut, formater, ouvrir, lire, ecrire, fermer,
//     repertoire (debut / suivant), supprimer, espace libre. Voir lib/bridge.asm.
//     2Ch + 1 octet (action) = HORLOGE du 8088 (PA3, PWM materiel, voir clockExec ci-dessous):
//     0 lire, 1 +0,1 MHz, 2 -0,1 MHz, 3 +1 MHz, 4 -1 MHz, 5 -> 4,77 MHz, 6 -> 8 MHz
//     -> reponse 4 octets = Hz resultant.
//
// CABLAGE (voir le tableau du README.md)
//   D0-D3 <-> PB12-PB15 et D4-D7 <-> PB6-PB9  <->  8255 PA0-PA7 (bus de donnees)
//   PB0 -> ACK# (PC6)   PB1 -> STB# (PC4)   PA8 <- OBF# (PC7)   PB4 -> TAG (PC0)
//   PA9 <- canal bit 0 (8255 PB0)   PA10 <- canal bit 1 (8255 PB1)
//   PA15 <- IBF (PC5, facultatif)   PB5 -> TAG1 (PC1)
//   PA3 -> CLK du 8088 (broche 19, PWM materiel TIM2 CH4 - remplace le fil depuis l'Arduino UNO
//   R4 de projets/Clock-8088/; PA3 servait a TAG2/PC2, jamais cablee sur ce montage - libre)
//   PA1 <- CLK PS/2   PA2 <- DATA PS/2   PB10 = SCL, PB3 = SDA (LCD I2C2)
//   PA11/PA12 = USB, PA13/PA14 = SWD, PC13 = LED, PA4-PA7 = flash SPI (reservees),
//   PB2 -> RESET du 8088 (broche 21, actif HAUT; 10 kohm vers la masse sur le montage, bouton vers +5 V):
//   poussee HAUT pour un reset (demarrage du pont, Ctrl-Alt-Suppr au PS/2, Ctrl-\ au terminal), sinon
//   ENTREE (ne gene pas le bouton, jamais forcee BAS). PB2 = BOOT1: au repos la ligne est BASSE (10 kohm),
//   le mode DFU (BOOT0 = 1, BOOT1 = 0) reste donc utilisable.   PA0 = bouton K1 de la carte
// Selon la fiche technique du STM32F411 (DS10314 Rev 8, tableau 8), TOUTES ces
// broches sont tolerantes 5 V (FT) SAUF PA0 et PB5 (TC, 3,3 V): PB5 n'est donc
// utilisee qu'en SORTIE (TAG1). Ne jamais y relier une sortie 5 V.
// ============================================================================
#include <Wire.h>
#include <HardwareTimer.h>
#include <STM32RTC.h>
#include <SPI.h>
#include <SdFat.h>
#include <Adafruit_SPIFlash.h>
#ifdef USE_TINYUSB
// Environnement PlatformIO blackpill_f411ce_usbdrive: pile USB Adafruit TinyUSB (port serie CDC +
// lecteur de masse). Le nom Serial y est inutilisable (macros croisees de la bibliotheque): on
// passe par UsbSerial. Sans USE_TINYUSB: pile USB du coeur STM32 (CDC seul), UsbSerial = Serial.
#include <Adafruit_TinyUSB.h>
#define UsbSerial SerialTinyUSB
#else
#define UsbSerial Serial
#endif

// ---- reglages -------------------------------------------------------------
#define LCD_ADDR    0x27     // 0x3F pour un PCF8574A
// IBF (PC5 du 8255) cable sur PA15 ? 1 = oui: on n'envoie un octet que si le 8088 a lu le
// precedent (aucun octet ecrase); 0 = non cable. Non cable, PA15 est tiree a 0 (= libre).
#define USE_IBF     1
// Espace MINIMAL entre deux octets pont -> 8088, en plus de IBF. Le 8088 met ~ 0,5 ms
// par caractere saisi (echo compris): a plus de ~ 2000 caracteres/s il ne suit plus et
// son tampon de reception (256 octets) deborde pendant un long collage.
#define GAP_US      1000UL
// Espace minimal entre deux octets de REPONSE (horloge, disque, secteurs, image de disquette): avec IBF
// cable (USE_IBF 1), un octet ne part que quand le 8088 a lu le precedent (IBF = 0): l'espace de 1 ms n'est
// plus necessaire et les blocs de 32 octets des secteurs partent au rythme de l'interruption du 8088
// (~ 150-300 us par octet) au lieu de 1 ms. Sans IBF (USE_IBF 0), les reponses gardent GAP_US.
#define REPLY_GAP_US 20UL
// Pause apres chaque retour chariot (CR) venant du PC: le 8088 traite la ligne saisie
// (tokenisation, insertion dans le programme) avant de recevoir la suivante. 0 = aucune.
#define LINE_DELAY_MS 15UL
// Apres une commande du 8088 au pont (disque, horloge...), le 8088 est occupe: ses instructions
// (OPEN, PRINT#, WRITE#, CLOSE...) durent des dizaines de ms et il ne vide pas son tampon de
// reception (256 octets). On suspend l'envoi des octets UART (collage) jusqu'a ce delai apres la
// derniere commande, sinon un collage de plusieurs lignes deborde ce tampon.
#define CMD_HOLD_MS   250UL
#define TX_STALL_MS 100UL    // port USB sans lecteur: on jette l'octet apres ce delai
#define HEARTBEAT   1        // 1 = LED (PC13, active a l'etat bas) clignote a 1 Hz
// Horloge temps reel: 1 = quartz LSE 32,768 kHz de la carte (precis; la carte V3.1 le
// porte), 0 = oscillateur interne LSI (imprecis). Sans pile sur VBAT l'heure est
// perdue a la mise hors tension.
#define RTC_USE_LSE 1
// Diagnostic disque: 1 = chaque commande disque recue est signalee sur le port serie USB
// ([fs] op=.. flash=.. fs=..), melangee a la sortie du BASIC. A remettre a 0 ensuite.
#define DEBUG_FS 0
#ifdef USE_TINYUSB
#define USB_CAPS 0x1F        // RTC + disque + secteurs + lecteur USB + image de disquette (+ 2Bh somme de controle)
#else
#define USB_CAPS 0x17
#endif
#define CMD_TIMEOUT_MS 100UL // commande a arguments incomplete: abandonnee apres ce delai
// Version du FIRMWARE du pont (PAS le numero de version du protocole - "3" -
// deja renvoye par PING, sans rapport) - interrogee par le 8088 (commande 03h,
// "4) Information" du sous-menu Configuration, Solution-01/solution-01.asm) et
// affichee telle quelle a l'utilisateur. A incrementer manuellement lors de
// changements notables a ce fichier.
#define FW_VERSION_MAJOR 1
#define FW_VERSION_MINOR 2
// Le clavier envoie 0F0h puis le code de la touche COUP SUR COUP. Toute impulsion
// sur STB#/ACK#/bus pendant qu'une trame PS/2 arrive risque de la perturber: on
// n'agit donc sur le bus 8255 que si CLK est silencieux depuis:
#define KBD_QUIET_US 3000UL  // avant d'ENVOYER un octet clavier (fin de la rafale)
#define BUS_QUIET_US 400UL   // avant tout autre acces au bus (trame en cours)
// Filtrage du bruit sur CLK/DATA: un vrai front descendant de CLK reste bas >=
// 30 us, un parasite de diaphonie quelques us seulement.
#define PS2_GLITCH_US    10UL  // CLK doit etre encore basse apres ce delai
#define PS2_FRAME_GAP_US 250UL // sans front valide depuis: nouvelle trame
#define DEBUG_PS2   0        // 1 = trace PS/2 sur le terminal (Serial), voir dbg*()

// ---- broches --------------------------------------------------------------
// Les signaux sont lus et ecrits par registres (BSRR/IDR) pour garder les temps
// de l'instantane (voir takeFrom8088).
#define ACK_BIT   0                  // GPIOB, sortie drain ouvert (10 kohm vers +5 V)
#define STB_BIT   1                  // GPIOB, sortie drain ouvert (10 kohm vers +5 V)
#define TAG_BIT   4                  // GPIOB, sortie
#define TAG1_BIT  5                  // GPIOB, sortie SEULEMENT (PB5 n'est pas tolerante 5 V)
#define OBF_BIT   8                  // GPIOA, entree
#define CH0_BIT   9                  // GPIOA, entrees (canal = Port B du 8255)
#define CH1_BIT   10
#define IBF_BIT   15                 // GPIOA, entree (facultatif)
#define PS2_CLK_BIT  1               // GPIOA, interruption EXTI1
#define PS2_DATA_BIT 2               // GPIOA
const uint32_t PIN_ACK = PB0, PIN_STB = PB1, PIN_TAG = PB4;
const uint32_t PIN_OBF = PA8, PIN_CH0 = PA9, PIN_CH1 = PA10, PIN_IBF = PA15;
const uint32_t PIN_TAG1 = PB5;                         // PC1 (etiquette etendue, futur)
const uint32_t PIN_PS2_CLK = PA1, PIN_PS2_DATA = PA2;
const uint32_t PIN_SCL = PB10, PIN_SDA = PB3;          // I2C2 (AF4 / AF9)
const uint32_t PIN_CLK8088 = PA3;                      // TIM2 CH4: horloge du 8088 (broche CLK, 19) -
                                                         // remplace le fil depuis l'Arduino UNO R4 (projets/Clock-8088)
                                                         // - PA3 servait a TAG2/PC2, jamais cablee sur ce montage

// Bus de donnees sur GPIOB, en deux quartets: D0-D3 = PB12-PB15, D4-D7 = PB6-PB9
#define BUS_ODR_MASK   ((0xFUL << 12) | (0xFUL << 6))
#define BUS_MODER_MASK 0xFF0FF000UL  // 2 bits par broche: PB12-15 (bits 24-31) et PB6-9 (bits 12-19)
#define BUS_MODER_OUT  0x55055000UL  // 01 = sortie
// Sur le montage, les broches PA4-PA7 du 8255 arrivent dans l'ORDRE INVERSE
// (constate: espace 0x20 recu 0x40, 'p' 0x70 recu 0xE0): le quartet haut est
// inverse (D4<->D7, D5<->D6), comme sur l'UNO. 1 = corrige en logiciel, 0 = bus
// cable dans l'ordre (D0-D7 <-> PA0-PA7).
#define BUS_HIGH_NIBBLE_REVERSED 1

// ---- canaux 8088 -> pont (Port B du 8255) ---------------------------------
const uint8_t CH_UART     = 0;
const uint8_t CH_LCD_CMD  = 1;
const uint8_t CH_LCD_DATA = 2;
const uint8_t CH_CMD      = 3;         // commandes pour le pont (horloge...)

// ============================================================================
// Acces rapide aux broches (registres GPIO)
// ============================================================================
static inline void ackLow()  { GPIOB->BSRR = (1UL << (ACK_BIT + 16)); }
static inline void ackHigh() { GPIOB->BSRR = (1UL << ACK_BIT); }
static inline void stbLow()  { GPIOB->BSRR = (1UL << (STB_BIT + 16)); }
static inline void stbHigh() { GPIOB->BSRR = (1UL << STB_BIT); }
static inline bool obfHigh() { return (GPIOA->IDR >> OBF_BIT) & 1; }   // 1 = rien en attente
static inline void tagWrite(uint8_t t) {   // t = 0: scan code, 1: octet UART, 2: reponse
  GPIOB->BSRR = (t & 1) ? (1UL << TAG_BIT) : (1UL << (TAG_BIT + 16));
  GPIOB->BSRR = (t & 2) ? (1UL << TAG1_BIT) : (1UL << (TAG1_BIT + 16));
}

// ============================================================================
// Bus Port A du 8255 = PB12-PB15 (D0-D3) + PB6-PB9 (D4-D7) (MODER/BSRR/IDR)
// ============================================================================
static inline void busRelease() {          // haute impedance, sans pull
  GPIOB->MODER &= ~BUS_MODER_MASK;         // 00 = entree
}

// Inverse l'ordre des 4 bits du quartet haut (involution: sert a la lecture et a l'ecriture)
static inline uint8_t fixHighNibble(uint8_t v) {
#if BUS_HIGH_NIBBLE_REVERSED
  uint8_t h = (uint8_t)(v >> 4);
  h = (uint8_t)(((h & 1) << 3) | ((h & 2) << 1) | ((h & 4) >> 1) | ((h & 8) >> 3));
  return (uint8_t)((v & 0x0F) | (h << 4));
#else
  return v;
#endif
}

static inline uint8_t busFromIdr(uint32_t idr) {
  return fixHighNibble((uint8_t)(((idr >> 12) & 0x0F) | ((idr >> 2) & 0xF0)));
}

static inline void busDrive(uint8_t v) {   // niveau AVANT de passer en sortie
  v = fixHighNibble(v);
  uint32_t set = ((uint32_t)(v & 0x0F) << 12) | ((uint32_t)(v & 0xF0) << 2);
  GPIOB->BSRR = ((BUS_ODR_MASK & ~set) << 16) | set;
  GPIOB->MODER = (GPIOB->MODER & ~BUS_MODER_MASK) | BUS_MODER_OUT;
}

// pont -> 8088: octet + etiquette, puis impulsion STB#.
#if DEBUG_FS
static uint8_t dbgIbfAfter = 0;
#endif
static void sendTo8088(uint8_t tag, uint8_t v) {
  tagWrite(tag);
  busDrive(v);
  delayMicroseconds(2);
  stbLow();
  delayMicroseconds(2);
  stbHigh();                               // front montant: le 8255 verrouille
  delayMicroseconds(2);
#if DEBUG_FS
  dbgIbfAfter = (uint8_t)((GPIOA->IDR >> IBF_BIT) & 1);   // IBF doit valoir 1 (octet non lu)
#endif
  busRelease();
}

// 8088 -> pont: si OBF# est bas, lit canal + octet. ACK# bas = le 8255 pilote
// le bus (les broches sont des entrees a ce moment-la). INSTANTANE indispensable:
// le 8255 remet OBF# a 1 des que ACK# DESCEND, donc le 8088 peut ecrire l'octet
// suivant ~15 us plus tard, pendant qu'on lit encore le bus. Ici les deux ports
// sont lus en quelques cycles (< 100 ns).
static bool takeFrom8088(uint8_t &chan, uint8_t &val) {
  if (obfHigh()) return false;             // rien en attente
  ackLow();
  delayMicroseconds(2);                    // tAOD du 8255 < 200 ns
  uint32_t b = GPIOB->IDR;
  uint32_t a = GPIOA->IDR;
  ackHigh();
  val  = busFromIdr(b);
  chan = (uint8_t)(((a >> CH0_BIT) & 1) | (((a >> CH1_BIT) & 1) << 1));
  return true;
}

// ============================================================================
// File 8088 -> peripheriques (256 entrees, 255 utiles)
// ============================================================================
struct Item { uint8_t chan; uint8_t val; };
static Item   q[256];
static uint8_t qHead = 0, qTail = 0;
static inline bool qEmpty() { return qHead == qTail; }
static inline bool qFull()  { return (uint8_t)(qHead + 1) == qTail; }

// ============================================================================
// Horloge temps reel et commandes du canal 3
// ============================================================================
static STM32RTC &rtc = STM32RTC::getInstance();

static uint8_t rq[64];                     // reponses en attente d'envoi au 8088
static uint8_t rqHead = 0, rqTail = 0;
static void replyByte(uint8_t v) {
  uint8_t nh = (uint8_t)((rqHead + 1) & 63);
  if (nh != rqTail) { rq[rqHead] = v; rqHead = nh; }
}

// Lecture COHERENTE par registres: SSR d'abord (verrouille les registres image), puis
// TR et DR (deverrouille). Centiemes = (PREDIV_S - SSR) / (PREDIV_S + 1) * 100.
static void replyTime() {
  uint32_t ss = RTC->SSR;
  uint32_t tr = RTC->TR;
  uint32_t dr = RTC->DR;
  uint32_t prediv = RTC->PRER & 0x7FFFUL;
  uint8_t hh = (uint8_t)(((tr >> 20) & 3) * 10 + ((tr >> 16) & 15));
  uint8_t mm = (uint8_t)(((tr >> 12) & 7) * 10 + ((tr >> 8) & 15));
  uint8_t sc = (uint8_t)(((tr >> 4) & 7) * 10 + (tr & 15));
  uint16_t year = (uint16_t)(2000 + ((dr >> 20) & 15) * 10 + ((dr >> 16) & 15));
  uint8_t mo = (uint8_t)(((dr >> 12) & 1) * 10 + ((dr >> 8) & 15));
  uint8_t dd = (uint8_t)(((dr >> 4) & 3) * 10 + (dr & 15));
  uint32_t cs = (ss <= prediv) ? ((prediv - ss) * 100UL) / (prediv + 1UL) : 0;
  if (cs > 99) cs = 99;
  replyByte((uint8_t)year); replyByte((uint8_t)(year >> 8));
  replyByte(mo); replyByte(dd); replyByte(hh); replyByte(mm); replyByte(sc);
  replyByte((uint8_t)cs);
}

static void applyTime(const uint8_t *a) {  // annee (2 octets), mois, jour, h, min, s
  uint16_t year = (uint16_t)(a[0] | (a[1] << 8));
  if (year < 2000 || year > 2099 || a[2] < 1 || a[2] > 12 || a[3] < 1 || a[3] > 31 ||
      a[4] > 23 || a[5] > 59 || a[6] > 59) return;               // valeurs invalides: ignore
  rtc.setDate(a[3], a[2], (uint8_t)(year - 2000));
  rtc.setTime(a[4], a[5], a[6]);
}
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
void loop() {
#ifdef USE_TINYUSB
  yield();                                 // tud_task(): traite les evenements USB (CDC, lecteur de masse)
#endif
  dbgFlush();

  // Reset du 8088 demande (Ctrl-Alt-Suppr, Ctrl-\). Si le 8088 ne lit plus rien, le terminal n'est plus
  // lu plus bas - on y cherche Ctrl-\ ici (les autres octets sont perdus: le 8088 ne les aurait jamais lus).
  // "Fige" = IBF = 1 (dernier octet envoye non lu) ET plus rien envoye depuis STUCK_MS. Premiere version
  // (1.2 initiale): IBF = 1 observe a CHAQUE debut de boucle pendant STUCK_MS - FAUX pendant un collage:
  // un tour de boucle (echo vers l'USB et le LCD I2C) peut durer plus que GAP_US, l'octet suivant partait
  // alors en fin de tour et le debut du tour suivant revoyait IBF = 1 - le 8088 semblait fige et le reste
  // du collage etait jete ("60 PI = 3.14159265" -> "60").
#if USE_IBF
  if (((GPIOA->IDR >> IBF_BIT) & 1) && (uint32_t)(micros() - lastTx) > STUCK_MS * 1000UL) {
    while (UsbSerial.available() > 0)
      if ((uint8_t)UsbSerial.read() == RESET_UART_KEY) { resetRequest = true; break; }
  }
#endif
  if (resetRequest) reset8088Pulse();

#if HEARTBEAT
  { static uint32_t t = 0;
    if (millis() - t >= 500) { t = millis(); digitalToggle(PC13); } }
#endif

  // 1. 8088 -> file
  if (!qFull() && ps2Quiet(BUS_QUIET_US)) {
    uint8_t chan, val;
    if (takeFrom8088(chan, val)) {
      q[qHead].chan = chan; q[qHead].val = val;
      qHead++;
    }
  }

  // 2. file -> UART (USB) ou LCD (un element par tour)
  if (!qEmpty()) {
    Item &it = q[qTail];
    if (it.chan == CH_UART) {
      static uint32_t stallSince = 0;
      if (UsbSerial.availableForWrite() > 0) {
        UsbSerial.write(it.val); qTail++; stallSince = 0;
      } else if (stallSince == 0) {
        stallSince = millis() | 1;
      } else if (millis() - stallSince > TX_STALL_MS) {
        qTail++; stallSince = 0;           // personne ne lit le port USB: octet jete
      }
    } else {
      if (it.chan == CH_LCD_CMD) {
        if (it.val == 0x28) lcdResync();   // Function Set = debut de i2c_lcd_init
                                           // (8088): resynchronise un LCD deregle
        lcdSend(it.val, 0);
      }
      else if (it.chan == CH_LCD_DATA) lcdSend(it.val, LCD_RS);
      else if (it.chan == CH_CMD) cmdByte(it.val);
      qTail++;                             // canal inconnu: octet jete
    }
  }

  // 3. reponses / clavier / UART recu -> 8088
  uint8_t v;
#if DEBUG_FS
  { // diagnostic: une reponse en attente depuis plus de 100 ms = bloquee (IBF? PS/2?)
    static uint32_t since = 0; static bool said = false;
    if (rqHead == rqTail) { since = 0; said = false; }
    else if (since == 0) since = millis() | 1;
    else if (!said && millis() - since > 100) {
      said = true;
      UsbSerial.print("[rq] bloquee: IBF="); UsbSerial.print((GPIOA->IDR >> IBF_BIT) & 1);
      UsbSerial.print(" ps2Quiet="); UsbSerial.print(ps2Quiet(BUS_QUIET_US));
      UsbSerial.print(" n="); UsbSerial.print((uint8_t)((rqHead - rqTail) & 63)); UsbSerial.print("\r\n");
    }
  }
#endif
#if USE_IBF
  // Reponse a une commande: IBF seul suffit (voir REPLY_GAP_US)
  if (rqHead != rqTail && !((GPIOA->IDR >> IBF_BIT) & 1) && (uint32_t)(micros() - lastTx) >= REPLY_GAP_US &&
      ps2Quiet(BUS_QUIET_US)) {
    v = rq[rqTail];
    rqTail = (uint8_t)((rqTail + 1) & 63);
    sendTo8088(2, v);
    markSent();
  } else
#endif
  if (canSend()) {                         // IBF libre (si cable) et GAP_US ecoule
    if (rqHead != rqTail && ps2Quiet(BUS_QUIET_US)) {           // reponse a une commande (sans IBF)
      v = rq[rqTail];
      rqTail = (uint8_t)((rqTail + 1) & 63);
      sendTo8088(2, v);
#if DEBUG_FS
      UsbSerial.print("[tx] "); UsbSerial.print(v, HEX); UsbSerial.print(" ibf="); UsbSerial.print(dbgIbfAfter); UsbSerial.print("\r\n");
#endif
      markSent();
    } else if (ps2Head != ps2Tail && ps2Quiet(KBD_QUIET_US)) {
      ps2Pop(v);
      sendTo8088(0, v);
      dbgSent(v);
      markSent();
    } else if (UsbSerial.available() > 0 && ps2Quiet(BUS_QUIET_US) &&
               (int32_t)(millis() - uartHoldUntil) >= 0) {
      uint8_t c = (uint8_t)UsbSerial.read();
      if (c == RESET_UART_KEY) {
        resetRequest = true;               // Ctrl-\: reset MATERIEL au prochain tour (non transmis)
      } else {
        sendTo8088(1, c);
        markSent();
        if (c == 13) uartHoldUntil = millis() + LINE_DELAY_MS;   // le 8088 traite la ligne
      }
    }
  }
}

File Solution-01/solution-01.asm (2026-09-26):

BITS    16
CPU     8086                    ; refuse tout opcode qui n'existe pas sur un vrai 8088
ORG     0000h                   ; = physique C0000h (debut de la ROM)

; ------------------------------------------------------------
; solution-01.asm
; nasm -f bin solution-01.asm -o Z:\Partage\Alain\solution-01.bin
; (voir aussi le Makefile: "make rom" fait la meme chose et copie
; le resultat vers Z:\Partage\Alain\rom.bin)
; ------------------------------------------------------------
; VARIANTE DE ram_test_uart_7.asm: elimine completement le latch
; externe (et son decodage d'adresse) en deplacant le signal UART
; sur PA7 - le meme port que le LCD (Port A du 8255).
;
; PROBLEME: en mode 0, le 8255 n'adresse PAS les bits du port A
; individuellement - un OUT ecrit les 8 bits en meme temps. Le LCD
; (D4-D7, RS, E sur PA0-PA4/PA6) et l'UART (PA7) doivent donc
; cohabiter sur le MEME octet. Solution: une copie "fantome" de
; l'etat du port A est gardee en RAM (PORTA_SHADOW - impossible en
; ROM, qui est en lecture seule), et CHAQUE ecriture - LCD ou UART -
; passe par porta_write, qui ne modifie QUE les bits qui la
; concernent et preserve les autres via un lecture-modification-
; ecriture (voir lib/common.asm). La ligne UART reste donc a son
; dernier etat (idle ou en cours de bit) meme quand le LCD ecrit, et
; vice-versa.
;
; La copie fantome vit dans la zone deja reservee a la pile (voir
; test_ram plus bas) - donc AUCUN octet en plus n'est retire du
; test RAM.
;
; IMPORTANT - init_8255 sorti de la boucle principale: un mot de
; mode du 8255 (comme celui envoye par init_8255) remet TOUS les
; verrous de sortie a 0, y compris le port A au complet (LCD ET
; UART). Comme ce mot n'a besoin d'etre envoye qu'une seule fois
; (le mode ne change jamais ensuite), init_8255 est maintenant
; appele UNE SEULE FOIS avant la boucle .ici, pas a chaque cycle -
; sinon la ligne UART retomberait a 0 (condition de break) a
; chaque nouveau cycle, le temps que le LCD la remette par hasard
; au bon etat via un premier appel a lcd_strobe.
;
; Cablage LCD (Port A du 8255, PA0-PA7): identique a lcd_hello_6.asm
;   PA0-PA3 -> D4-D7, PA4 -> RS, PA6 -> E, R/W du LCD a la masse.
;   PA7 -> UART (remplace le latch/74LS373 externe).
;
; LCD 4x20 (remplace le 2x16 d'origine). Adressage DDRAM utilise
; pour les lignes 3/4 (convention standard des afficheurs 20x4 base
; sur le HD44780: la ligne 3 est en fait la suite de la ligne 1 en
; memoire interne, et la ligne 4 la suite de la ligne 2):
; ligne1=00h, ligne2=40h, ligne3=14h, ligne4=54h ("type A" - si le
; texte des lignes 3/4 apparait au mauvais endroit sur ton module,
; il existe une variante moins courante 00h/20h/40h/60h a essayer).
; Le Function Set (00101000b: 4 bits, N=1) ne change PAS: le HD44780
; ne connait que le mode "1 ligne" ou "2 lignes" en interne.
;
; ------------------------------------------------------------
; STRUCTURE DU PROJET (voir Directives.md):
;   solution-01.asm       - ce fichier: flux principal (start, test
;                            RAM, dump ROM, animation 8255) + toutes
;                            les donnees/textes.
;   include/hardware.inc  - constantes materielles partagees (8255,
;                            adresses RAM des variables partagees).
;   include/delay.inc     - macro delay_ms.
;   lib/common.asm        - porta_write + hex_table (partages LCD/UART).
;   lib/lcd.asm           - toutes les procedures d'affichage LCD.
;   lib/uart.asm          - toutes les procedures de transmission UART.
;   lib/utils.asm         - delay_ms_proc (routine derriere la macro).
;
; Tous les %include de ce fichier (et de ceux de ./lib) sont ecrits
; comme des chemins relatifs a CETTE racine (Solution-01/) - voir
; la note dans include/hardware.inc. Le Makefile lance toujours nasm
; depuis cette racine, meme pour assembler un module seul.
; ------------------------------------------------------------
STACK_SEG       equ     1000h

SECONDE         equ     1000            ; 1 seconde = 1000 ms

; ------------------------------------------------------------
; TEST_PS2 (decommenter la ligne %define ci-dessous pour activer):
; diagnostic du clavier PS/2 decode par le pont (voir lib/ps2.asm,
; PS2_RX_BUF_OFF/irq1_arduino_handler - depuis la version a pont, le
; 8088 ne decode plus le protocole CLOCK/DATA lui-meme) - REMPLACE le
; menu interactif par une boucle infinie qui affiche sur l'UART le
; scan code BRUT (Set 2, sans traduction) de chaque octet recu. Utile
; pour verifier la chaine pont->IRQ1->tampon independamment de la
; couche de traduction clavier->ASCII (ps2_get_char) utilisee par le
; menu. Desactive par defaut (le menu, qui utilise deja le clavier via
; ps2_get_char, est le comportement normal - voir Directives.md).
; %define TEST_PS2
; ------------------------------------------------------------

%macro cls 0
        print   CLS, UART       ; efface l'ecran du terminal (ANSI)
%endmacro

; --- ascii_or_dot: remplace AL par '.' s'il n'est pas imprimable
; --- (< 20h ou > 7Eh) - motif utilise par le dump ASCII UART
; --- (dump_line) ET le dump ASCII du LCD I2C (i2c_dump_hex_ascii8_line),
; --- auparavant duplique dans les 2 routines. ---
%macro ascii_or_dot 0
        cmp     al, 20h
        jb      %%not_printable
        cmp     al, 7Eh
        ja      %%not_printable
        jmp     %%print_char
%%not_printable:
        mov     al, '.'
%%print_char:
%endmacro

; --- lcd_text: definit un texte LCD complete a une largeur fixe par
; --- des espaces, puis termine par 0 - motif utilise ~15 fois dans
; --- la section donnees ci-dessous (textes des 4 lignes du LCD 4x20).
; --- %1=etiquette, %2='texte' (chaine, eventuellement vide ''),
; --- %3=largeur visible (SANS compter le terminateur 0 ajoute apres). ---
%macro lcd_text 3
%1:             db      %2
                times   %3-($-%1) db ' '
                db      0
%endmacro

; --- uart_flag_bit: affiche via l'UART le mnemonique DEBUG.COM (2
; --- lettres) correspondant a UN bit du registre FLAGS - utilise 8
; --- fois par registers_dump_action pour le decodage "ergonomique"
; --- des FLAGS (ordre classique OF DF IF SF ZF AF PF CF). Le
; --- mnemonique "actif" (bit=1) est colore en jaune pour ressortir a
; --- l'oeil; le mnemonique "inactif" (bit=0) reste en couleur par
; --- defaut du terminal - voir les paires txt_flag_*_set/clear plus
; --- bas dans la section donnees. Chaque etiquette inclut deja un
; --- espace de separation final (voir leur definition).
; --- %1=masque (mot), %2=etiquette si le bit est a 1, %3=etiquette
; --- si le bit est a 0. DX DOIT deja contenir le mot FLAGS a decoder
; --- (charge une seule fois par l'appelant, avant la 1ere invocation). ---
%macro uart_flag_bit 3
        test    dx, %1
        jz      %%is_clear
        print   %2, UART
        jmp     %%done
%%is_clear:
        print   %3, UART
%%done:
%endmacro

%include "include/hardware.inc"
%include "include/delay.inc"
%include "include/lcd_macros.inc"
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

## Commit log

2026-09-22 Depot initial: firmware/BIOS du 8088 sur breadboard (VE2CUY), Solution-01, pont Arduino/STM32, schemas KiCad, images PC-DOS, documentation et medias.
    [.kicad_sch, .kicad_sch.kicad_sch, Partie01.kicad_sch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]
2026-09-22 Genere l'horloge du 8088 depuis le pont STM32 (PA3, TIM2 CH4)
    Remplace la dependance a un Arduino UNO R4 separe (projets/Clock-8088,
    i86) par une generation PWM materielle directement sur le pont STM32
    Black Pill, sur une broche libre (PA3 - PB11 initialement propose s'est
    revele absent de cette variante de carte).
    - arduino/8088_bridge_stm32/src/main.cpp: HardwareTimer sur TIM2 CH4,
    PIN_CLK8088=PA3 (remplace l'ancienne PIN_TAG2, jamais cablee),
    clockSetup()/clockApply()/clockExec() - table de 11 frequences
    (1-10 MHz + 4,77 MHz), duty cycle 33% (1/3, comme l'original).
    clockSetup() appelee en tout premier dans setup(), avant SPI/USB/RTC.
    Nouvelle commande de protocole canal 3: 2Ch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
    [main.cpp, solution-01.asm]
2026-09-22 Confirme sur le materiel reel: l'horloge du 8088 (PA3) fonctionne
    Suite au commit 96126e7 - le PA3/TIM2 CH4 du pont STM32 genere
    correctement le signal CLK du 8088, remplace avec succes l'Arduino
    UNO R4 separe.
2026-09-22 Clock speed: corrige le bug UART, refond le sous-menu, affiche au menu principal
    Bug corrige: les instructions du sous-menu Clock speed n'etaient
    envoyees qu'au LCD, jamais a l'UART (seule la ligne "Frequence: ..."
    y apparaissait) - un utilisateur au clavier via un terminal serie ne
    voyait donc aucune des touches disponibles.
    En meme temps, refonte du sous-menu selon la maquette demandee:
    options numerotees 1-6 (au lieu des fleches Haut/Bas + D/8), avec un
    pas fin de 0,1 MHz en plus du pas de 1 MHz:
    1) Up : 0.1 MHz 2) Down : 0.1 MHz
    3) Up : 1 MHz 4) Down : 1 MHz
    5) 4.77 MHz 6) 8.0 MHz
    Echap - retour
    La frequence courante est aussi affichee a droite de la 1re lign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
    [main.cpp, solution-01.asm]
2026-09-22 Ajoute "2) Test CPU speed" et corrige 2 bugs LCD (SI ecrase, curseur TTY)
    Nouvelle option du sous-menu Configuration: banc d'essai a charge fixe
    (15,7M iterations), duree mesuree via la RTC du pont (independante de
    l'horloge du 8088 - condition necessaire, puisque c'est justement la
    vitesse du CPU qu'on cherche a mesurer). Affiche le temps ecoule (mis a
    jour a intervalles reguliers pendant le test, Echap pour annuler), le
    pourcentage par rapport a une execution a 4,77 MHz, et la vitesse
    estimee en MHz.
    Deux bugs trouves et corriges pendant le developpement (voir
    Directives.md pour le detail):
    1. cpu_test_show_progress ecrasait SI (pointeurs de texte internes)
    sans le preserver, alors qu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
    [solution-01.asm]
2026-09-22 Test CPU speed: calibration finale mesuree sur le materiel reel (34s)
    Corrige la calibration de CPU_TEST_REF_SECONDS a partir de resultats
    reels obtenus sur le materiel (calcul inverse exact a chaque etape a
    partir du pourcentage/de la vitesse estimee affiches):
    1. Ancienne constante (60, jamais mesuree) -> 69, mesuree a
    CPU_TEST_INNER_REPS=8 (resultat "13% plus lent"/"4.14 MHz" a 4,77 MHz
    reel -> T=69 est l'unique solution entiere).
    2. Duree jugee trop longue (69s pour un minimum demande de 30s) ->
    CPU_TEST_INNER_REPS reduit de 8 a 4 (projection lineaire: 69*4/8 =
    34,5s), CPU_TEST_REF_SECONDS ajuste a 35 en consequence.
    3. Reconfirme sur le materiel: resultat "2% plus vite"/"4.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
    [solution-01.asm]
2026-09-22 Test CPU speed: points de progression UART au lieu des secondes
    Chantier 1/3 du nouveau Manifest.md (ajoute au depot - suivi des
    demandes en attente, dans le meme esprit que Directives.md):
    - L'UART affiche desormais un "." par checkpoint (~30 au total, tous
    sur la meme ligne) pendant le test, au lieu de repeter "Ecoule: NN s"
    a chaque fois - indicateur de progression plus compact. Le LCD est
    inchange (toujours l'affichage numerique en direct).
    - L'intro annonce la duree approximative ("environ 30 secondes").
    - Le resultat final et les messages de timeout terminent proprement la
    ligne de points (CRLF explicite) avant de s'afficher.
    Bug trouve et corrige avant tout test: le nouveau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
    [solution-01.asm]
2026-09-22 Bilinguisme FR/EN pour le moniteur et le BIOS partage (Manifest.md 2/3)
    Tous les textes UART/LCD du moniteur interactif (solution-01.asm) et
    les messages partages du BIOS (lib/bios.asm: amorcage DOS, interruption
    non implementee) sont desormais disponibles en francais ET en anglais,
    selectionnes a la compilation:
    make rom-fr # solution-01-fr.bin - francais (= comportement de
    # "rom"/"make" actuel, aucun changement par defaut)
    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
2026-09-23 Sous-menu Configuration: Heure et date + Information (Manifest.md 3/3)
    Deux nouvelles options du sous-menu Configuration:
    3) Heure et date - regle la date/l'heure de la RTC du pont, en 2
    invites chainees ("Date: JJ-MM-AAAA" / "Heure: HH:MM:SS"), saisie
    DECIMALE (nouvelle ps2_read_dec_editable, lib/ps2.asm - pas
    hexadecimale comme Edit RAM/Dump memory). Envoyee telle quelle a
    rtc_set; le pont valide lui-meme les bornes.
    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
2026-09-23 Corrige la precision de "Current speed" affichee (frequence reellement generee, pas seulement demandee)
    Suite a la note ajoutee par l'utilisateur dans Manifest.md: le sous-menu
    Clock speed affichait "Current speed: 7.07 MHz", mais le test CPU (2) sur ce
    meme reglage estimait 7.37 MHz, et une mesure a l'oscilloscope confirmait
    7.3-7.4 MHz reels - un ecart de plus de 4%.
    Diagnostic (lecture du code source HardwareTimer.cpp de STM32duino):
    clockApply() configurait le PWM via clockTimer.setPWM(...), qui appelle en
    interne setOverflow(freq, HERTZ_FORMAT). Cette fonction calcule ARR/prescaler
    par DEUX divisions entieres successives et TRONQUANTES:
    period_cyc = getTimerClkFreq() / overflow;
    Pe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
    [main.cpp]
2026-09-23 Corrige "4) Information": Echap ignore, heure LCD figee, ligne UART qui defilait
    Suite a une nouvelle note ajoutee par l'utilisateur dans Manifest.md, 3
    symptomes rapportes sur le materiel reel pour l'ecran "4) Information"
    (sous-menu Configuration):
    1) Echap n'a aucun effet sur cet ecran (la date/heure UART defile sans fin).
    2) L'heure du LCD reste figee, elle ne s'actualise qu'a la frappe d'une touche.
    3) Sur l'UART, chaque seconde imprime une NOUVELLE ligne au lieu de redessiner
    la meme ("repositionner le curseur sur la ligne de l'heure").
    Diagnostic: la .loop d'information_action rappelait rtc_get EN CONTINU, sans
    le moindre repit. BRIDGE_EXPECT_OFF (mis a 1 par rtc_get pendant tout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
    [solution-01.asm]
2026-09-23 Gel du 8088 sous DOS pendant les lectures de secteur: reponses du pont par scrutation
    Pendant chaque commande au pont, IR1 est masquee au 8259 et bridge_rx_get_t
    lit le 8255 elle-meme (irq1_dispatch, classement partage avec l'ISR): plus
    de ~530 IRQ1/cycles INTA par secteur lu. Les traces BIOS_TRACE montraient le
    gel au milieu d'un INT 13h de lecture, horloge et pont vivants.
    Retire aussi le STI premature de start: (IVT effacee apres Ctrl-\).
2026-09-23 Directives: scrutation des reponses du pont confirmee stable sous DOS 3.30 (materiel reel)
2026-09-23 Pont: la liste des fichiers s'arretait sur un nom long (16+ caracteres)
    getName() dans un tampon de 16 octets echouait -> longueur 0 = fin de liste pour le 8088: les fichiers suivants disparaissaient. Nom long s'il tient en 8.3, sinon nom court (getSFN); entree illisible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
2026-09-23 Makefile: ROM de trace nommees solution-01-trace*.bin; rom-fr/rom-en copiees dans le dossier partage
2026-09-23 Points de progression a l'amorcage; trace du BIOS dans la ROM officielle (Ctrl-] / Ctrl-Echap)
2026-09-23 Trace du BIOS: Ctrl-T au lieu de Ctrl-] (intapable dans PuTTY sur clavier francais)
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2026-09-23 Pont 1.2: reset materiel du 8088 par PB2 (demarrage du pont, Ctrl-Alt-Suppr, Ctrl-\)
    [main.cpp]
2026-09-23 Pont 1.2: la detection du 8088 fige jetait les collages du terminal
2026-09-23 Bancs d'essai: simulateur de la ROM complete avec IRQ1 asynchrones (make test-rom)
    tests/rom_sim.py (8255/8259/ISR modelises, scenarios pilotes par l'UART, ligne de commande) et tests/rom_test.py: DOS 2.1/3.30 reels, trace Ctrl-T, scrutation du pont, Ctrl-\ puis reamorcage, collage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
2026-09-24 Clavier PS/2: un relachement ne bloque plus le test de vitesse ni l'ecran Information
    La verification d'Echap (ps2_key_available puis ps2_get_char) avalait le
    relachement F0 xx de la touche de lancement puis attendait une vraie touche.
    Nouvelle routine non bloquante ps2_poll_char; simulateur: frappes PS/2 (ps2()),
    2 verifications ajoutees a make test-rom.
2026-09-24 Documentation et commentaires: le pont est la Black Pill STM32F411, plus un Arduino UNO
    Commentaires de la ROM, texte de la liste des vecteurs, README (Solution-01 et
    racine): cablage du Black Pill, section du pont, PlatformIO, port serie USB.
    Hors le texte IVT, la ROM est identique a l'octet pres.
2026-09-24 README_fr.md: page d'accueil concise du projet, avec captures du terminal
    Resume, montage, circuit (Mermaid), pont STM32, menu, BASIC, PC-DOS 2.1 et
    MS-DOS 3.30. Captures SVG produites par la ROM reelle dans le simulateur
    (medias/captures/generer.py). README.md est conserve.
2026-09-24 README_fr.md: photo du montage en tete de page
    medias/breadboard-pc.png est une photo HEIC; convertie en JPEG 1600 px
    (medias/breadboard-pc.jpg) pour l'affichage sur GitHub.
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2026-09-24 Exemples de code: hello.asm (DOS, INT 10h) et sin.bas (courbe de SIN en ASCII)
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2026-09-24 README_en.md: version anglaise de la page d'accueil, avec captures de la ROM anglaise
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2026-09-26 Mise en place du schéma
    [Breadbord-pc.kicad_pcb, Breadbord-pc.kicad_sch, temp-freerouting.dsn]
2026-09-26 Renommer les fichiers
    [.kicad_sch, .kicad_sch.kicad_sch, Breadboard-pc.kicad_pcb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]
2026-09-26 kicad/3dmodels: modele 3D du support ZIF 32 broches 3M Textool 232-1285 (STEP, VRML, generateur CadQuery)
    [DIP_Socket-32_W11.9mm_W12.7mm_W15.24mm_W17.78mm_W18.5mm_3M_232-1285-00-0602J.step]
2026-09-26 Directives: generateur du modele ZIF 32 teste avec CadQuery sous PowerShell (Python 3.14)
2026-09-26 Directives: modele 3D du ZIF 32 installe dans la bibliotheque de KiCad
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2026-09-26 8259: CS# = NAND(IO, A5) (74LS00), et non NAND(IO, A6, /A7) - documentation et commentaires corriges
    [solution-01.asm]
2026-09-26 Actualisé le PCB
    [Breadboard-pc.kicad_pcb, Breadboard-pc.kicad_sch, untitled.kicad_sch]
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2026-11-09 ROM 512 Ko par defaut; test RAM: lignes d'adresse A0-A18 et carte memoire; Edit+Run en 1000:0000
    - Makefile: RAM ?= 512 (-dRAM_512K pour toutes les ROM), rom-128/rom-128-en pour l'ancienne RAM
    - test_adressage: test des lignes d'adresse A0-A18 (capacite reelle), ram_map_print: carte memoire
    et Ko bons/defectueux, textes FR/EN
    - Edit+Run: segment fixe EDIT_RUN_SEG = 1000h (code edite en VAR_SEG mais execute en 1000:0000)
    - broches du verrou 74LS373 corrigees (A17 = 15, A18 = 16)
    - make test-rom: ROM gravee par defaut, + verifications 128K et Edit+Run
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2026-11-10 Documentation a jour, animation des signaux, schema KiCad; UTF-8 au terminal; pont 1.6 en rafale
    - README.md / README_fr.md actualises: RAM 512 Ko, DOS 2.1 a 6.22, disquettes
    1,44 Mo, decodage exact d'apres le schema, test RAM Trace/MAP, pont 1.6
    - medias/animation: animation SVG des signaux du montage (FR et EN), du RESET a
    la reponse en rafale d'INT 13h, et son generateur
    - Schema KiCad: AS6C4008 (512 Ko), A17/A18, textes a jour; image
    medias/schema-kicad.png (avec le 8259 et la RAM de 512 Ko)
    - ROM: sortie terminal d'INT 10h en UTF-8 (page de codes 437 convertie)
    - Pont 1.6: reponses envoyees en rafale (amorcage ~50 % plus rapide)
    - PC-DOS: copies des disquettes DOS 5.0 et 6.22 sans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
2026-11-10 PCB reroute (Freerouting, DRC sans erreur); sous-menu Test RAM; Clock speed: 2,35 MHz (pont 1.7)
    PCB kicad/Breadboard-pc: ancien routage retire, J2 sorti du support ZIF, classes Power/Default, routage complet par Freerouting 2.5 (0 liaison manquante, 0 violation), serigraphie corrigee. ROM: 6) Test RAM -> sous-menu Trace/MAP/Loop; Clock speed 5) 2.35 6) 4.77 7) 8.0 8) 7.2 MHz (table clock_key_action). Pont 1.7: action 8 = 2,34 MHz reels. BridgeModel: commande 2Ch simulee.
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2026-11-10 Doc: quartet haut du bus inverse et rappel RESET 4,7 kohm (R1), alignes sur le PCB
2026-11-10 PCB: 110 x 110 mm, 4 trous de fixation M3 aux coins
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2026-11-11 PCB v2: J3 au bord + cavalier JP3, J5 bus 2x20, condensateurs traversants
    - Schema: J5 (A0-A19, D0-D7, RD_, WR_, IO/M, ALE, CLK, RESET, INTR,
    INTA_, +5V, GND), JP3 entre J3 (5V_JACK) et VCC, C1-C11 traversants.
    - PCB 120 x 124,2 mm: J3 au bord droit, Black Pill degage et aligne sur
    le support ZIF (U4 entierement sur la carte), U7/U6 ecartes, U1 decale,
    condensateurs pres des broches VCC, legende de J5, VE2CUY.8088v2.
    - Regles: signaux 0,20/0,18 mm, 5V_JACK en classe Power, trou-cuivre
    0,30 mm. Routage Freerouting complet (masse routee, puis plans GND).
    DRC avec parite: 0 erreur (2 avertissements anterieurs du Black Pill).
    - La v1 commandee reste au commit a56163d (dossier fabricati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
2026-11-11 Solution-02: schema KiCad (8088/V20, 5,33 MHz, LCD 20x4), BIOS 0.1 et simulateur
    Schema valide et corrige (logique LS, alimentation de U5/U9, horloge 5,33 MHz,
    74HC573 conserves); BIOS 0.1: LCD 20x4 sans RAM, test RAM, compteur; simulateur
    unicorn (4 scenarios OK); journal Solution-02/Directives.md.
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
